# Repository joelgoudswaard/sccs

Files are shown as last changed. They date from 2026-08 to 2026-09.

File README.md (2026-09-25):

<h1>
  SCCS
  The Singularity Camper Control System
</h1>

The SCCS is a control system for the electrics in your caravan or camper trailer. It replaces a switch panel and battery/water gauges etc. with a modern touchscreen UI that provides:
- Automated control of lighting based on sunset/sunrise times and door/panel open and closes.
- Display of important information:
  - Battery level and usage
  - Solar generation
  - Water tank levels
  - Location data
  - outside/fridge temperature and weather forecasts
  - Sonos speakers

The system is made up of a Raspberry Pi and custom PCB, the SCCS Core that is the central hub where all field wiring connects to.

The SCCS software configures the Raspberry Pi as a router so that Internet can be distributed from a USB/Wi-Fi hotspot or Starlink through a downstream WAP, enabling a local Wi-Fi network that gives your devices access to the UI and provides ad-filtered Internet access.

Networking services — NAT, DNS, DHCP, and ad-filtering — are provided by nftables and Pi-hole and configured during installation. That same LAN step installs UniFi OS Server so UniFi access points can be adopted locally at `https://10.10.10.1:11443`. Apple HomeKit and Google Home can be configured to enable voice commands of lighting through Siri or Gemini. Cloudflare Tunnels is supported for remote access to the system while away from the caravan/camper.

An interactive demo is available at [demo.singularityautomation.com.au](https://demo.singularityautomation.com.au).

## Getting started

## Quickstart

1. Order SCCS Core PCB from JLCPCB by uploading the contents of the `/kicad/production` folder to JLCPCB. Get PCBA (assembly) done as well - you will receive a warning during the component placement stage that the same component is mapped to multiple parts. This is intentional, tick the checkboxes to include them in the build and continue.
2. Install wiring and SCCS core.
3. Install the software with the install command:

```bash
curl -fsSL https://raw.githubusercontent.com/joelgoudswaard/sccs/main/install.sh -o /tmp/sccs-install.sh && sudo bash /tmp/sccs-install.sh
```

Full instructions are in the [project wiki](https://github.com/joelgoudswaard/sccs/wiki/).

## System overview

A touchscreen in the kitchen or similar area shows the main user interface and is also reachable from phones or tablets on the LAN:

- Dimmable lighting sliders with red/white anti-bug mode and on/off buttons for non-dimmable loads (water, lighting, fridge circuits)
- Ambient lights that fade on as it gets dark
- One-touch lighting scenes
- Control of Sonos speakers
- Light/dark UI themes and an extensive settings page
- Integration with Apple HomeKit and Google Home

## Display of Environmental information

- Water tank level
- Current temperature and fridge/freezer temperatures
- Current battery charge, voltage, current consumption, estimated power remaining and current/daily solar generation
- GPS coordinates, closest suburb, altitude, satellite quality, sunrise/sunset, and the day/evening/night timing that drives automation
- 4 Day weather forecast, humidity and expected overnight temperature if Internet is present
- Internet connection quality details
- What lights are on and what doors or panels are open
- Health status of connected hardware modules like solar or GPS

## Hardware architecture

- Raspberry Pi 4/5
- Dual ESP32-S3s for 16 channels of PWM dimming via MOSFETs
- u-blox NEO-M9N GPS for location data
- Victron SmartShunt and SmartSolar support for battery and solar monitoring
- WS281X addressable LED strip outputs
- 10A relays for non-dimmable loads like lighting circuits, floodlights and water pumps
- Reed switch inputs for door/panel sensing and triggering of lights
- 1-Wire bus for temperature sensors
- Water tank level sensor input
- Spare channels for everything for expansion

## Hardware and User Interface

### SCCS Core

<table>
  <tr>
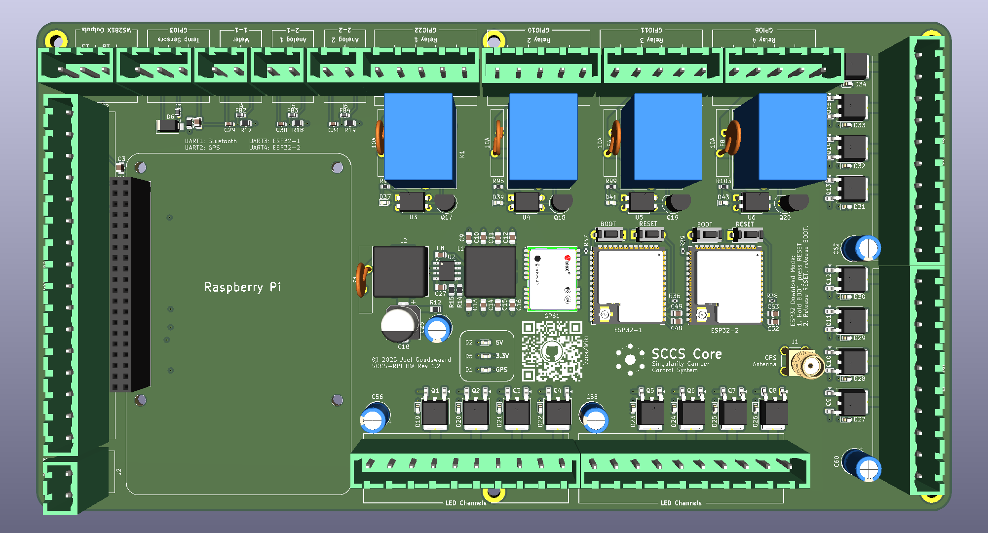
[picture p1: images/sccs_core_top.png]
SCCS Core — top, bare board
    <td align="center" width="50%"></td>
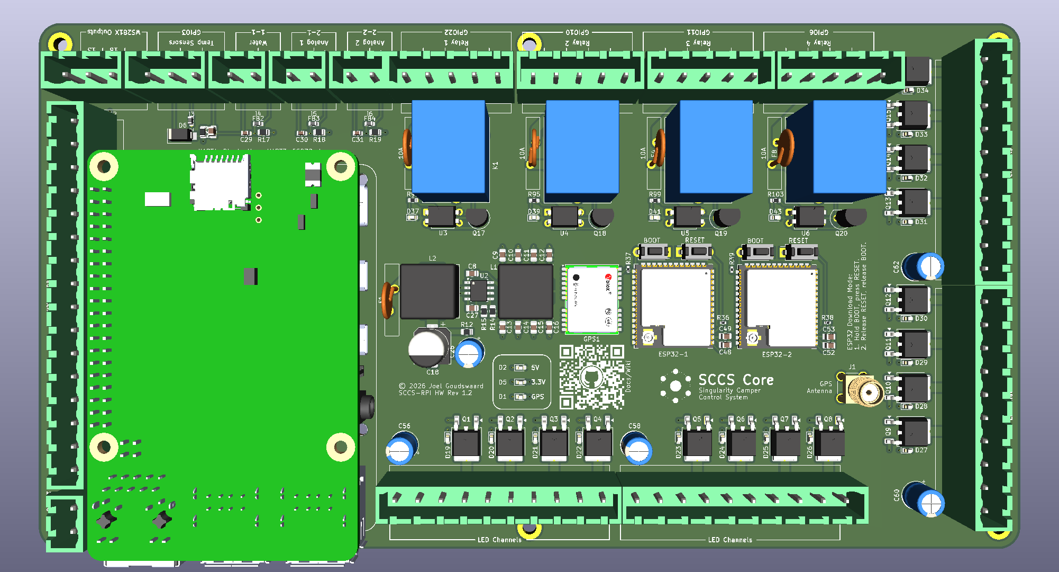
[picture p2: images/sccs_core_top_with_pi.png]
SCCS Core — top, with Raspberry Pi fitted
    <td align="center" width="50%"></td>
  </tr>
  <tr>
    <td align="center"><strong>Top (bare board)</strong></td>
    <td align="center"><strong>Top (with Raspberry Pi fitted)</strong></td>
  </tr>
  <tr>
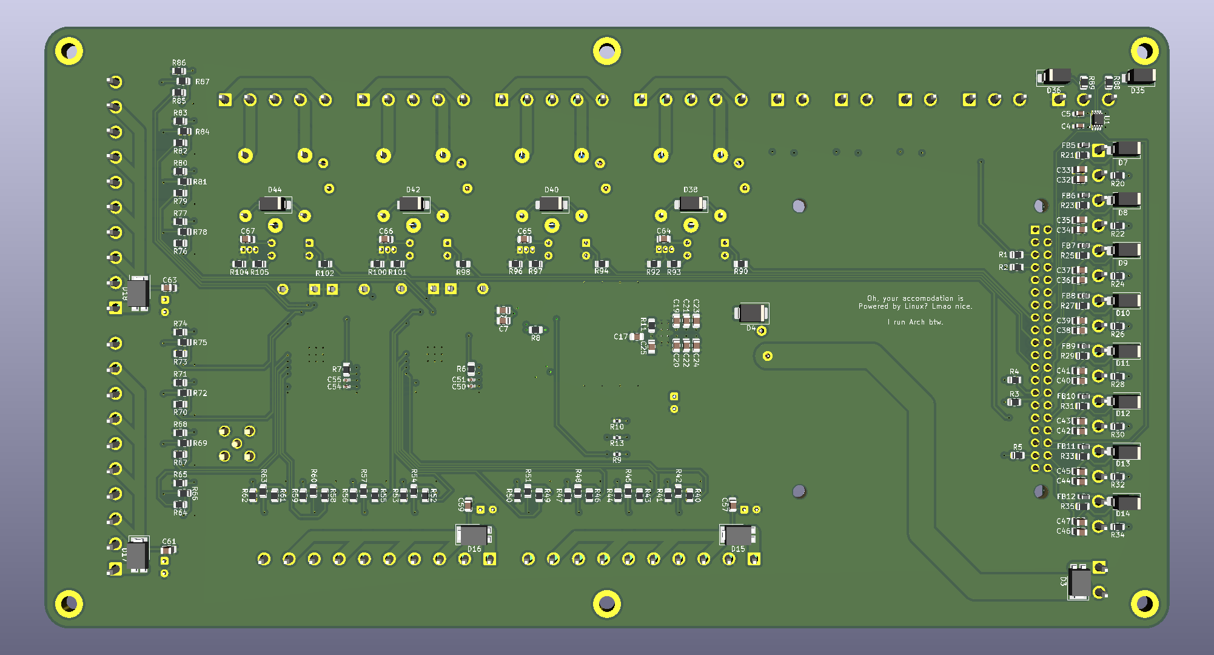
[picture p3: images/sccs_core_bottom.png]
SCCS Core — bottom
    <td align="center"></td>
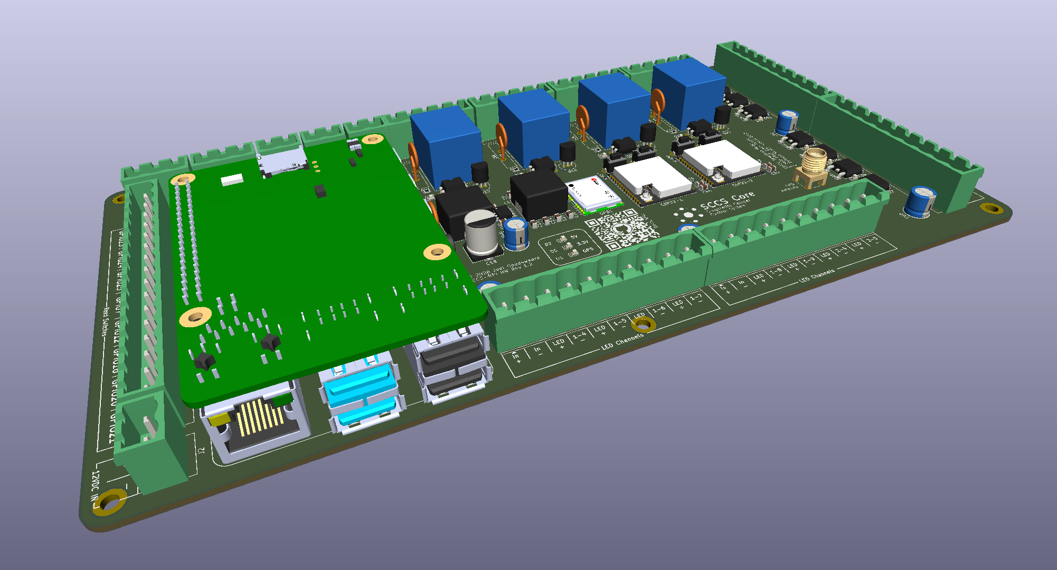
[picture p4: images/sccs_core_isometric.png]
SCCS Core — isometric view with Raspberry Pi fitted
    <td align="center"></td>
  </tr>
  <tr>
    <td align="center"><strong>Bottom</strong></td>
    <td align="center"><strong>Isometric (with Raspberry Pi fitted)</strong></td>
  </tr>
</table>

### 3D Printable Mount

<table>
  <tr>
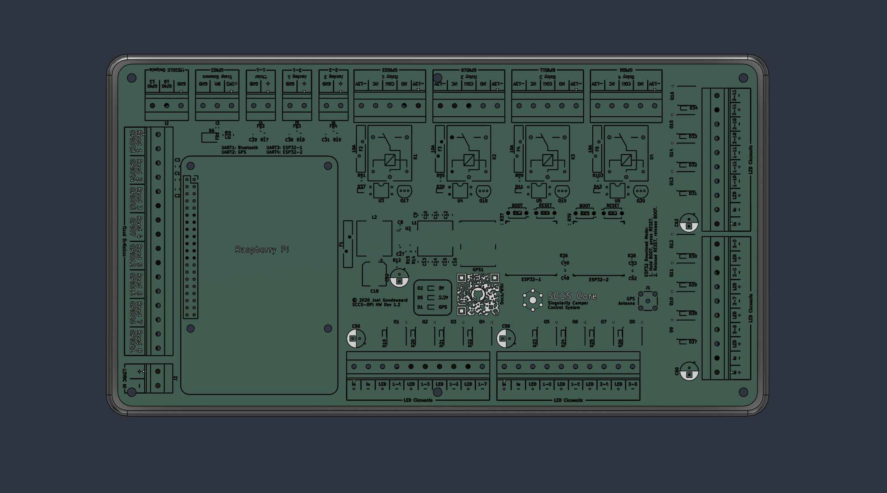
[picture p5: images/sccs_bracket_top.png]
SCCS Core — 3D printable frame, top
    <td align="center" width="50%"></td>
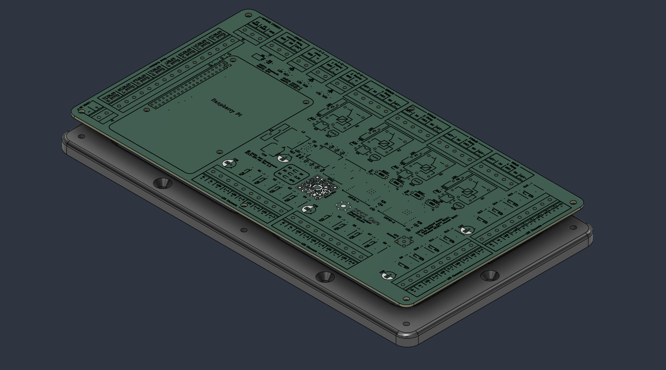
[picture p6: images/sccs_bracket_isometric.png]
SCCS Core — 3D printable frame, isometric
    <td align="center" width="50%"></td>
  </tr>
  <tr>
    <td align="center"><strong>3D printable frame (top)</strong></td>
    <td align="center"><strong>3D printable frame (isometric)</strong></td>
  </tr>
</table>

### User Interface

<table>
  <tr>
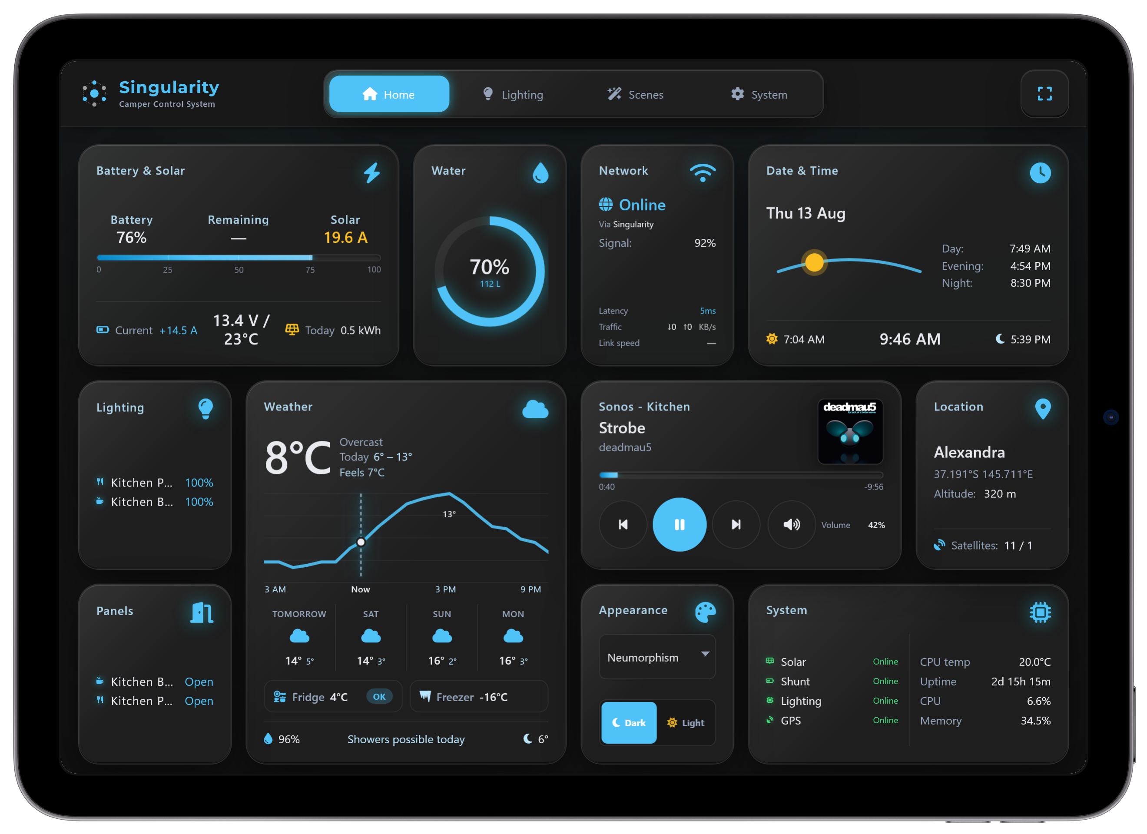
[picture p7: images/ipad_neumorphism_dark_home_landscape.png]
Neumorphism dark — iPad landscape
    <td align="center" width="50%"></td>
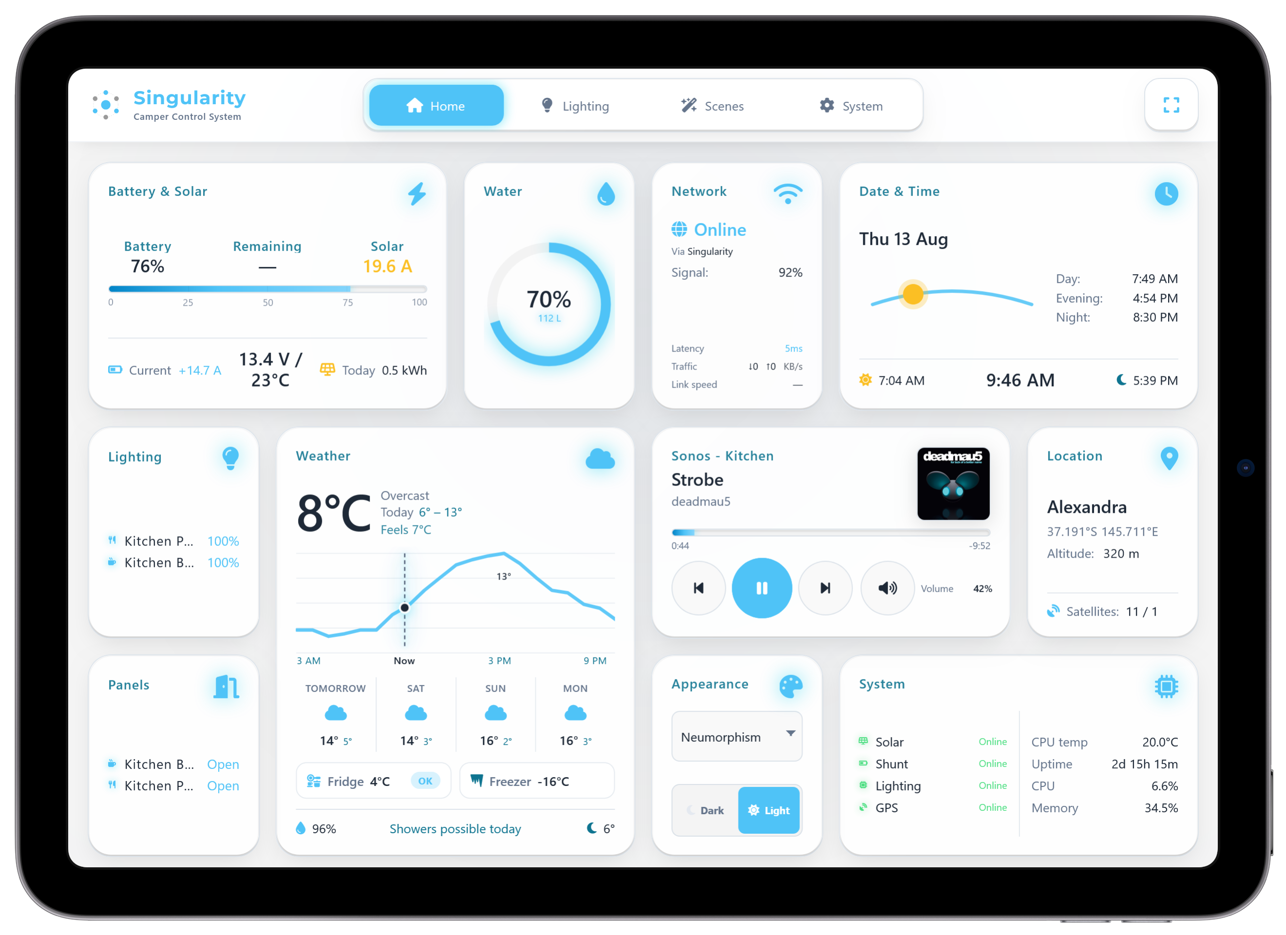
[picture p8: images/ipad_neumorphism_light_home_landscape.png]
Neumorphism light — iPad landscape
    <td align="center" width="50%"></td>
  </tr>
  <tr>
    <td align="center"><strong>Neumorphism (Dark) — iPad</strong></td>
    <td align="center"><strong>Neumorphism (Light) — iPad</strong></td>
  </tr>
  <tr>
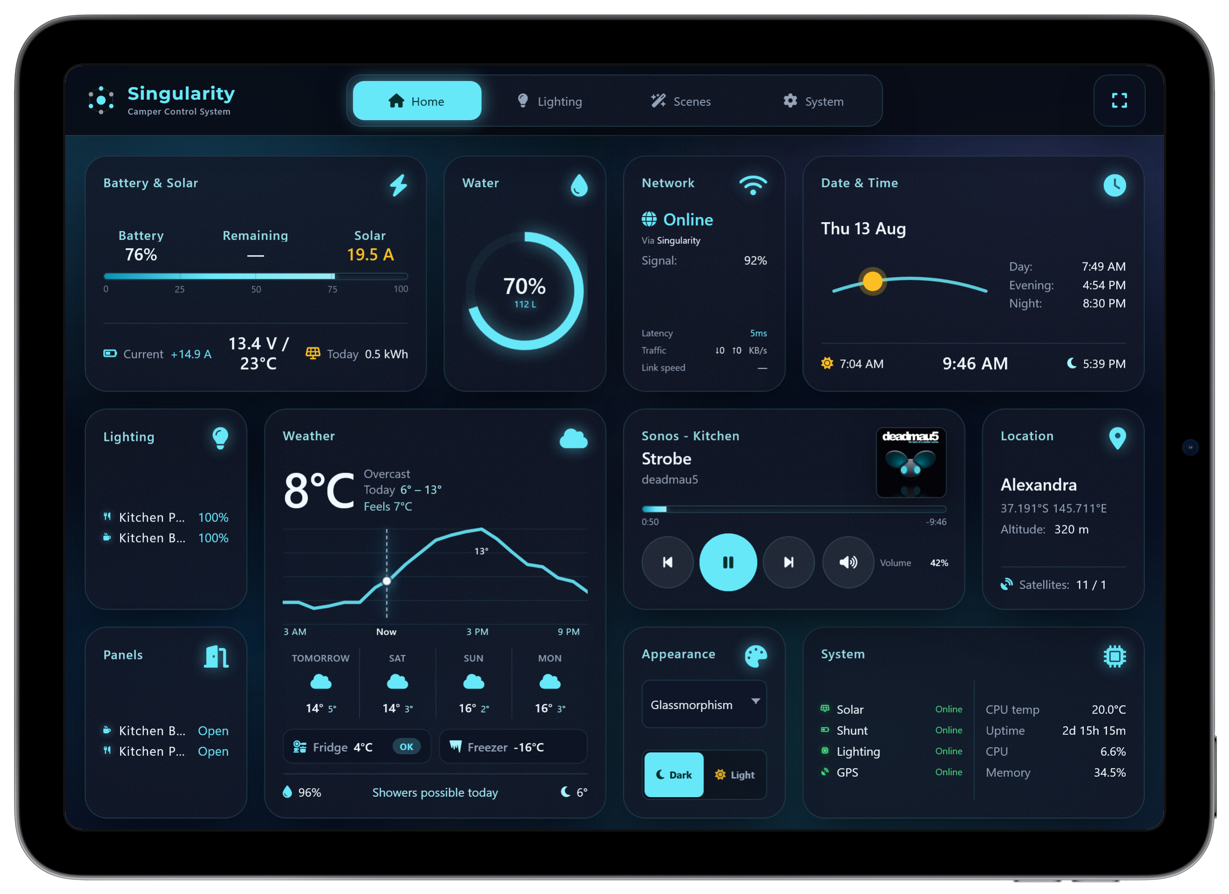
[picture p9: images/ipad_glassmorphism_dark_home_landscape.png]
Glassmorphism dark — iPad landscape
    <td align="center"></td>
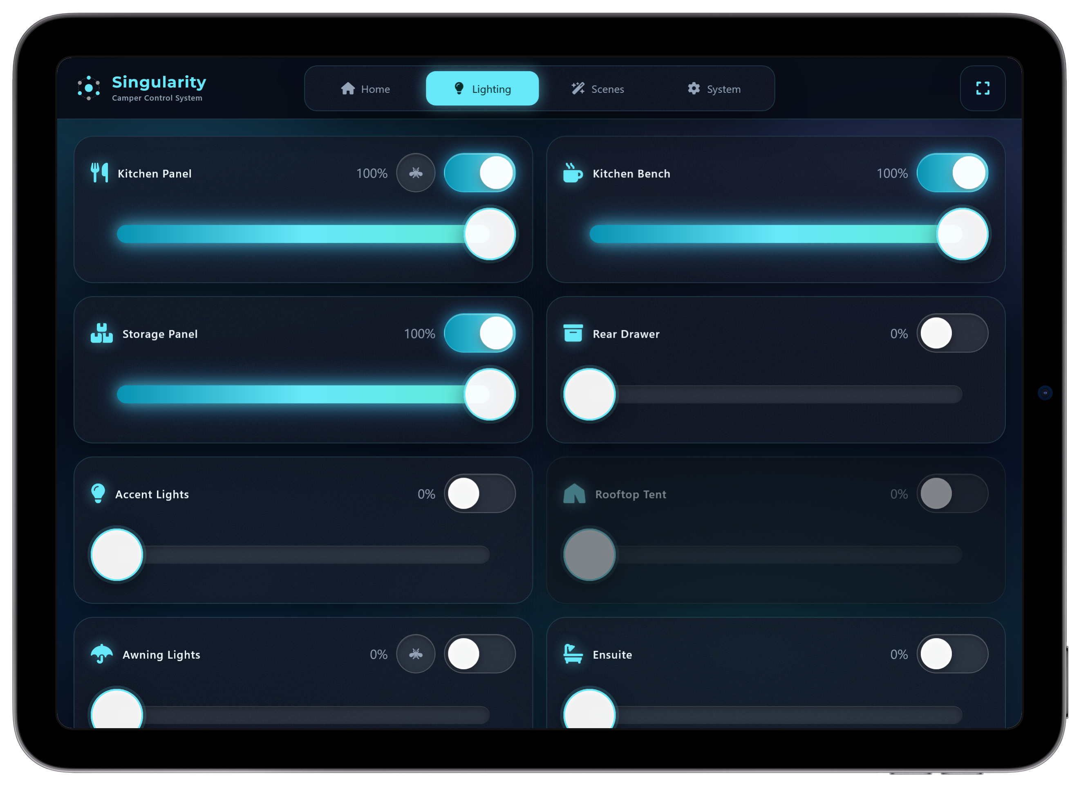
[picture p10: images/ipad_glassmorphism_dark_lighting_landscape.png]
Glassmorphism dark — iPad lighting
    <td align="center"></td>
  </tr>
  <tr>
    <td align="center"><strong>Glassmorphism (Dark) — iPad</strong></td>
    <td align="center"><strong>Glassmorphism (Dark) — iPad Lighting</strong></td>
  </tr>
  <tr>
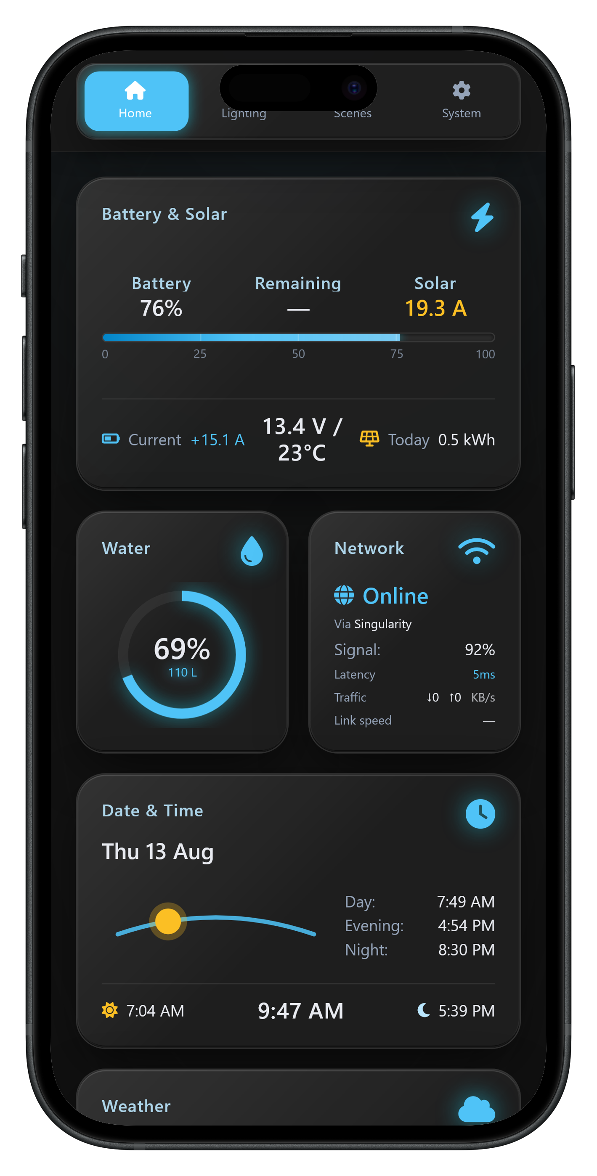
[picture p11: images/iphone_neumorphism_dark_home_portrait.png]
Neumorphism dark — iPhone portrait
    <td align="center"></td>
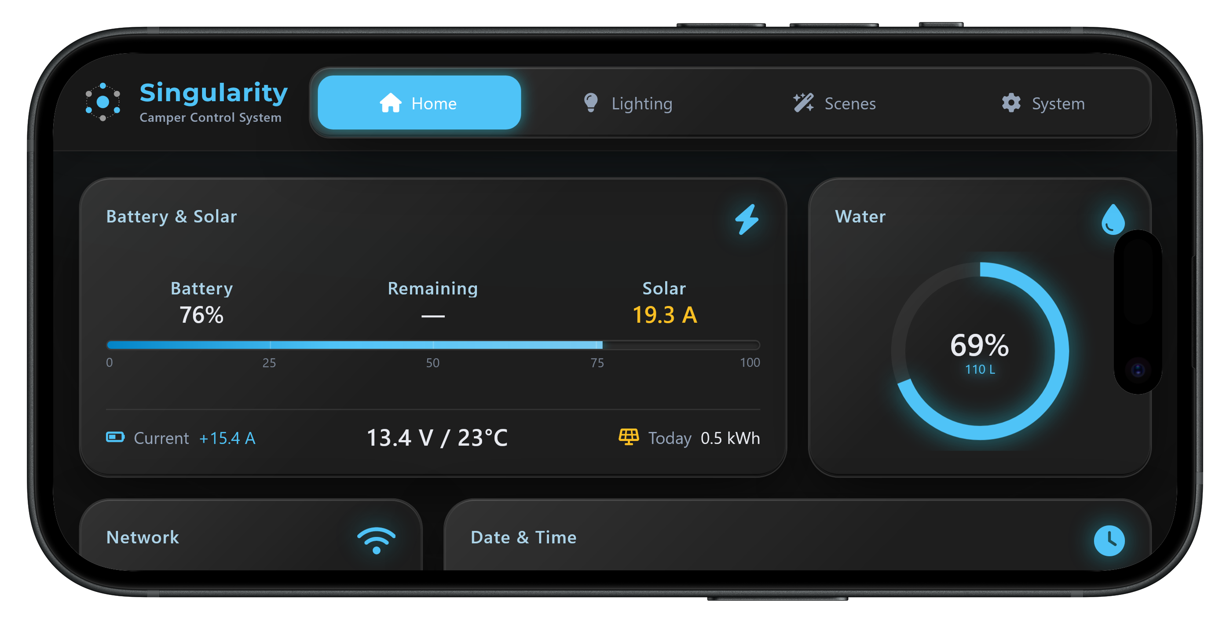
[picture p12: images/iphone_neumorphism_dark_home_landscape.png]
Neumorphism dark — iPhone landscape
    <td align="center"></td>
  </tr>
  <tr>
    <td align="center"><strong>Neumorphism (Dark) — iPhone Portrait</strong></td>
    <td align="center"><strong>Neumorphism (Dark) — iPhone Landscape</strong></td>
  </tr>
</table>

---

## Documentation

Wiring, installation, configuration, and optional packages are on the **[project wiki](https://github.com/joelgoudswaard/sccs/wiki)** (start at [Home](https://github.com/joelgoudswaard/sccs/wiki/Home) for the setup path and glossary).

| Topic | Wiki page |
|---|---|
| Overview, setup path, glossary | [Home](https://github.com/joelgoudswaard/sccs/wiki/Home) |
| Shopping list and wiring | [Wiring and Hardware](https://github.com/joelgoudswaard/sccs/wiki/Wiring-and-Hardware) |
| Imaging the Pi and installer | [Software Installation](https://github.com/joelgoudswaard/sccs/wiki/Software-Installation) |
| `sccs.conf`, phases, lights, sensors | [Software Configuration](https://github.com/joelgoudswaard/sccs/wiki/Software-Configuration) |
| SmartShunt / SmartSolar Bluetooth | [Victron Setup](https://github.com/joelgoudswaard/sccs/wiki/Victron-Setup) |
| Apple Home app / Siri (optional) | [HomeKit](https://github.com/joelgoudswaard/sccs/wiki/HomeKit) |
| Google Home / Gemini (optional) | [Google Home](https://github.com/joelgoudswaard/sccs/wiki/Google-Home) |
| LAN, NAT, Pi-hole, USB internet | [Networking](https://github.com/joelgoudswaard/sccs/wiki/Networking) |
| UniFi controller (optional) | [UniFi OS Server](https://github.com/joelgoudswaard/sccs/wiki/UniFi-OS-Server) |

---

## License

Licensed under the [MIT License](LICENSE).

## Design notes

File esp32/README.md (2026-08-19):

# SCCS ESP32-S3 firmware

ESP32-S3-WROOM-1U firmware for the two lighting/analog MCUs.

Host protocol (UART0, 115200 8N1): `SET` / `RAMP` / `GET` / `ANALOG` / `GETVCC` / `GETALL`.

Same UART as the ROM bootloader, so `BOOT`+`RESET` uploads over the Pi host serial port.

| Sketch | Role | Pi UART | ESP host UART | PWM GPIOs | Analog GPIOs |
|---|---|---|---|---|---|
| `esp32_1/` | ESP32-1 | `/dev/ttyAMA2` (Pi GPIO 4/5) | GPIO 44 RX / 43 TX (U0) | 4–11 | 1 (water) |
| `esp32_2/` | ESP32-2 | `/dev/ttyAMA3` (Pi GPIO 8/9) | GPIO 44 RX / 43 TX (U0) | 4–11 | 1, 2 |

Shared core: `SccsEspFirmware.h` (copied into each sketch folder).

## Build / flash

- Chip: **ESP32-S3** / **ESP32-S3-WROOM-1U**
- Upload over the Pi host UART (U0). Stop `sccs` first so the port is free.
- Hold BOOT, tap RESET, release BOOT, then upload. Tap RESET again to run.

```bash
arduino-cli core update-index
arduino-cli core install esp32:esp32

arduino-cli compile --fqbn esp32:esp32:esp32s3 esp32/esp32_1
arduino-cli upload -p /dev/ttyAMA2 --fqbn esp32:esp32:esp32s3 esp32/esp32_1

arduino-cli compile --fqbn esp32:esp32:esp32s3 esp32/esp32_2
arduino-cli upload -p /dev/ttyAMA3 --fqbn esp32:esp32:esp32s3 esp32/esp32_2
```

## ADC / water level

- 12-bit reads (0–4095), 64-sample average — matches `water_adc_max = 4095` on the Pi
- `GETVCC` returns `3300` (mV of the 3V3 rail for the 150 Ω pull-ups)
- Water sender on ESP32-1 GPIO 1: empty ~240 Ω, full ~33 Ω (`config/sccs.conf` `[sensors]`)

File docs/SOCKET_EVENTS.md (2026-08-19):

# SCCS Socket Event Contract

This document defines every Socket.IO event used by the lighting backend in this pass.

## Offline overlay

When Socket.IO disconnects (or fails to load), `#offline-overlay` appears after 800ms and blocks interaction until reconnect. Implemented in `offline-overlay.js` + `socket-client.js`.

## Client → Server

### `light_change`

User moved a dimmer slider or toggled a dimmer pill.

```json
{ "name": "kitchen_bench", "brightness": 65 }
```

RGB bug lights include mode:

```json
{ "name": "kitchen_panel", "brightness": 55, "mode": "red" }
```

- `name` must be in `compiled.light_names`
- `brightness` clamped 0–100 server-side
- `mode` only applied for RGB lights

**HTTP fallback:** `POST /api/light` with the same JSON body.

### `relay_change`

User toggled a relay control (socket only — no HTTP fallback).

```json
{ "name": "floodlights", "on": true }
```

Relays use `expires: manual` — they persist through scenes, reed changes, and phase changes until toggled again.

### `get_reeds`

Request effective reed states. Server replies with `reed_update`.

### `set_scene`

Activate a lighting scene (one-shot reconcile with ramp).

```json
{ "scene": "bedtime" }
```

**HTTP fallback:** `POST /api/scene` with the same JSON body.

### `force_phase`

Lock or clear phase override.

```json
{ "phase": "Evening" }
```

Clear: `{ "phase": null }`

### `force_reed`

Diagnostics override (also affects main UI effective states).

```json
{ "name": "rooftop_tent", "closed": true }
```

Clear force: `{ "name": "rooftop_tent", "closed": null }`

## Server → Client

### `lights_config`

Sent on `connect`. Ordered list of UI controls from `sccs.conf`:

```json
[
  { "name": "rooftop_tent", "label": "Rooftop Tent", "type": "dimmer", "icon": "fa-tent", "has_mode": false, "order": 10 }
]
```

`type` is `dimmer` or `relay`.

### `state_update`

Authoritative light/relay levels after reconcile.

```json
{
  "kitchen_bench": 65,
  "kitchen_panel": 55,
  "kitchen_panel_mode": "white",
  "floodlights": 1
}
```

- Dimmers: 0–100 integer brightness
- Relays: truthy/falsey on state
- RGB lights: `{name}_mode` key with `white` or `red`

### `reeds_config`

Sent on `connect`. Reed metadata for the system tile:

```json
[{ "name": "kitchen_panel", "label": "Kitchen Panel", "icon": "fa-utensils", "order": 10 }]
```

### `reed_update` (main UI)

Effective reed states — hardware merged with operator forces.

```json
{ "states": { "rooftop_tent": true, "kitchen_bench": false } }
```

`true` = closed (secure), `false` = open.

**Main UI rule:** clients must not guess forced vs raw. Use this event only.

### `reed_diag_update` (diagnostics — future tile)

Raw hardware + force metadata. Not consumed by the lighting tab yet.

```json
{
  "states": { "rooftop_tent": true },
  "forced": { "kitchen_bench": false }
}
```

### `phase_update` (main UI)

```json
{ "phase": "evening", "day_start": "06:12", "evening_start": "18:45", "night_start": "21:30" }
```

### `gps_update`

Full GPS telemetry from `modules/gps` (also drives home location tile).

```json
{
  "fix_quality": 2,
  "satellites": 9,
  "latitude": -37.191,
  "longitude": 145.711,
  "suburb": "Alexandra",
  "hardware_missing": false
}
```

### `sensor_update`

Water tank and 1-wire temperatures.

```json
{
  "water_percent": 68,
  "outside_temp_c": 12.4,
  "fridge_temp_c": null,
  "temp_valid": true
}
```

### `set_gps_simulation`

Diagnostics: force no-fix mode.

```json
{ "no_fix": true }
```

### `phase_diag_update` (diagnostics)

```json
{ "forced": false }
```

`forced: true` when operator has locked phase via diag controls.

## REST

| Route | Purpose |
|---|---|
| `POST /api/light` | HTTP fallback for `light_change` |
| `GET /api/scenes` | Scene list for Scenes tab |
| `POST /api/scene` | HTTP fallback for `set_scene` |
| `GET /api/reeds` | Reed labels/icons for system tile |
| `GET /api/explain` | Policy snapshot: sources, desired vs observed, drift |

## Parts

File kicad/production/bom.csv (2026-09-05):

Designator | Footprint | Quantity | Value | LCSC Part #
C1, C10 | 0805 | 2 | 10uF | C15850
C11, C17, C2, C22, C24, C26, C28, C30, C32, C34, C36, C46, C48, C50, C52, C53, C54, C55, C56, C8 | 0805 | 20 | 100nF | C49678
C12, C13, C14, C15, C3, C37, C41, C58, C59, C6, C60, C61, C62, C63, C64, C65, C70, C71, C72, C73, C74, C75, C76, C77 | 0805 | 24 | 22uF | C86816
C16, C45, C47, C49, C51 | CP_Radial_D6.3mm_P2.50mm | 5 | 100uF | C44587
C18, C19, C20, C4, C5 | 0603 | 5 | 100nF | C1590
C21, C23, C25, C27, C29, C31, C33, C35 | 0805 | 8 | 1uF | C91185
C38, C42, C57, C69, C7 | 0805 | 5 | 0.1uF | C86041
C39, C40, C43, C44 | 0402 | 4 | 100nF | C60474
C66, C78 | 0805 | 2 | 2.7nF | C113859
C67, C79 | 0805 | 2 | 33pF | C541516
C68, C80 | 0805 | 2 | 10nF | C237168
C9 | CP_Elec_8x10 | 1 | 220uF | C165536
D1 | 0402 | 1 | ESD103-B1-02EL | C535146
D10, D11, D12, D13, D14, D15, D7, D8, D9 | D_SMA | 9 | SMAJ3.3CA | C18199545
D16, D17, D18, D19, D4 | D_PowerDI-5 | 5 | ~ | C2759901
D2 | 0603 | 1 | GPS | C2286
D20, D23, D24, D25, D26, D27, D28, D31, D32, D33, D34, D35 | 0603 | 12 | White | C2290
D21, D29 | 0603 | 2 | Red | C2286
D22, D30 | 0603 | 2 | Green | C12065
D3 | 0603 | 1 | 5V | C2286
D36, D37 | D_SMA | 2 | SMAJ5.0CA | C78402
D38, D40, D42, D44 | 0603 | 4 | Blue | C2288
D39, D41, D43, D45 | D_SMA | 4 | 1N4007 | C64915
D5 | D_SMB | 1 | SMAJ18A/TR13 | C571369
D6 | 0603 | 1 | 3.3V | C2286
ESP32-1, ESP32-2 | ESP32-S3-WROOM-1U | 2 | ESP32-S3-WROOM-1 | C3013946
F1, F2, F3, F4, F5 | Fuse_Bourns_MF-RG1000 | 5 | A16-1000 10A | C135398
FB1, FB10, FB11, FB12, FB2, FB3, FB4, FB5, FB6, FB7, FB8, FB9 | 0603 | 12 | FerriteBead | C1002
GPS1 | ublox_NEO | 1 | NEO-M9N-00B | C5119087
I1 | TerminalBlock_Phoenix_MKDS-1,5-16-5.08_1x16_P5.08mm_Horizontal | 1 | Reed Switches | C508906
I2 | TerminalBlock_Phoenix_MKDS-1,5-3-5.08_1x03_P5.08mm_Horizontal | 1 | WS281X Outputs | C8412
I3 | TerminalBlock_Phoenix_MKDS-1,5-3-5.08_1x03_P5.08mm_Horizontal | 1 | Temp Sensors | C8412
I4 | TerminalBlock_Phoenix_MKDS-1,5-2-5.08_1x02_P5.08mm_Horizontal | 1 | Water | C8445
I5 | TerminalBlock_Phoenix_MKDS-1,5-2-5.08_1x02_P5.08mm_Horizontal | 1 | Analog 1 | C8445
I6 | TerminalBlock_Phoenix_MKDS-1,5-2-5.08_1x02_P5.08mm_Horizontal | 1 | Analog 2 | C8445
J1 | SMA_Amphenol_132134-11_Vertical | 1 | Conn_Coaxial | C20415804
J2 | TerminalBlock_Phoenix_MKDS-1,5-2-5.08_1x02_P5.08mm_Horizontal | 1 | 12VDC IN | C8445
K1, K2, K3, K4 | Relay_SPDT_SANYOU_SRD_Series_Form_C | 4 | Relay_SPDT | C35449
L1 | 0603 | 1 | 27nH | C162550
L2, L3, L4 | L_SXN_SMDRI127 | 3 | 3.3uH | C24550
PI1 | PinSocket_2x20_P2.54mm_Vertical | 1 | Raspberry PI HAT | C132132
PWM1, PWM2, PWM3, PWM4 | TerminalBlock_Phoenix_MKDS-1,5-10-5.08_1x10_P5.08mm_Horizontal | 4 | LED Channels | C29173
Q1, Q10, Q11, Q12, Q13, Q14, Q15, Q16, Q2, Q3, Q4, Q5, Q6, Q7, Q8, Q9 | TO-252-2 | 16 | IRLR7843 | C21988
Q17, Q18, Q19, Q20 | TO-92_Inline | 4 | 2N7000 | C9114
R1, R19, R2, R21, R23, R25, R27, R29, R3, R31, R33, R4, R6, R7, R9 | 0805 | 15 | 220R | C17557
R10, R11, R13 | 0402 | 3 | 1K | C11702
R100, R88, R92, R96 | 0805 | 4 | 330R | C17630
R101, R89, R93, R97 | 0603 | 4 | 1K | C5123612
R102, R39, R42, R45, R48, R51, R54, R57, R60, R63, R66, R69, R72, R75, R78, R81, R84, R90, R94, R98 | 0805 | 20 | 10K | C17414
R103, R38, R41, R44, R47, R50, R53, R56, R59, R62, R65, R68, R71, R74, R77, R80, R83, R91, R95, R99 | 0805 | 20 | 100R | C17408
R104, R107 | 0805 | 2 | 15.8K | C17468
R105 | 0805 | 1 | 115K | C158272
R106 | 0805 | 1 | 22.1K | C17552
R108 | 0805 | 1 | 100K | C5123589
R109 | 0805 | 1 | 32.4K | C36938
R12 | 0805 | 1 | 1R | C25271
R14 | 0805 | 1 | 2.2K | C17520
R15, R16, R17 | 0805 | 3 | 150R | C17471
R18, R20, R22, R24, R26, R28, R30, R32, R5 | 0805 | 9 | 4.7K | C17673
R34, R35, R36, R37 | 0402 | 4 | 10K | C60490
R40, R43, R46, R49, R52, R55, R58, R61, R64, R67, R70, R73, R76, R79, R82, R85 | 0805 | 16 | 1K | C17513
R8 | 0805 | 1 | 10R | C17415
R86, R87 | 0805 | 2 | 33R | C17634
RE1 | TerminalBlock_Phoenix_MKDS-3-5-5.08_1x05_P5.08mm_Horizontal | 1 | Relay 1 | C8423
RE2 | TerminalBlock_Phoenix_MKDS-3-5-5.08_1x05_P5.08mm_Horizontal | 1 | Relay 2 | C8423
RE3 | TerminalBlock_Phoenix_MKDS-3-5-5.08_1x05_P5.08mm_Horizontal | 1 | Relay 3 | C8423
RE4 | TerminalBlock_Phoenix_MKDS-3-5-5.08_1x05_P5.08mm_Horizontal | 1 | Relay 4 | C8423
RP? | raspberrypi_4 | 1 | Raspberry_Pi_2_3
SW1, SW3 | SW_PUSH_1P1T_6x3.5mm_H5.0_APEM_MJTP1250 | 2 | RESET | C500070
SW2, SW4 | SW_PUSH_1P1T_6x3.5mm_H5.0_APEM_MJTP1250 | 2 | BOOT | C500070
U1 | VSSOP-8_2.3x2mm_P0.5mm | 1 | SN74LVC2T45DCUR | C15741
U2, U3, U4, U5 | DIP-4_W7.62mm | 4 | PC817 | C5353
U6, U7 | SOIC-8-1EP_3.9x4.9mm_P1.27mm_EP2.95x4.9mm_Mask2.71x3.4mm_ThermalVias | 2 | AP64501SP-13 | C2071517

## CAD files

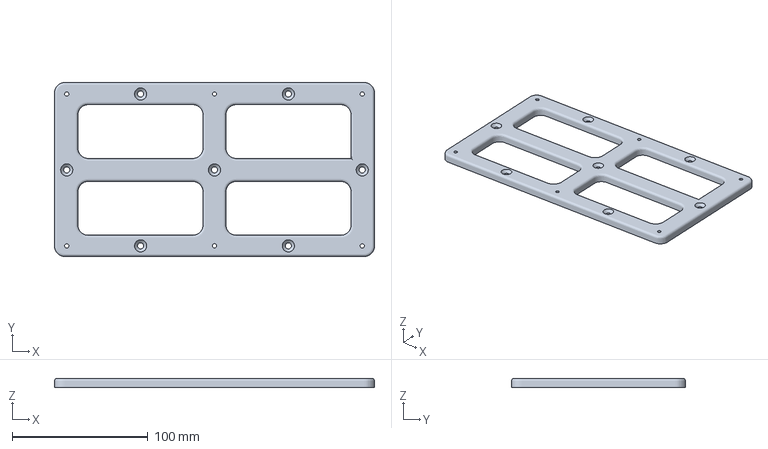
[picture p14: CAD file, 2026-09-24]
kicad/SCCS Bracket.3mf
236.1 x 128.4 x 7.00 mm

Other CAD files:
kicad/SCCS Bracket.f3z

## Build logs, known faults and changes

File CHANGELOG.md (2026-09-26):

# Changelog

All notable changes to SCCS are documented in this file.

## [1.2.0.26092026] - 2026-09-26

### Added
- Update (menu 2 / `--update`) checks UniFi OS Server against Ubiquiti's release feed and runs the official installer when a newer version is published. An install that is already current is left alone. The controller restarts during the upgrade; adopted access points and the Podman volumes stay. The container DNS fix is applied again afterwards.
- Touchscreen setup logs the panel account into the desktop at boot on Raspberry Pi OS and Armbian. Raspberry Pi OS uses desktop autologin. Armbian uses LightDM, SDDM, GDM, or greetd, whichever is installed. The account password is unchanged, and the login applies on the next boot.
- Touchscreen setup turns off idle display power saving on Raspberry Pi OS and Armbian. The panel no longer blanks, dims, or sleeps after a period with no input. Brightness from the reed and the time of day is unchanged. Armbian KDE Plasma is included. Menu 8 applies desktop login, the Chromium homepage, and idle-power off to every touchscreen already in the config.

### Fixed
- Kitchen touchscreen setup writes `kscreen:HDMI-A-1` as the power path. The panel turns fully on when the kitchen panel reed opens and off when it closes. The installer was storing the KDE brightness control, which only dimmed the screen through the day (100%), evening (30%), and night (5%).
- Each touchscreen card has a "Change Brightness with Phases" checkbox. Off, an open reed leaves the panel fully on. On, it uses that screen's day, evening, and night levels (kitchen: 100 / 30 / 5). The choice is saved in `sccs.conf`.
- Kitchen bench night is 10% red. It was off.
- Dragging a lighting slider thumb no longer opens the browser right-click menu. A press on the thumb is a drag.
- Neumorphism cards keep the halfway highlight. Panel Chromium composites on the GPU and rasterizes on the CPU, so that gradient stays a smooth ramp and page and fullscreen changes are not a two-frame jump. The Neumorphism tile blur is off; the tiles are already nearly opaque, and the blur was re-painted on every fade.
- Closing the kitchen panel reed powers the touchscreen off. Brightness 0% only dimmed it. Wake turns the panel back on at the phase brightness.
- After a reboot the van LAN address could sit on the iPhone USB tether instead of the touchscreen port. Pi-hole then had nothing to lease from, so the panel came up with no address. The LAN profile is now pinned to that port’s name and MAC, and a phone tether is never treated as the van LAN.
- Victron setup offers the enrolled SmartShunt and MPPT Instant Readout keys as suggestions. Press Enter to use that device's key, or type 1 or 2. Those keys are the defaults in a new install.
- Touchscreen setup saves the panel account password in ~/.sccs/screen_credentials (mode 600). Later setup and package updates reuse it. The password is not written into sccs.conf. SSH itself still uses the key.
- Setup reads GPIO26, the SCCS Core presence pull-up (header pin 37, R5 to 3.3V). When that pin is high it skips the “is this Pi on the SCCS Core?” question and asks to proceed.
- Date & Time sunrise and sunset icons are half the height of the label and time together, and stay centered on those two lines.
- The home Lighting tile lists dimmable lights that are on, then a horizontal line, then relays that are on.
- The first touchscreen scan after Pi-hole DHCP is installed asks for every panel to be restarted, then waits for confirmation before detection. Panels that were already on have no address from the new server until they boot again.
- Install questions for the SCCS Core, Victron, phone USB tethering, touchscreens, and HomeKit or Google Home default to yes.
- Voice setup asks whether to install Apple HomeKit / Siri or Google Home / Gemini, then which one: HomeKit, Google, or both. HomeKit installs on its own. Node.js and the Matter bridge install when Google Home is chosen.
- HomeKit and Google Home pairing copy now says to use your iPhone or Android instead of the van Wi‑Fi.
- Date & Time sunrise and sunset labels now start in line with the time, and the sun and moon icons span that label and the time.
- Configuring temperature sensors or touchscreens left the running service on the old `sccs.conf` until something else restarted it. Those steps now restart `sccs.service` when it is already running, after the config for that step is saved.
- First-run ESP32 flashing waited on `/dev/ttyAMA2` and `/dev/ttyAMA3` before the UART overlays were active, so the chips were not detected until the Pi was restarted. The installer now loads those overlays on the running system, and when the kernel only creates the ports at startup it restarts and continues the install instead of asking for the BOOT button.
- A mismatched Samba password confirmation ended the share setup. The installer asks again until the two entries match, or both are left blank to skip.
- Victron setup saved a MAC and Instant Readout key without checking them. The installer now listens for each device, prints a live reading when the key decrypts, and offers to retype the credentials when the key does not match or the device is not heard.
- Touchscreen scan listed every LAN client. It now keeps hosts whose SSH banner is Debian, Ubuntu, Raspbian, or Armbian. A new panel's suggested internal name is `kitchen` and its friendly name is `Kitchen Touchscreen`.
- Panel SSH setup could reject a correct password: the setup script was passed on sudo's stdin, so ssh read that text instead of the password, and the password prompt itself was not taken from the terminal. The script is now a file, ssh is detached from the terminal, and the password is read from the keyboard.
- Temperature-sensor assignment ran before the 1-Wire bus existed, so a first install skipped it without asking. The bus is brought up first, the step asks to scan again when nothing is present, and it runs after the boot overlays are in place.
- Default lighting map: kitchen bench is bug-mode on 1-7 white, 1-8 red, 1-9 green. Accent is 1-10, rear drawer 1-11, storage panel 2-4, rooftop tent 2-5. Relays are Floodlights (GPIO22), Water (GPIO10), Lights (GPIO11), and Fridge/Oven (GPIO6).
- The date tile moon started on the right when Evening began. Evening starts before sunset, and the moon was still on the daytime arc until sunset, then jumped to the left. It now starts on the left at evening and walks toward midnight at the crest.
- Date & Time footer shows Sunrise and Sunset above those times.
- Startup turns the Lights relay on when any dimmer is already on, or when startup is about to turn one on. The relay GPIOs come up off, so those lights would otherwise have no power.
- While running, a change from every dimmer off to any light on also turns the Lights relay on. `lighting_relay_on_with_lights` in `[lighting]` controls this and the startup behavior. Default is on.
- Dragging a dimmer to a new level could leave the lights there while the slider jumped back. The UI treats the reply as an animation and was applying that animation on top of the level just set; a drag now stays put until a phase, reed, or scene change moves it.
- On a 1280×800 touchscreen the home lighting list grew the page. Lighting is two columns wide and lists its lights in two columns; System is one column, without the host-status column, so the three rows stay on the screen.
- In the two-column lighting layout the last two relays (Lights and Fridge/Oven) were left as separate tiles, so Fridge/Oven wrapped onto its own row. They stack in one tile, beside Floodlights and Water.
- The home Network tile named the Wi-Fi network whenever it was associated, even when the default route was the USB hotspot. It now names the path that is actually carrying traffic.
- Victron setup listens for Instant Readout and fills in the Bluetooth address for a single SmartShunt and a single MPPT. The 32-character key still has to be pasted from VictronConnect; it is not in the broadcast.
- A new install prefers Wi-Fi for internet. Phone USB tethering is still set up when asked, as the fallback route.
- On the two- and three-column System page, SCCS Core no longer draws platform names over their values: memory and platform each use the full tile width, and long values stay in their own column. Night’s start time lines up with the Day and Evening fields.

## [1.1.2.18082026] - 2026-08-18

### Added
- Installer 1-Wire setup can delete a temperature sensor role from `sccs.conf`; skip still leaves the existing value

## [1.1.1.18082026] - 2026-08-18

### Fixed
- Startup treated every reed as closed until the poller started, so the first lighting pass and a connecting UI could show “all panels closed”. Reeds are now sampled (three quick GPIO reads) before HTTP is advertised and before any lights or scenes run
- No-fix GPS sentences were stored as 0°N 0°E. Weather then fetched the equator (~24 °C). Empty GGA/RMC is ignored; with no valid fix the Alexandra fallback is used
- pynmea2 raised on void RMC datetime (`$GNRMC,,V,…`); those sentences no longer crash the GPS reader
- Settings tiles with `[hidden]` still painted in WebKit because author `display:flex` beat the UA rule

### Changed
- `[reeds]` comments map i1 pin pairs to functions; kitchen bench is GPIO23 and kitchen panel GPIO24
- Night bathroom scene renamed from `ensuite` to `bathroom`

## [1.1.17082026] - 2026-08-17

### Fixed
- ESP32 lighting stayed offline after a successful flash: the host protocol now uses UART0 (`Serial0` on GPIO 44/43), the same pins as the ROM bootloader, instead of a second `HardwareSerial(0)` on UART1
- Installer flashed over `/dev/ttyACM*` instead of the SCCS Core host UARTs; uploads now target `/dev/ttyAMA2` (ESP32-1) and `/dev/ttyAMA3` (ESP32-2) as the same user that compiled
- A failed `GETVCC` check after upload sent the installer back through the ESP32-1 flash loop. Handshake retries no longer re-flash; the next module is offered after a warning
- `USBMode=default` selected TinyUSB OTG (not the board default) and could hang `setup()` on modules with no USB. The FQBN stays `esp32:esp32:esp32s3`
- Pi UART has no RTS reset line, so esptool cannot start the app. The installer now asks for a RESET tap and checks `GETVCC` before moving on
- `sccs.service` is stopped for the upload and started again when the ESP step ends (including skip, abort, or Ctrl-C)
- Host `GETVCC` probe retries briefly after open so lighting can come online while firmware is still leaving reset

### Changed
- Installer enables the correct UART overlays per board: `uart2`/`uart3`/`uart4` on Pi 4, `uart1-pi5`/`uart2-pi5`/`uart3-pi5` on Pi 5 (GPS `/dev/ttyAMA1`, ESP1 `/dev/ttyAMA2`, ESP2 `/dev/ttyAMA3`)
- Firmware answers the host on a non-blocking line reader and prints `SCCS n READY` as soon as UART0 is up

## [1.0.0.13082026] - 2026-08-13

### Added
- Initial release of the Singularity Camper Control System (SCCS)
- Touchscreen UI for dimmable lighting, scenes, reeds, phases, water, climate, power, GPS, weather and networking
- Optional Apple HomeKit and Google Home control (off by default; installer menu 10 or Settings)
- Installer for imaging, Victron, LAN/Pi-hole, USB tethering and touchscreens

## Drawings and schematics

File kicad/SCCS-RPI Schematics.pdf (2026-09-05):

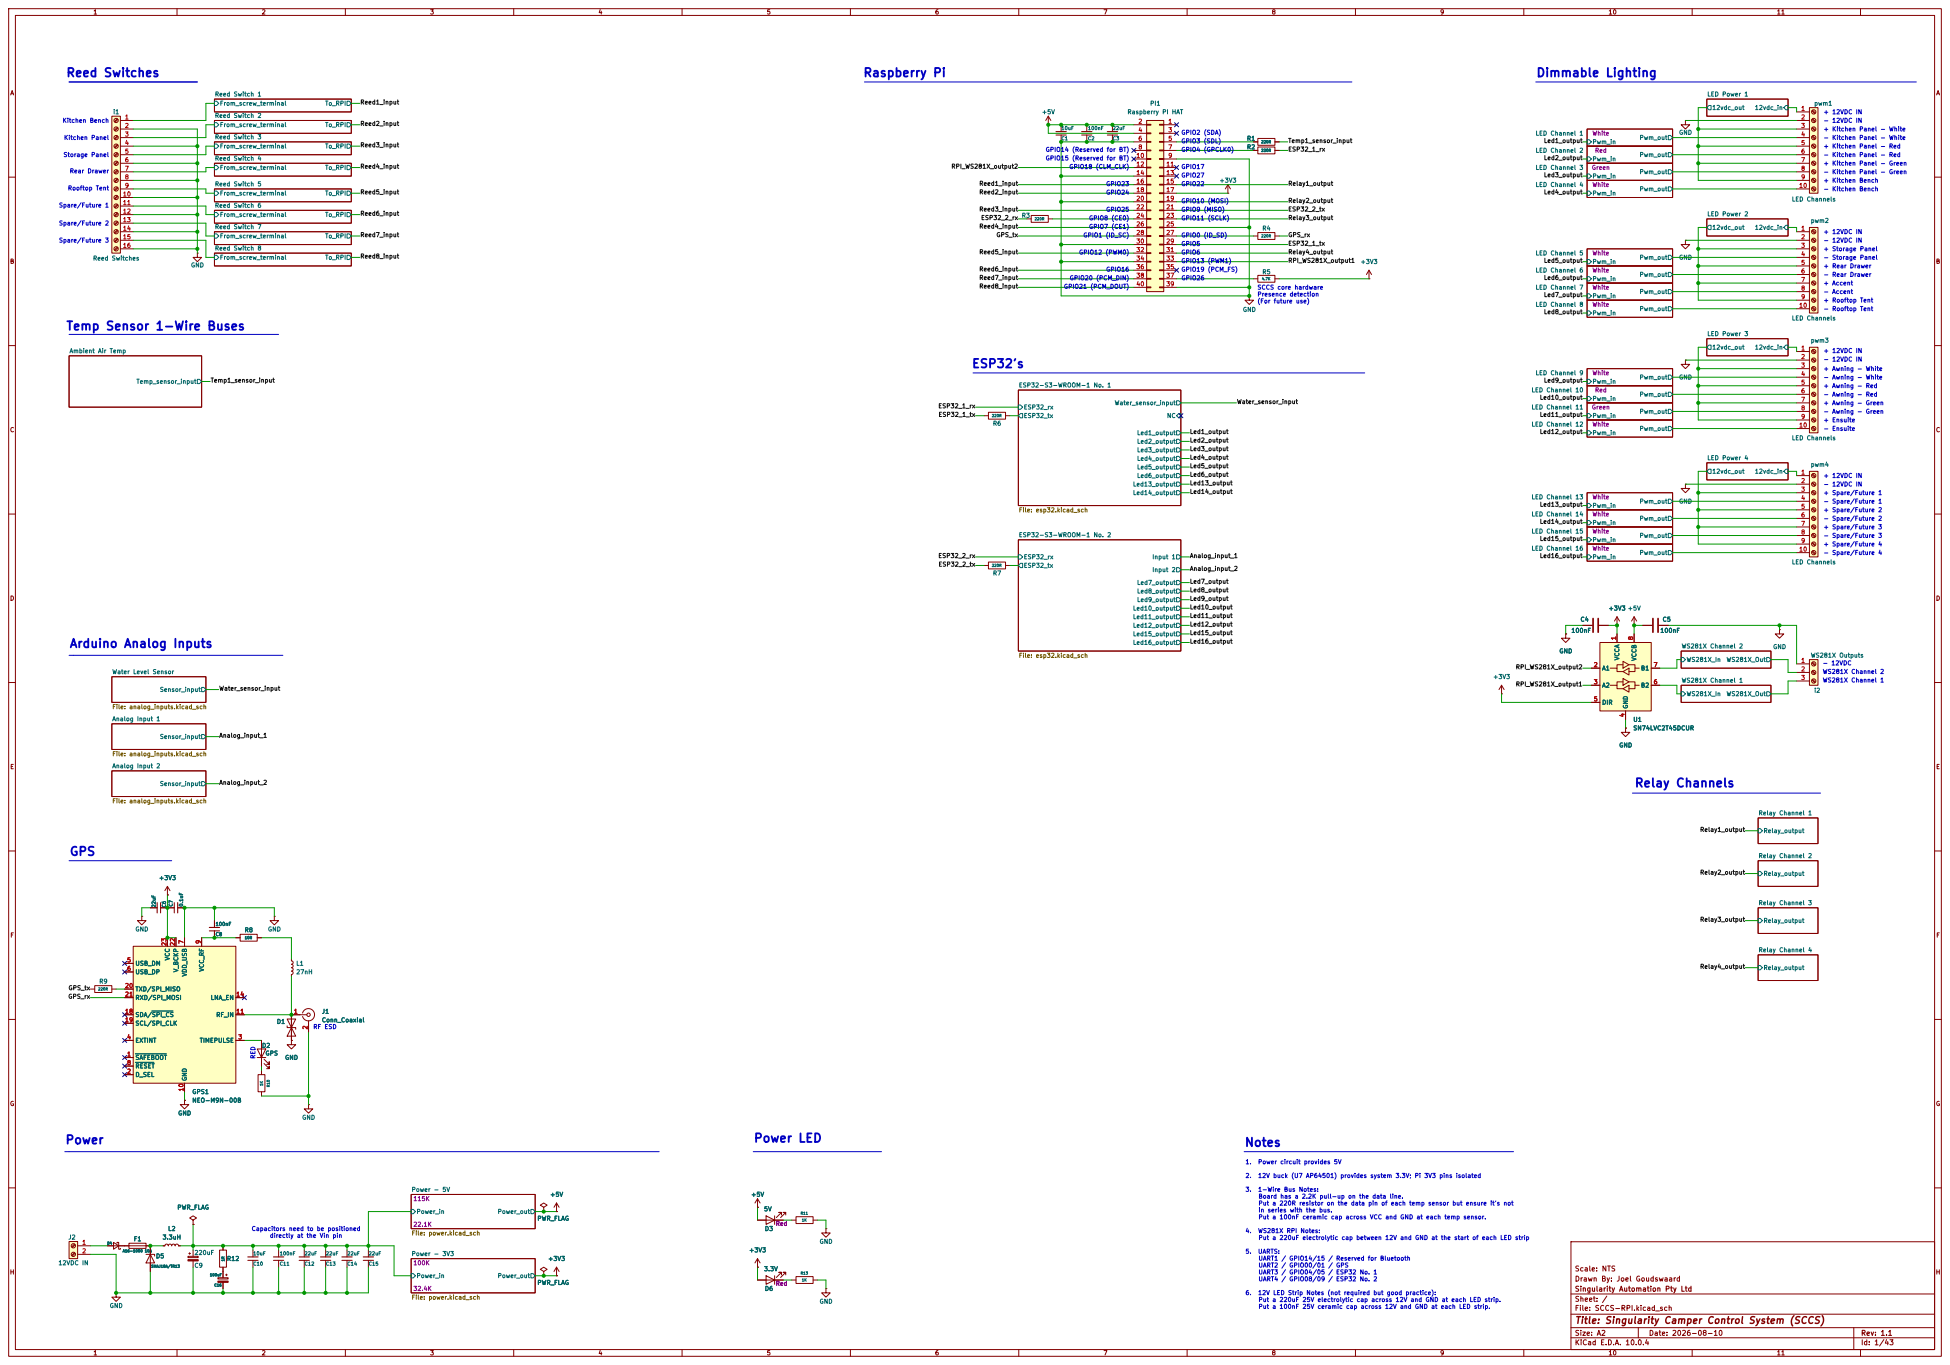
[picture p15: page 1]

Dimmable Lighting
- 12VDC IN + 12VDC IN - Kitchen Panel - White + Spare/Future 1 Relay Channels

+ Kitchen Panel - White + Kitchen Panel - Red - Kitchen Panel - Red + 12VDC IN - Kitchen Panel - Green - Kitchen Bench

GPIO15 (Reserved for BT) GPIO14 (Reserved for BT)

SCCS core hardware Presence detection

+ Spare/Future 3 - Spare/Future 2

Sensor_input Water Level Sensor File: analog_inputs.kicad_sch

1. Power circuit provides 5V 2. 12V buck (U7 AP64501) provides system 3.3V; Pi 3V3 pins isolated 3. 1-Wire Bus Notes: Board has a 2.2K pull-up on the data line. Put a 220R resistor on the data pin of each temp sensor but ensure it's not

in series with the bus. Put a 100nF ceramic cap across VCC and GND at each temp sensor. 4. WS281X RPI Notes: Put a 220uF electrolytic cap between 12V and GND at the start of each LED strip 5. UARTS: UART1 / GPIO14/15 / Reserved for Bluetooth UART2 / GPIO00/01 / GPS UART3 / GPIO04/05 / ESP32 No. 1 UART4 / GPIO08/09 / ESP32 No. 2

Capacitors need to be positioned
directly at the Vin pin

Scale: NTS
Drawn By: Joel Goudswaard
Singularity Automation Pty Ltd
Sheet: /
File: SCCS-RPI.kicad_sch
Title: Singularity Camper Control System (SCCS)

6. 12V LED Strip Notes (not required but good practice): Put a 220uF 25V electrolytic cap across 12V and GND at each LED strip. Put a 100nF 25V ceramic cap across 12V and GND at each LED strip.

Size: A2 | Rev: 1.1
KiCad E.D.A. 10.0.4 | Id: 1/43

Sheet: /Ambient Air Temp/
File: 1_wire_bus.kicad_sch
Title:

Size: A5 | Rev: | C Date:
KiCad E.D.A. 10.0.4 | Id: 2/43

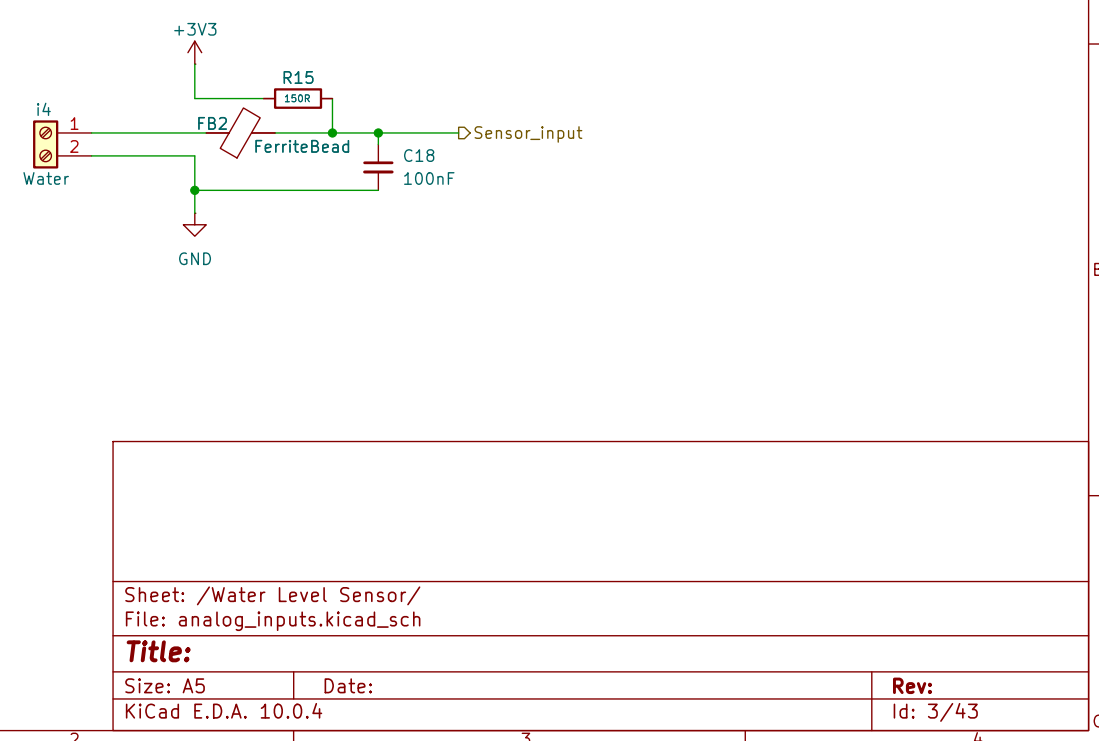
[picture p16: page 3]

Sheet: /Water Level Sensor/
File: analog_inputs.kicad_sch
Title:

Size: A5 | Rev: | C Date:
KiCad E.D.A. 10.0.4 | Id: 3/43

Size: A5 | Rev: | C Date:
KiCad E.D.A. 10.0.4 | Id: 4/43

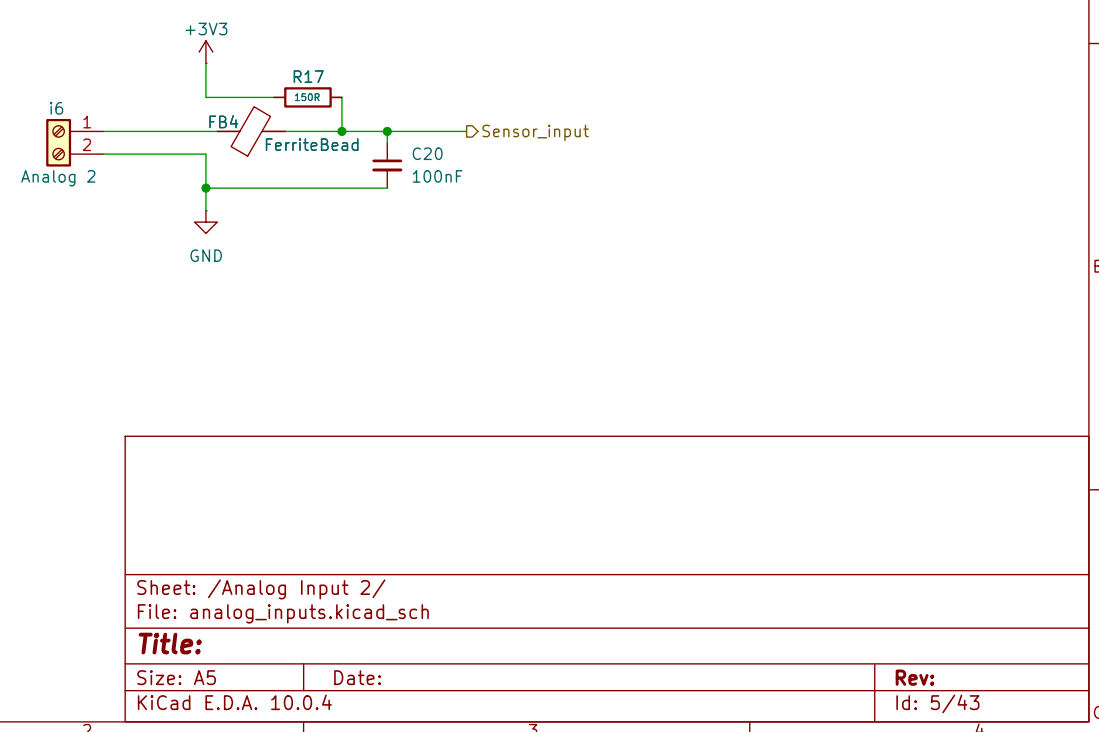
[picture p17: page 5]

Size: A5 | Rev: | C Date:
KiCad E.D.A. 10.0.4 | Id: 5/43

Size: A5 | Rev: | C Date:
KiCad E.D.A. 10.0.4 | Id: 6/43

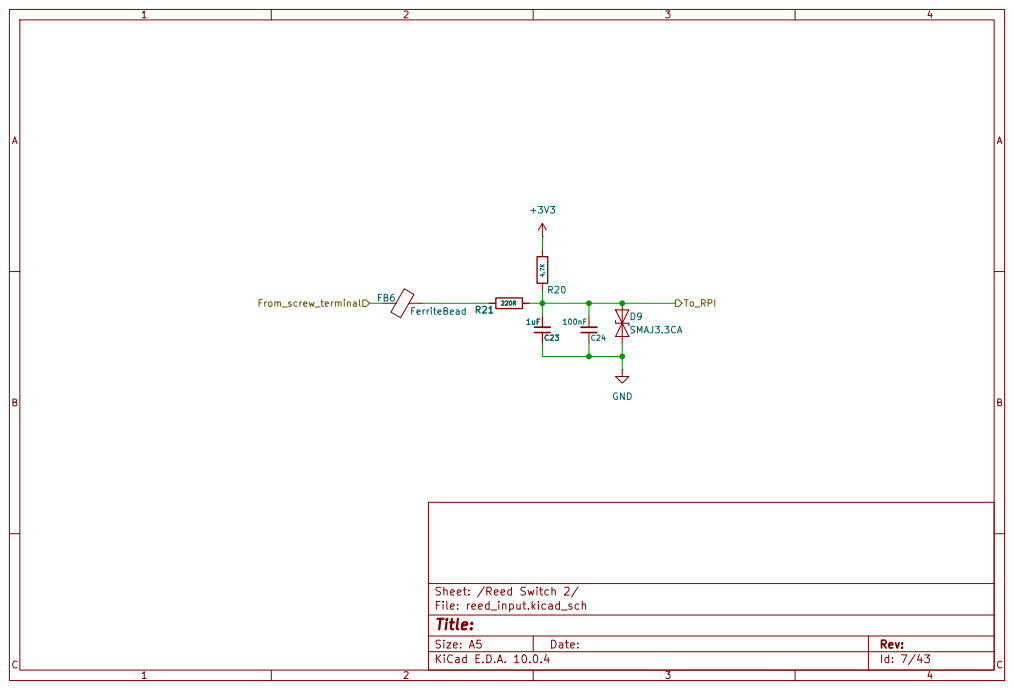
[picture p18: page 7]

Size: A5 | Rev: | C Date:
KiCad E.D.A. 10.0.4 | Id: 7/43

Size: A5 | Rev: | C Date:
KiCad E.D.A. 10.0.4 | Id: 8/43

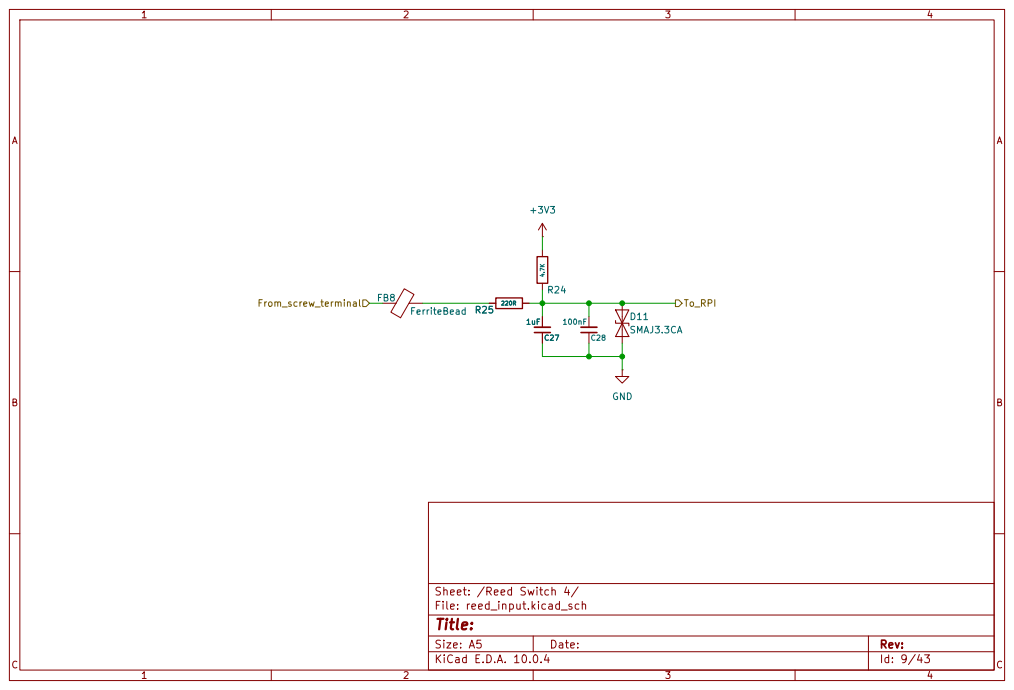
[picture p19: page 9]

Size: A5 | Rev: | C Date:
KiCad E.D.A. 10.0.4 | Id: 9/43

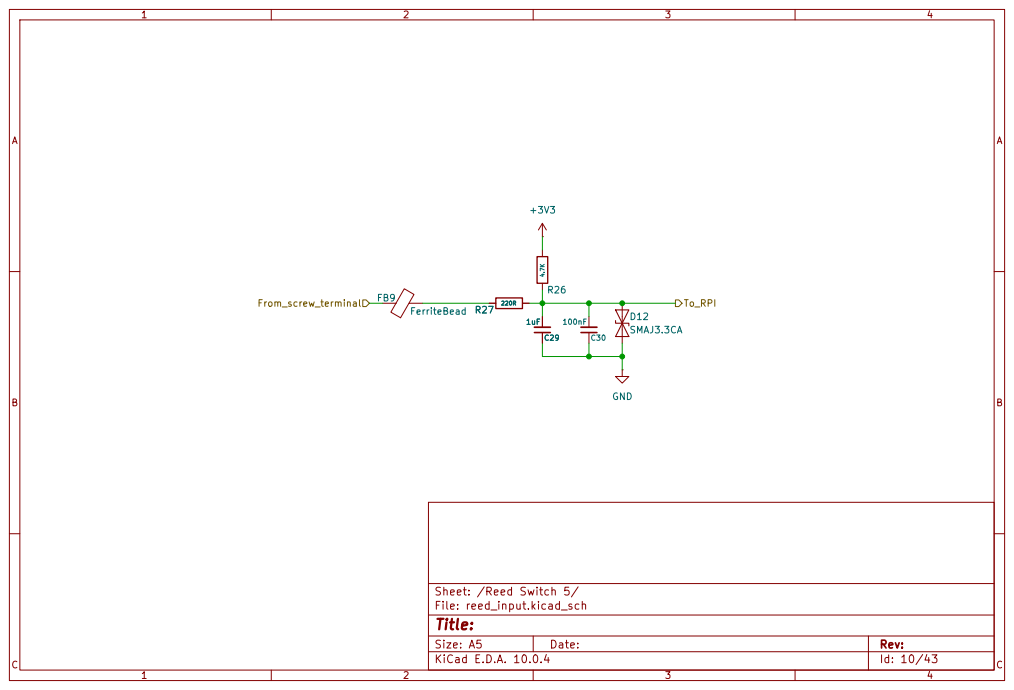
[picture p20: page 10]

Size: A5 | Rev: | C Date:
KiCad E.D.A. 10.0.4 | Id: 10/43

Size: A5 | Rev: | C Date:
KiCad E.D.A. 10.0.4 | Id: 11/43

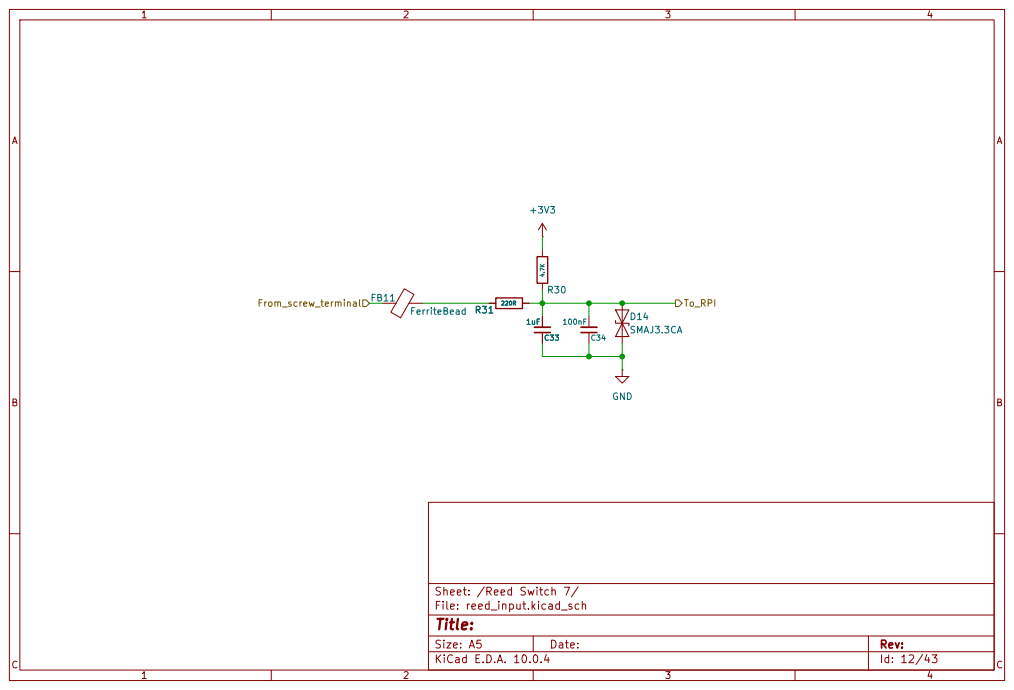
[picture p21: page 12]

Size: A5 | Rev: | C Date:
KiCad E.D.A. 10.0.4 | Id: 12/43

Size: A5 | Rev: | C Date:
KiCad E.D.A. 10.0.4 | Id: 13/43

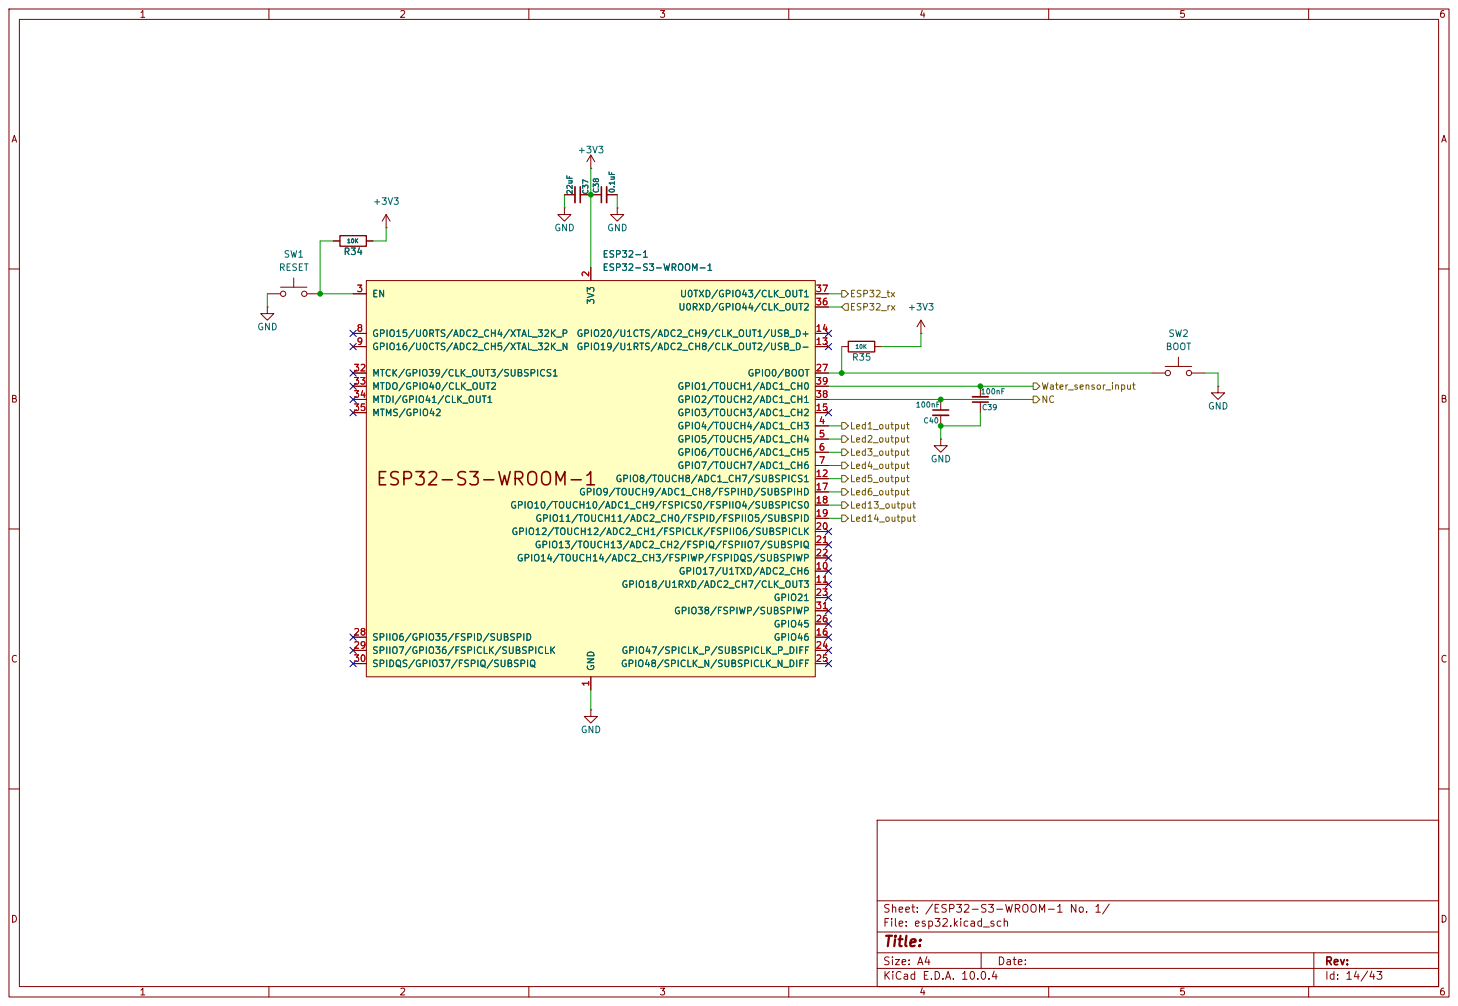
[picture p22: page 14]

Size: A4 | Rev:
KiCad E.D.A. 10.0.4 | Id: 14/43

Size: A4 | Rev:
KiCad E.D.A. 10.0.4 | Id: 15/43

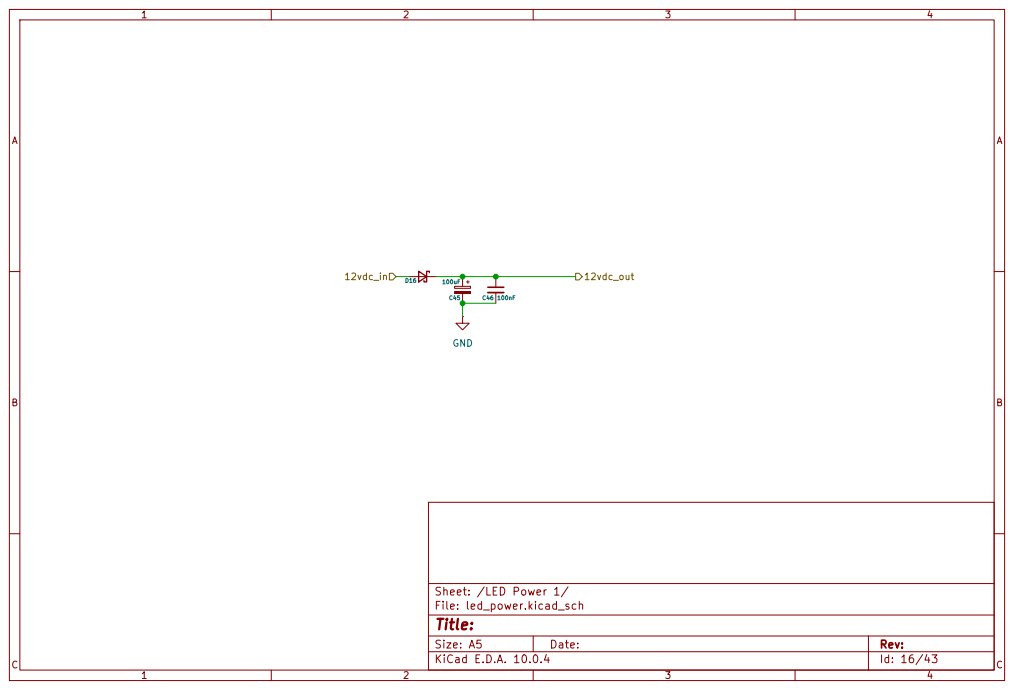
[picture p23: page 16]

Size: A5 | Rev: | C Date:
KiCad E.D.A. 10.0.4 | Id: 16/43

Size: A5 | Rev: | C Date:
KiCad E.D.A. 10.0.4 | Id: 17/43

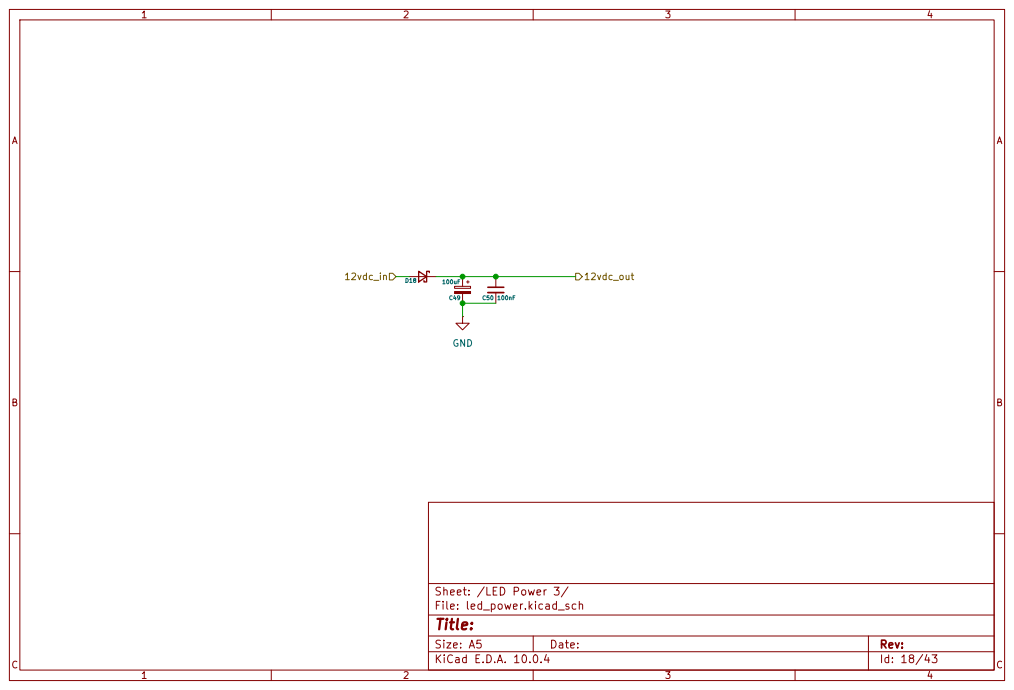
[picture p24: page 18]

Size: A5 | Rev: | C Date:
KiCad E.D.A. 10.0.4 | Id: 18/43

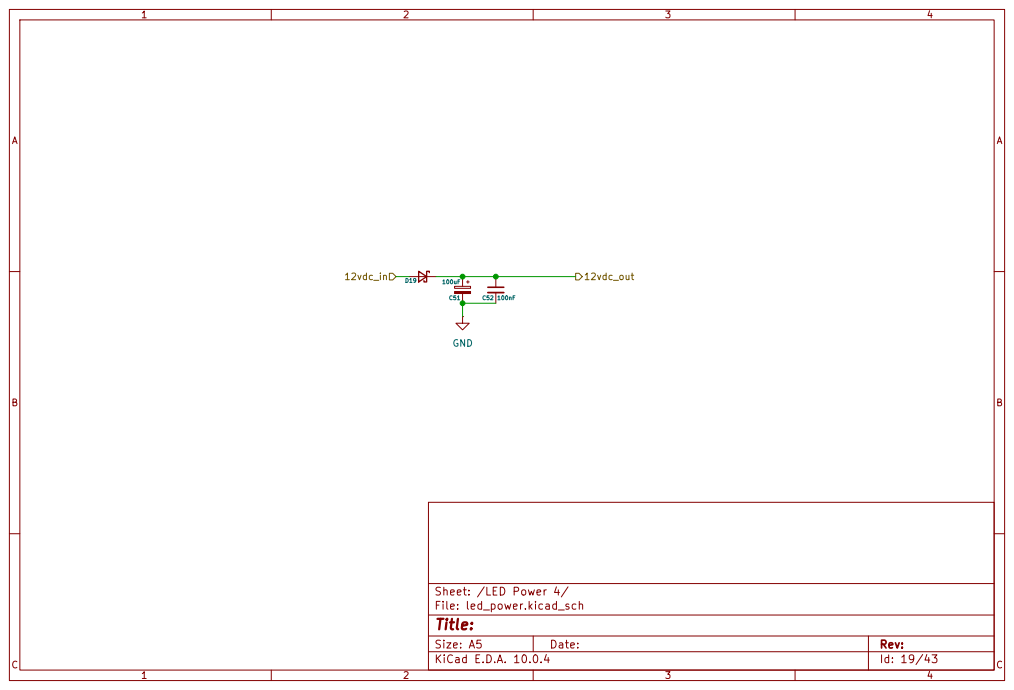
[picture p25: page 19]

Size: A5 | Rev: | C Date:
KiCad E.D.A. 10.0.4 | Id: 19/43

Size: A5 | Rev: | C Date:
KiCad E.D.A. 10.0.4 | Id: 20/43

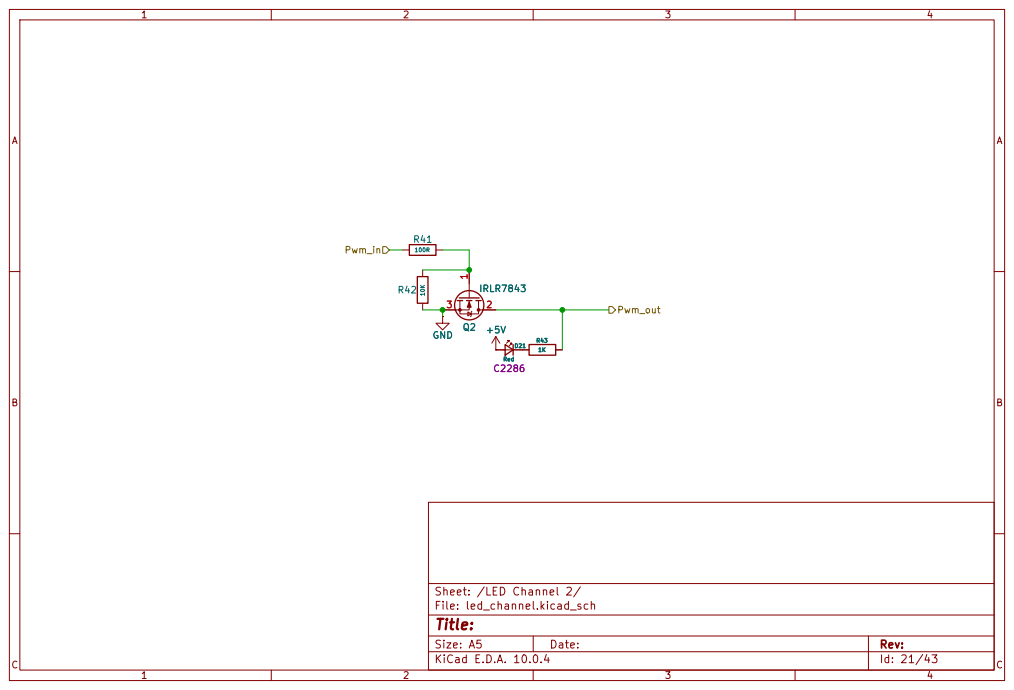
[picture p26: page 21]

Size: A5 | Rev: | C Date:
KiCad E.D.A. 10.0.4 | Id: 21/43

Size: A5 | Rev: | C Date:
KiCad E.D.A. 10.0.4 | Id: 23/43


Size: A5 | Rev: | C Date:
KiCad E.D.A. 10.0.4 | Id: 24/43

Size: A5 | Rev: | C Date:
KiCad E.D.A. 10.0.4 | Id: 25/43


Size: A5 | Rev: | C Date:
KiCad E.D.A. 10.0.4 | Id: 26/43


Size: A5 | Rev: | C Date:
KiCad E.D.A. 10.0.4 | Id: 27/43

Size: A5 | Rev: | C Date:
KiCad E.D.A. 10.0.4 | Id: 28/43


Size: A5 | Rev: | C Date:
KiCad E.D.A. 10.0.4 | Id: 29/43

Size: A5 | Rev: | C Date:
KiCad E.D.A. 10.0.4 | Id: 30/43


Size: A5 | Rev: | C Date:
KiCad E.D.A. 10.0.4 | Id: 31/43

Size: A5 | Rev: | C Date:
KiCad E.D.A. 10.0.4 | Id: 32/43


Size: A5 | Rev: | C Date:
KiCad E.D.A. 10.0.4 | Id: 33/43

Size: A5 | Rev: | C Date:
KiCad E.D.A. 10.0.4 | Id: 34/43


Size: A5 | Rev: | C Date:
KiCad E.D.A. 10.0.4 | Id: 35/43


Size: A5 | Rev: | C Date:
KiCad E.D.A. 10.0.4 | Id: 36/43

Size: A4 | Rev:
KiCad E.D.A. 10.0.4 | Id: 37/43


Size: A4 | Rev:
KiCad E.D.A. 10.0.4 | Id: 38/43

Capacitor needs to be positioned

Size: A5 | Rev: | C Date:
KiCad E.D.A. 10.0.4 | Id: 39/43


Capacitor needs to be positioned

Size: A5 | Rev: | C Date:
KiCad E.D.A. 10.0.4 | Id: 40/43

Capacitor needs to be positioned

Size: A5 | Rev: | C Date:
KiCad E.D.A. 10.0.4 | Id: 41/43


Capacitor needs to be positioned
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

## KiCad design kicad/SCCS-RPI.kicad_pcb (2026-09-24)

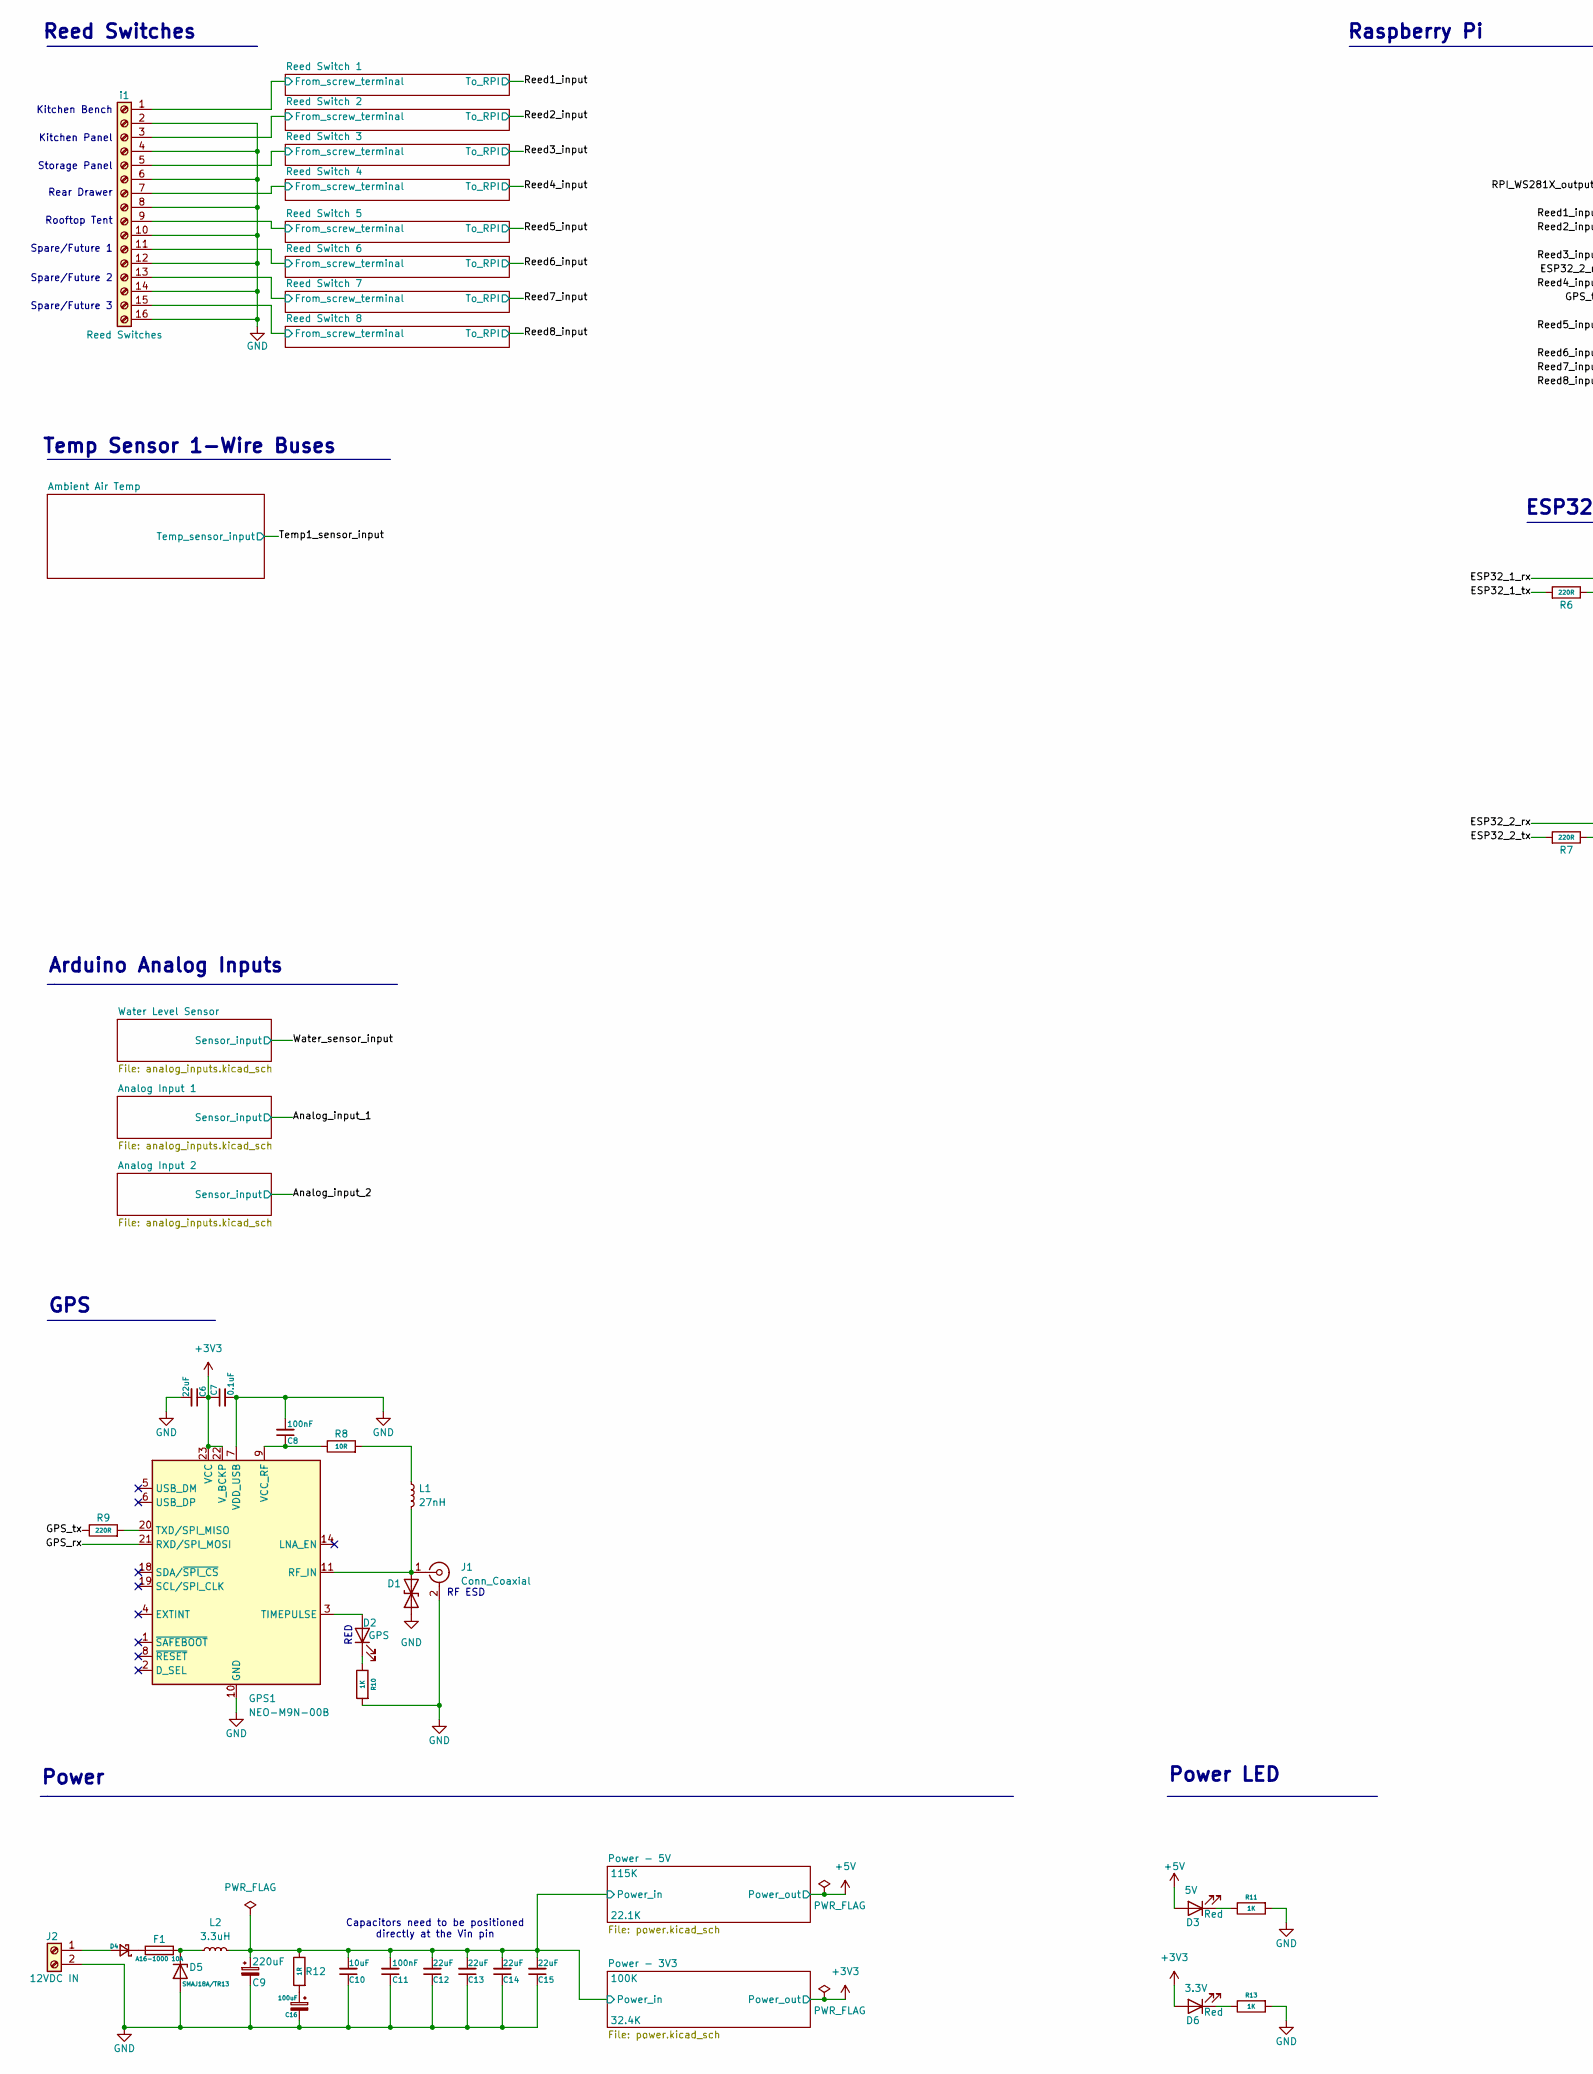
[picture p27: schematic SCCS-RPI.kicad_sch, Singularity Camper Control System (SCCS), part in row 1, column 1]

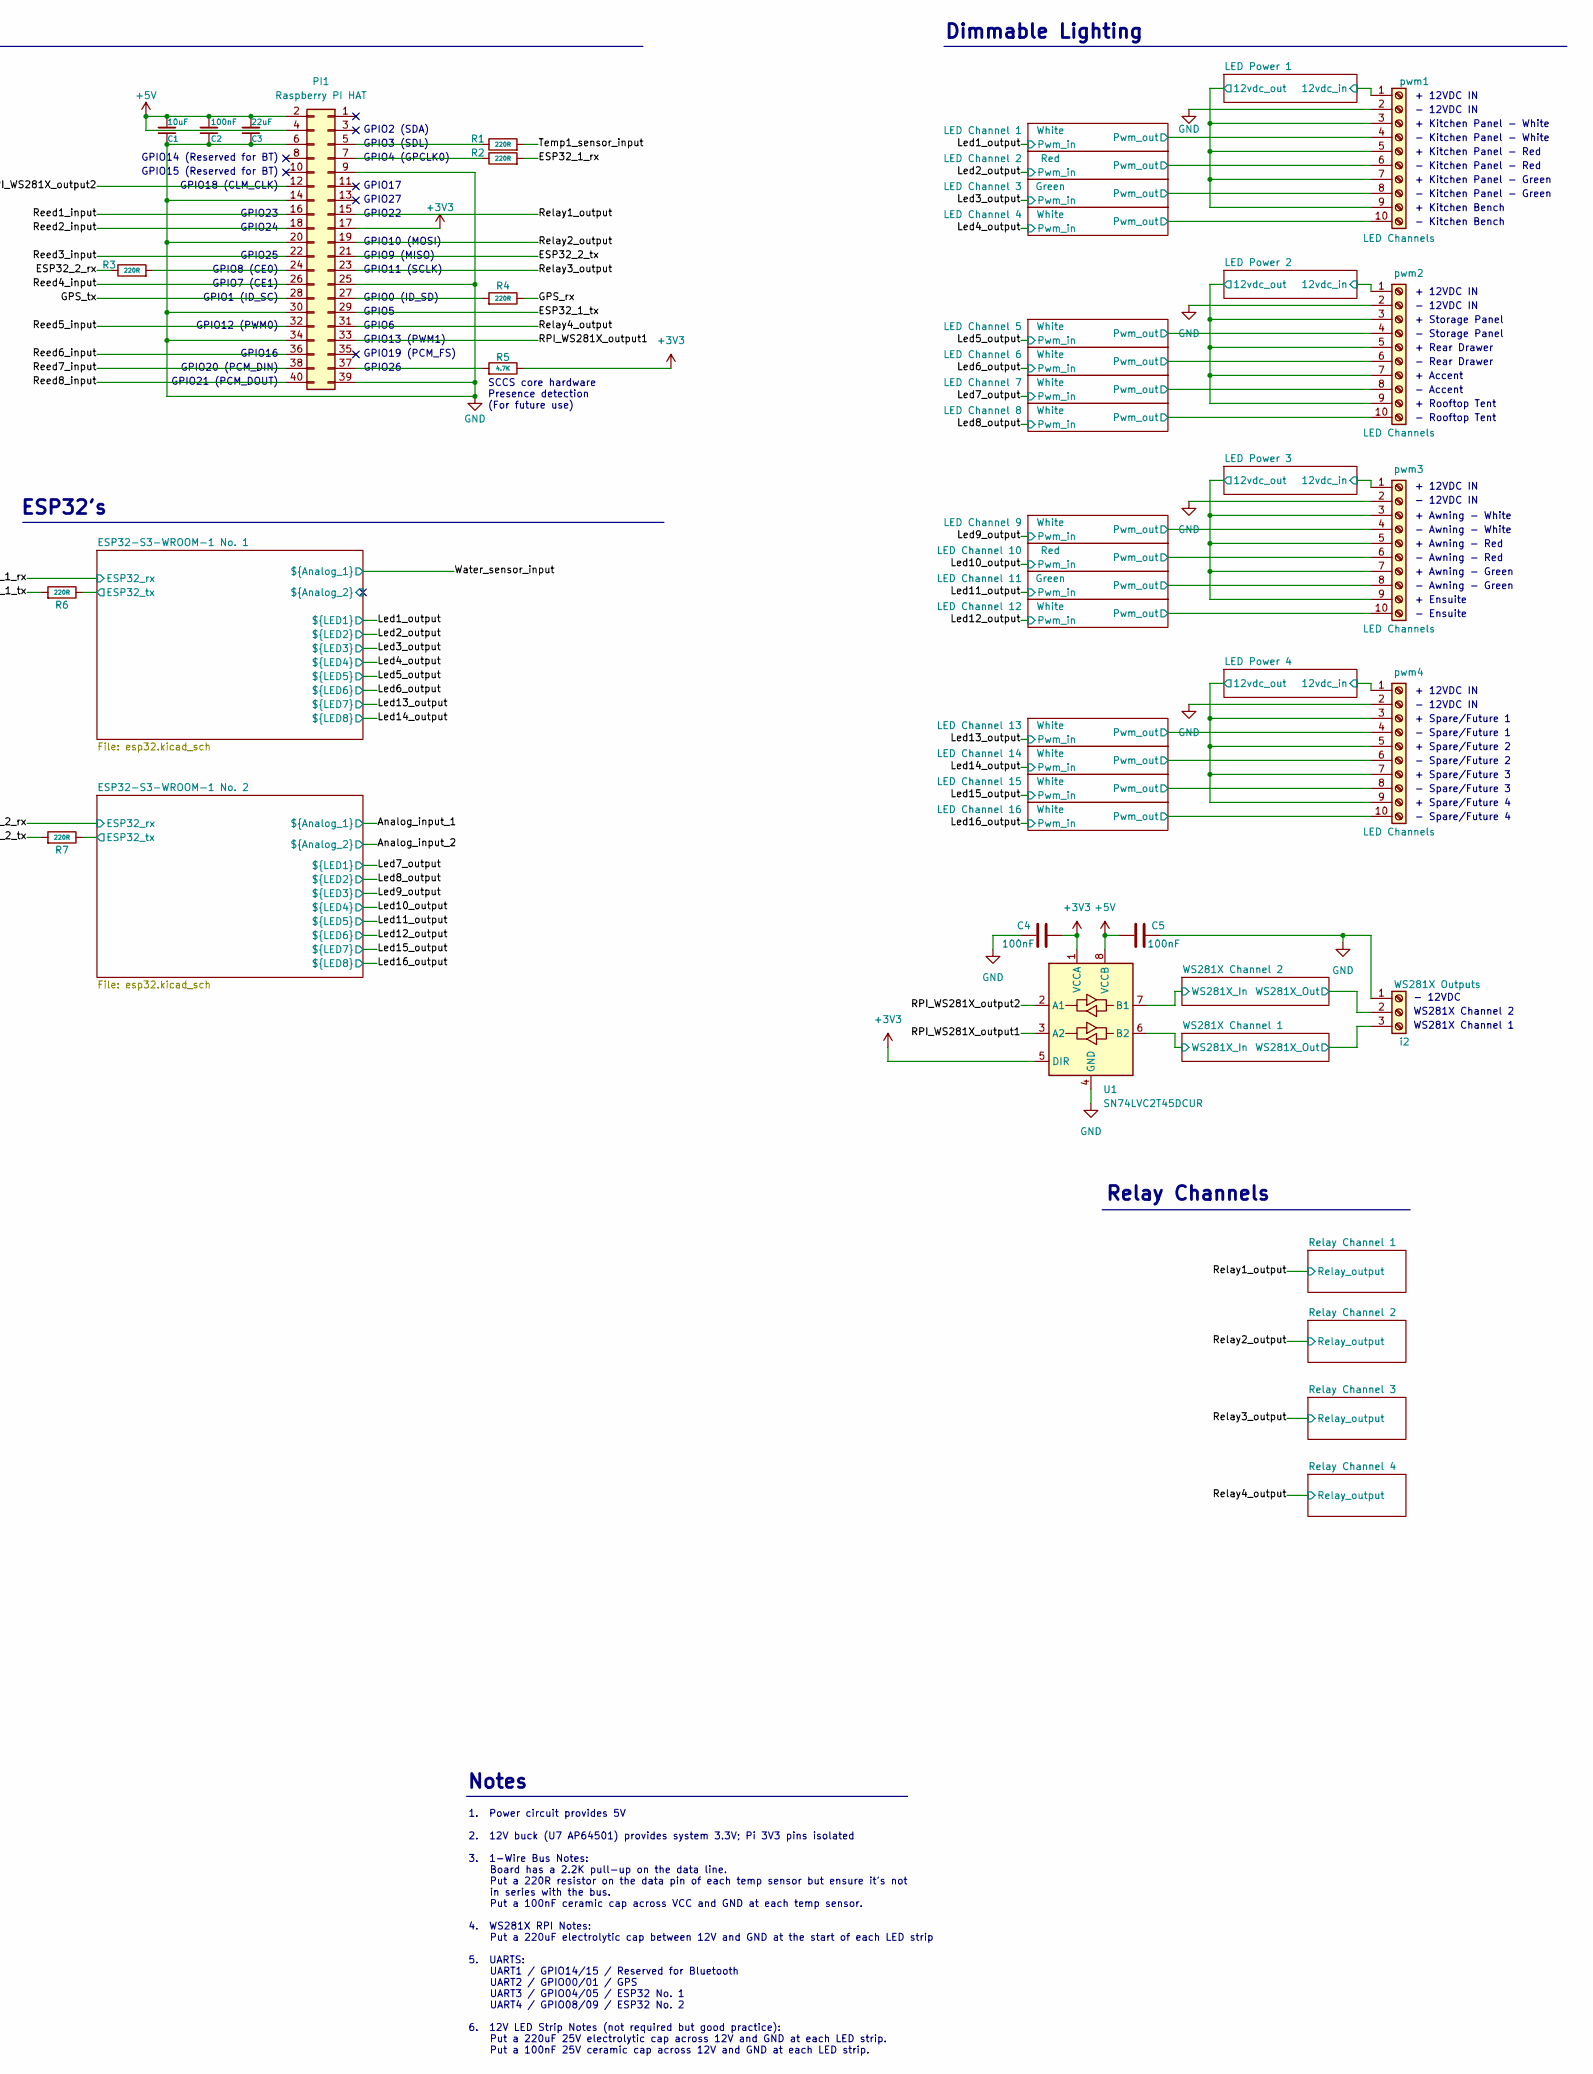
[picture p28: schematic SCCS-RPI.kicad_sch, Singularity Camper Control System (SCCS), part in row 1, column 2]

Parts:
C1, C10: 10uF; C_0805_2012Metric; LCSC Part # C15850
C2, C8, C11: 100nF; C_0805_2012Metric; LCSC Part # C49678
C3, C6, C12, C13, C14, C15: 22uF; C_0805_2012Metric; LCSC Part # C86816
C4, C5: 100nF; C_0603_1608Metric; LCSC Part # C1590
C7: 0.1uF; C_0805_2012Metric; LCSC Part # C86041
C9: 220uF; CP_Elec_8x10; LCSC Part # C165536
C16: 100uF; CP_Radial_D6.3mm_P2.50mm; LCSC Part # C44587
D1: ESD103-B1-02EL; D_0402_1005Metric; LCSC Part # C535146
D2: GPS; LED_0603_1608Metric; LCSC Part # C2286
D3: 5V; LED_0603_1608Metric; LCSC Part # C2286
D4: D_PowerDI-5; LCSC Part # C2759901
D5: SMAJ18A/TR13; D_SMB; LCSC Part # C571369
D6: 3.3V; LED_0603_1608Metric; LCSC Part # C2286
F1: A16-1000 10A; Fuse_Bourns_MF-RG1000; LCSC Part # C135398
GPS1: NEO-M9N-00B; ublox_NEO; LCSC Part # C5119087
J1: Conn_Coaxial; SMA_Amphenol_132134-11_Vertical; LCSC Part # C20415804
J2: 12VDC IN; TerminalBlock_Phoenix_MKDS-1,5-2-5.08_1x02_P5.08mm_Horizont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; LCSC Part # C8445
L1: 27nH; L_0603_1608Metric; LCSC Part # C162550
L2: 3.3uH; L_SXN_SMDRI127; LCSC Part # C24550
PI1: Raspberry PI HAT; PinSocket_2x20_P2.54mm_Vertical; LCSC Part # C132132
R1, R2, R3, R4, R6, R7, R9: 220R; R_0805_2012Metric; LCSC Part # C17557
R5: 4.7K; R_0805_2012Metric; LCSC Part # C17673
R8: 10R; R_0805_2012Metric; LCSC Part # C17415
R10, R11, R13: 1K; R_0402_1005Metric; LCSC Part # C11702
R12: 1R; R_0805_2012Metric; LCSC Part # C25271
U1: SN74LVC2T45DCUR; VSSOP-8_2.3x2mm_P0.5mm; LCSC Part # C15741
i1: Reed Switches; TerminalBlock_Phoenix_MKDS-1,5-16-5.08_1x16_P5.08mm_Horizon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; LCSC Part # C508906
i2: WS281X Outputs; TerminalBlock_Phoenix_MKDS-1,5-3-5.08_1x03_P5.08mm_Horizont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; LCSC Part # C8412
pwm1, pwm2, pwm3, pwm4: LED Channels; TerminalBlock_Phoenix_MKDS-1,5-10-5.08_1x10_P5.08mm_Horizon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; LCSC Part # C29173

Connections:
+3V3: C4.2, C6.1, C7.1, D6.2 (A), GPS1.22 (V_BCKP), GPS1.23 (VCC), PI1.17, R5.1, U1.1 (VCCA), U1.5 (DIR); also elsewhere on the board
+5V: C1.2, C2.2, C3.2, C5.2, D3.2 (A), PI1.2, PI1.4, U1.8 (VCCB); also elsewhere on the board
/ESP32-S3-WROOM-1 No. 1/ESP32_tx: R6.1; also elsewhere on the board
/ESP32-S3-WROOM-1 No. 2/ESP32_tx: R7.1; also elsewhere on the board
/ESP32_1_rx: R2.2; also elsewhere on the board
/ESP32_1_tx: PI1.29, R6.2
/ESP32_2_rx: R3.1; also elsewhere on the board
/ESP32_2_tx: PI1.21, R7.2
/GPS_rx: GPS1.21 (RXD/SPI_MOSI), R4.1
/GPS_tx: PI1.28, R9.1
/LED Channel 1/Pwm_out: pwm1.4; also elsewhere on the board
/LED Channel 2/Pwm_out: pwm1.6; also elsewhere on the board
/LED Channel 3/Pwm_out: pwm1.8; also elsewhere on the board
/LED Channel 4/Pwm_out: pwm1.10; also elsewhere on the board
/LED Channel 5/Pwm_out: pwm2.4; also elsewhere on the board
/LED Channel 6/Pwm_out: pwm2.6; also elsewhere on the board
/LED Channel 7/Pwm_out: pwm2.8; also elsewhere on the board
/LED Channel 8/Pwm_out: pwm2.10; also elsewhere on the board
/LED Channel 9/Pwm_out: pwm3.4; also elsewhere on the board
/LED Channel 10/Pwm_out: pwm3.6; also elsewhere on the board
/LED Channel 11/Pwm_out: pwm3.8; also elsewhere on the board
/LED Channel 12/Pwm_out: pwm3.10; also elsewhere on the board
/LED Channel 13/Pwm_out: pwm4.4; also elsewhere on the board
/LED Channel 14/Pwm_out: pwm4.6; also elsewhere on the board
/LED Channel 15/Pwm_out: pwm4.8; also elsewhere on the board
/LED Channel 16/Pwm_out: pwm4.10; also elsewhere on the board
/LED Power 1/12vdc_in: pwm1.1; also elsewhere on the board
/LED Power 1/12vdc_out: pwm1.3, pwm1.5, pwm1.7, pwm1.9; also elsewhere on the board
/LED Power 2/12vdc_in: pwm2.1; also elsewhere on the board
/LED Power 2/12vdc_out: pwm2.3, pwm2.5, pwm2.7, pwm2.9; also elsewhere on the board
/LED Power 3/12vdc_in: pwm3.1; also elsewhere on the board
/LED Power 3/12vdc_out: pwm3.3, pwm3.5, pwm3.7, pwm3.9; also elsewhere on the board
/LED Power 4/12vdc_in: pwm4.1; also elsewhere on the board
/LED Power 4/12vdc_out: pwm4.3, pwm4.5, pwm4.7, pwm4.9; also elsewhere on the board
/Power - 3V3/Power_in: C9.1, C10.2, C11.2, C12.2, C13.2, C14.2, C15.2, L2.2, R12.1; also elsewhere on the board
/RPI_WS281X_output1: PI1.33, U1.3 (A2)
/RPI_WS281X_output2: PI1.12, U1.2 (A1)
/Reed1_input: PI1.16; also elsewhere on the board
/Reed2_input: PI1.18; also elsewhere on the board
/Reed3_input: PI1.22; also elsewhere on the board
/Reed4_input: PI1.26; also elsewhere on the board
/Reed5_input: PI1.32; also elsewhere on the board
/Reed6_input: PI1.36; also elsewhere on the board
/Reed7_input: PI1.38; also elsewhere on the board
/Reed8_input: PI1.40; also elsewhere on the board
/Reed Switch 1/From_screw_terminal: i1.1; also elsewhere on the board
/Reed Switch 2/From_screw_terminal: i1.3; also elsewhere on the board
/Reed Switch 3/From_screw_terminal: i1.5; also elsewhere on the board
/Reed Switch 4/From_screw_terminal: i1.7; also elsewhere on the board
/Reed Switch 5/From_screw_terminal: i1.9; also elsewhere on the board
/Reed Switch 6/From_screw_terminal: i1.11; also elsewhere on the board
/Reed Switch 7/From_screw_terminal: i1.13; also elsewhere on the board
/Reed Switch 8/From_screw_terminal: i1.15; also elsewhere on the board
/Relay1_output: PI1.15; also elsewhere on the board
/Relay2_output: PI1.19; also elsewhere on the board
/Relay3_output: PI1.23; also elsewhere on the board
/Relay4_output: PI1.31; also elsewhere on the board
/Temp1_sensor_input: R1.2; also elsewhere on the board
/WS281X Channel 1/WS281X_In: U1.6 (B2); also elsewhere on the board
/WS281X Channel 1/WS281X_Out: i2.3; also elsewhere on the board
/WS281X Channel 2/WS281X_In: U1.7 (B1); also elsewhere on the board
/WS281X Channel 2/WS281X_Out: i2.2; also elsewhere on the board
GND: C1.1, C2.1, C3.1, C4.1, C5.1, C6.2, C7.2, C8.2, C9.2, C10.1, C11.1, C12.1, C13.1, C14.1, C15.1, C16.2, D1.1 (A1), D5.2 (A), GPS1.7 (VDD_USB), GPS1.10 (GND), GPS1.12 (GND), GPS1.13 (GND), GPS1.24 (GND), J1.2 (Ext), J2.2, PI1.6, PI1.9, PI1.14, PI1.20, PI1.25, PI1.30, PI1.34, PI1.39, R10.2, R11.2, R13.2, U1.4 (GND), i1.2, i1.4, i1.6, i1.8, i1.10, i1.12, i1.14, i1.16, i2.1, pwm1.2, pwm2.2, pwm3.2, pwm4.2; also elsewhere on the board
unnamed: C16.1, R12.2
unnamed: D1.2 (A2), GPS1.11 (RF_IN), J1.1 (In), L1.2
unnamed: D2.2 (A), GPS1.3 (TIMEPULSE)
unnamed: D2.1 (K), R10.1
unnamed: D3.1 (K), R11.1
unnamed: D4.2 (A), J2.1
unnamed: D4.1 (K), F1.1
unnamed: D5.1 (K), F1.2, L2.1
unnamed: D6.1 (K), R13.1
unnamed: GPS1.20 (TXD/SPI_MISO), R9.2
unnamed: C8.1, GPS1.9 (VCC_RF), R8.1
unnamed: L1.1, R8.2
unnamed: PI1.5, R1.1
unnamed: PI1.7, R2.1
unnamed: PI1.24, R3.2
unnamed: PI1.27, R4.2
unnamed: PI1.37, R5.2

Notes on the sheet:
+ Awning - White
- Spare/Future 3
GPIO1 (ID_SC)
Capacitors need to be positioned directly at the Vin pin
+ Spare/Future 1
WS281X Channel 1
GPIO12 (PWM0)
Rooftop Tent
Temp Sensor 1-Wire Buses
GPIO15 (Reserved for BT)
- 12VDC IN
SCCS core hardware Presence detection (For future use)
GPIO22
GPIO23
- Kitchen Panel - Red
Spare/Future 3
GPIO20 (PCM_DIN)
1. Power circuit provides 5V 2. 12V buck (U7 AP64501) provides system 3.3V; Pi 3V3 pins isolated 3. 1-Wire Bus Notes: Board has a 2.2K pull-up on the data line. Put a 220R resistor on the data pin of each temp sensor but ensure it's not in series with the bus. Put a 100nF ceramic cap across VCC and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
- Rear Drawer
ESP32's
+ Kitchen Bench
- Accent
RF ESD
GPIO25
GPIO27
+ 12VDC IN
GPIO11 (SCLK)
+ Storage Panel
+ Ensuite
- Kitchen Bench
GPIO7 (CE1)
Kitchen Bench
Notes
- Spare/Future 1
GPS
GPIO4 (GPCLK0)
- Rooftop Tent
Spare/Future 2
GPIO3 (SDL)
+ Awning - Green

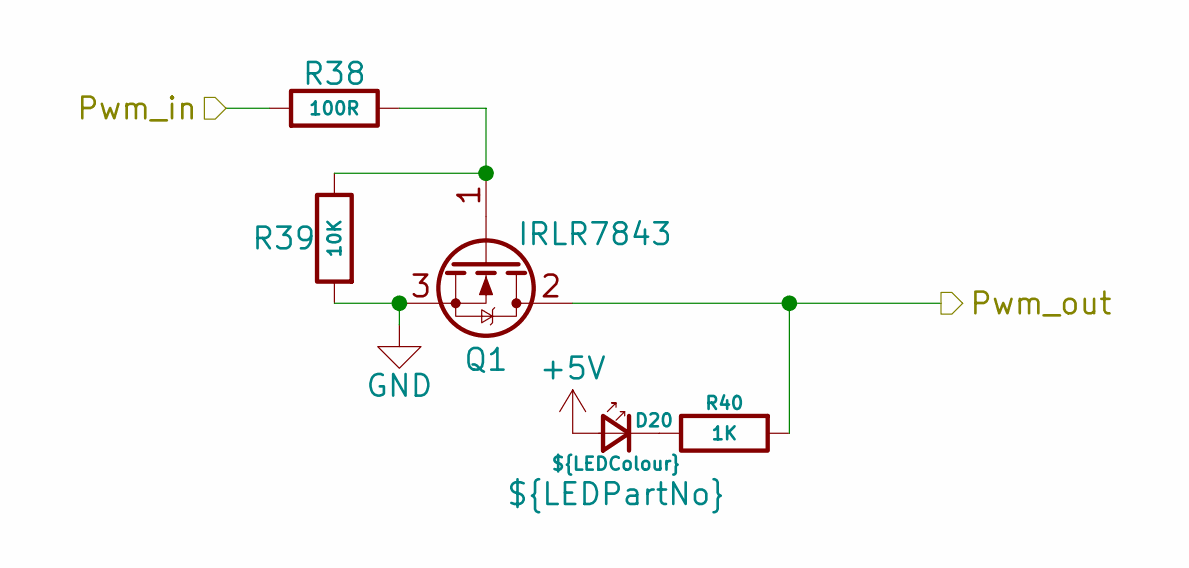
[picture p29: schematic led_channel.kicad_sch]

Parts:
D20: ${LEDColour}; LED_0603_1608Metric; LCSC Part # ${LEDPartNo}
Q1: IRLR7843; TO-252-2; LCSC Part # C21988
R38: 100R; R_0805_2012Metric; LCSC Part # C17408
R39: 10K; R_0805_2012Metric; LCSC Part # C17414
R40: 1K; R_0805_2012Metric; LCSC Part # C17513

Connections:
+5V: D20.2 (A); also elsewhere on the board
/LED Channel 1/Pwm_out: Q1.2 (D), R40.2; also elsewhere on the board
/Led1_output: R38.2; also elsewhere on the board
GND: Q1.3 (S), R39.2; also elsewhere on the board
unnamed: D20.1 (K), R40.1
unnamed: Q1.1 (G), R38.1, R39.1

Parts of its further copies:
Q2, Q3, Q4, Q5, Q6, Q7, Q8, Q9, Q10, Q11, Q12, Q13, Q14, Q15, Q16: IRLR7843; TO-252-2; LCSC Part # C21988
R41, R44, R47, R50, R53, R56, R59, R62, R65, R68, R71, R74, R77, R80, R83: 100R; R_0805_2012Metric; LCSC Part # C17408
R42, R45, R48, R51, R54, R57, R60, R63, R66, R69, R72, R75, R78, R81, R84: 10K; R_0805_2012Metric; LCSC Part # C17414
R43, R46, R49, R52, R55, R58, R61, R64, R67, R70, R73, R76, R79, R82, R85: 1K; R_0805_2012Metric; LCSC Part # C17513

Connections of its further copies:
/LED Channel 2/Pwm_out: Q2.2 (D), R43.2; also elsewhere on the board
/LED Channel 3/Pwm_out: Q3.2 (D), R46.2; also elsewhere on the board
/LED Channel 4/Pwm_out: Q4.2 (D), R49.2; also elsewhere on the board
/LED Channel 5/Pwm_out: Q5.2 (D), R52.2; also elsewhere on the board
/LED Channel 6/Pwm_out: Q6.2 (D), R55.2; also elsewhere on the board
/LED Channel 7/Pwm_out: Q7.2 (D), R58.2; also elsewhere on the board
/LED Channel 8/Pwm_out: Q8.2 (D), R61.2; also elsewhere on the board
/LED Channel 9/Pwm_out: Q9.2 (D), R64.2; also elsewhere on the board
/LED Channel 10/Pwm_out: Q10.2 (D), R67.2; also elsewhere on the board
/LED Channel 11/Pwm_out: Q11.2 (D), R70.2; also elsewhere on the board
/LED Channel 12/Pwm_out: Q12.2 (D), R73.2; also elsewhere on the board
/LED Channel 13/Pwm_out: Q13.2 (D), R76.2; also elsewhere on the board
/LED Channel 14/Pwm_out: Q14.2 (D), R79.2; also elsewhere on the board
/LED Channel 15/Pwm_out: Q15.2 (D), R82.2; also elsewhere on the board
/LED Channel 16/Pwm_out: Q16.2 (D), R85.2; also elsewhere on the board
/Led2_output: R41.2; also elsewhere on the board
/Led3_output: R44.2; also elsewhere on the board
/Led4_output: R47.2; also elsewhere on the board
/Led5_output: R50.2; also elsewhere on the board
/Led6_output: R53.2; also elsewhere on the board
/Led7_output: R56.2; also elsewhere on the board
/Led8_output: R59.2; also elsewhere on the board
/Led9_output: R62.2; also elsewhere on the board
/Led10_output: R65.2; also elsewhere on the board
/Led11_output: R68.2; also elsewhere on the board
/Led12_output: R71.2; also elsewhere on the board
/Led13_output: R74.2; also elsewhere on the board
/Led14_output: R77.2; also elsewhere on the board
/Led15_output: R80.2; also elsewhere on the board
/Led16_output: R83.2; also elsewhere on the board
GND: Q2.3 (S), Q3.3 (S), Q4.3 (S), Q5.3 (S), Q6.3 (S), Q7.3 (S), Q8.3 (S), Q9.3 (S), Q10.3 (S), Q11.3 (S), Q12.3 (S), Q13.3 (S), Q14.3 (S), Q15.3 (S), Q16.3 (S), R42.2, R45.2, R48.2, R51.2, R54.2, R57.2, R60.2, R63.2, R66.2, R69.2, R72.2, R75.2, R78.2, R81.2, R84.2; also elsewhere on the board
unnamed 95: R43.1; also elsewhere on the board
unnamed 96: R46.1; also elsewhere on the board
unnamed 97: R49.1; also elsewhere on the board
unnamed 98: R52.1; also elsewhere on the board
unnamed 99: R55.1; also elsewhere on the board
unnamed 100: R58.1; also elsewhere on the board
unnamed 101: R61.1; also elsewhere on the board
unnamed 102: R64.1; also elsewhere on the board
unnamed 103: R67.1; also elsewhere on the board
unnamed 104: R70.1; also elsewhere on the board
unnamed 105: R73.1; also elsewhere on the board
unnamed 106: R76.1; also elsewhere on the board
unnamed 107: R79.1; also elsewhere on the board
unnamed 108: R82.1; also elsewhere on the board
unnamed 109: R85.1; also elsewhere on the board
unnamed: Q2.1 (G), R41.1, R42.1
unnamed: Q3.1 (G), R44.1, R45.1
unnamed: Q4.1 (G), R47.1, R48.1
unnamed: Q5.1 (G), R50.1, R51.1
unnamed: Q6.1 (G), R53.1, R54.1
unnamed: Q7.1 (G), R56.1, R57.1
unnamed: Q8.1 (G), R59.1, R60.1
unnamed: Q9.1 (G), R62.1, R63.1
unnamed: Q10.1 (G), R65.1, R66.1
unnamed: Q11.1 (G), R68.1, R69.1
unnamed: Q12.1 (G), R71.1, R72.1
unnamed: Q13.1 (G), R74.1, R75.1
unnamed: Q14.1 (G), R77.1, R78.1
unnamed: Q15.1 (G), R80.1, R81.1
unnamed: Q16.1 (G), R83.1, R84.1

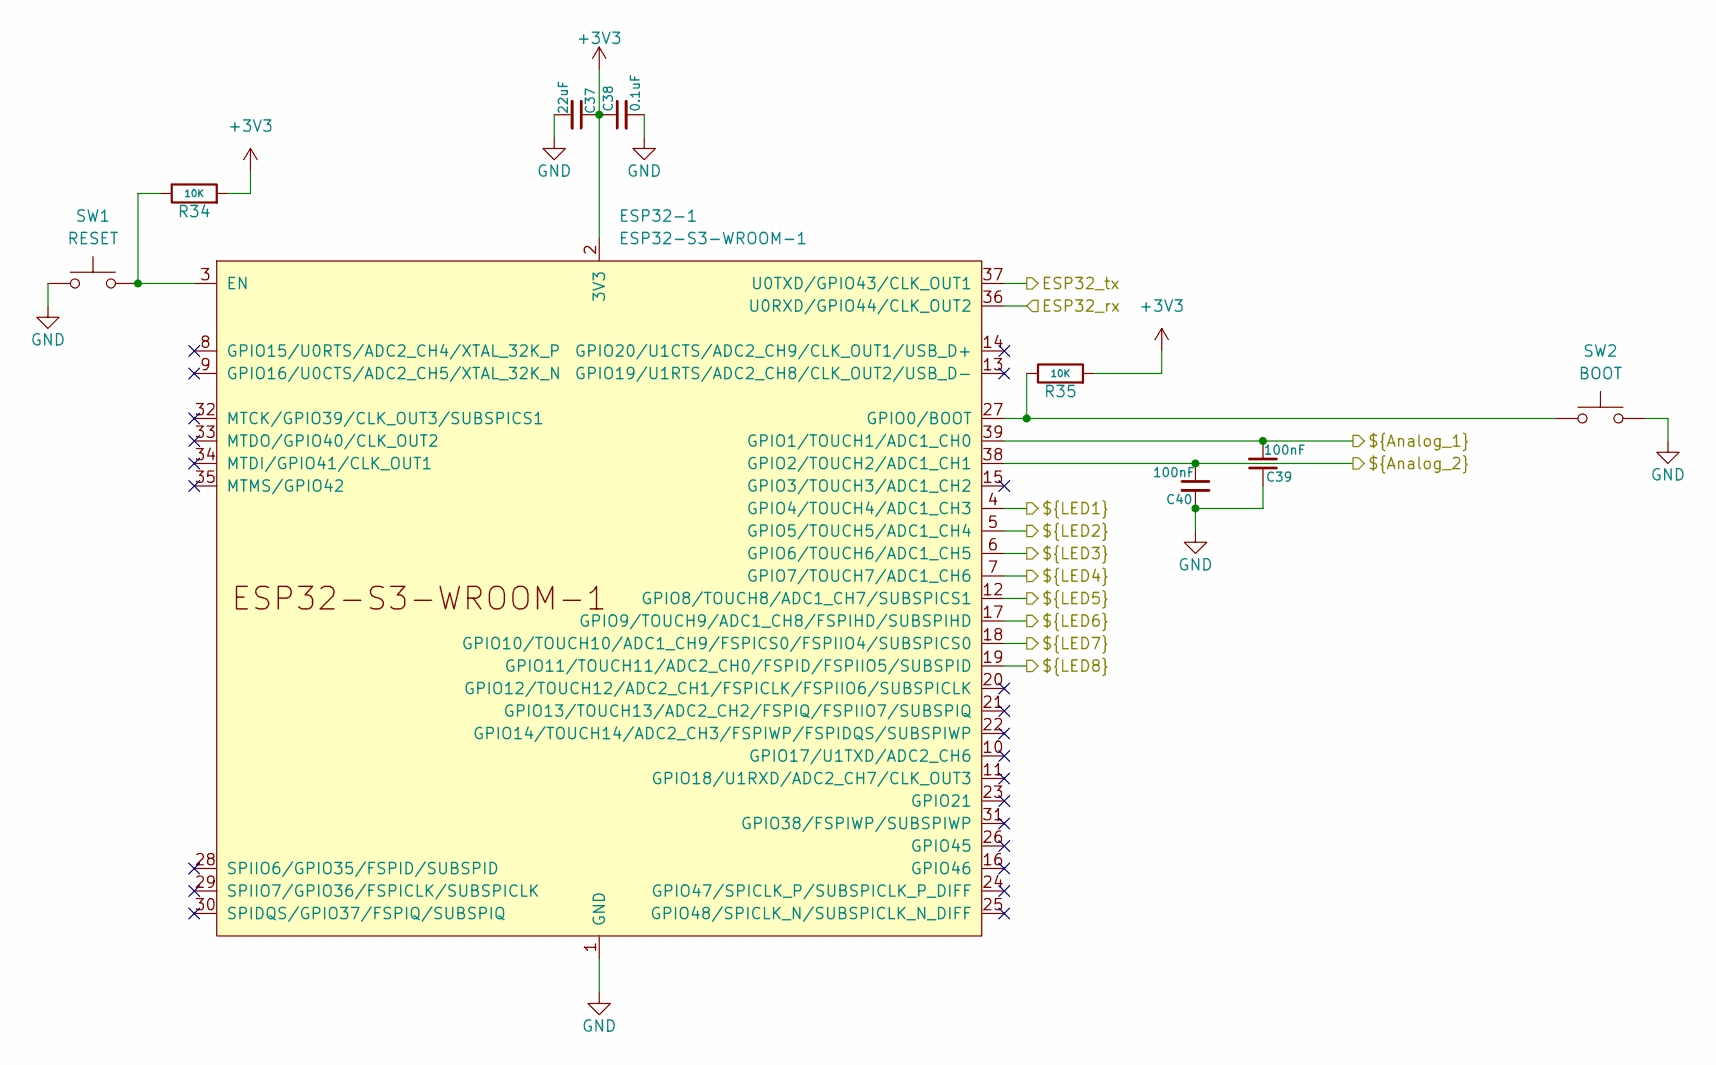
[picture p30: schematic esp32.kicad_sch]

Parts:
C37: 22uF; C_0805_2012Metric; LCSC Part # C86816
C38: 0.1uF; C_0805_2012Metric; LCSC Part # C86041
C39, C40: 100nF; C_0402_1005Metric; LCSC Part # C60474
ESP32-1: ESP32-S3-WROOM-1; ESP32-S3-WROOM-1U; LCSC Part # C3013946
R34, R35: 10K; R_0402_1005Metric; LCSC Part # C60490
SW1: RESET; SW_PUSH_1P1T_6x3.5mm_H5.0_APEM_MJTP1250; LCSC Part # C500070
SW2: BOOT; SW_PUSH_1P1T_6x3.5mm_H5.0_APEM_MJTP1250; LCSC Part # C500070

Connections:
+3V3: C37.1, C38.1, ESP32-1.2 (3V3), R34.2, R35.2; also elsewhere on the board
/ESP32-S3-WROOM-1 No. 1/ESP32_tx: ESP32-1.37 (U0TXD/GPIO43/CLK_OUT1); also elsewhere on the board
/ESP32-S3-WROOM-1 No. 1/NC: C40.1, ESP32-1.38 (GPIO2/TOUCH2/ADC1_CH1)
/ESP32_1_rx: ESP32-1.36 (U0RXD/GPIO44/CLK_OUT2); also elsewhere on the board
/Led1_output: ESP32-1.4 (GPIO4/TOUCH4/ADC1_CH3); also elsewhere on the board
/Led2_output: ESP32-1.5 (GPIO5/TOUCH5/ADC1_CH4); also elsewhere on the board
/Led3_output: ESP32-1.6 (GPIO6/TOUCH6/ADC1_CH5); also elsewhere on the board
/Led4_output: ESP32-1.7 (GPIO7/TOUCH7/ADC1_CH6); also elsewhere on the board
/Led5_output: ESP32-1.12 (GPIO8/TOUCH8/ADC1_CH7/SUBSPICS1); also elsewhere on the board
/Led6_output: ESP32-1.17 (GPIO9/TOUCH9/ADC1_CH8/FSPIHD/SUBSPIHD); also elsewhere on the board
/Led13_output: ESP32-1.18 (GPIO10/TOUCH10/ADC1_CH9/FSPICS0/FSPIIO4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); also elsewhere on the board
/Led14_output: ESP32-1.19 (GPIO11/TOUCH11/ADC2_CH0/FSPID/FSPIIO5/S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); also elsewhere on the board
/Water_sensor_input: C39.2, ESP32-1.39 (GPIO1/TOUCH1/ADC1_CH0); also elsewhere on the board
GND: C37.2, C38.2, C39.1, C40.2, ESP32-1.1 (GND), ESP32-1.40 (GND), ESP32-1.41 (GND), SW1.1, SW2.1; also elsewhere on the board
unnamed: ESP32-1.3 (EN), R34.1, SW1.2
unnamed: ESP32-1.27 (GPIO0/BOOT), R35.1, SW2.2

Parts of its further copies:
C41: 22uF; C_0805_2012Metric; LCSC Part # C86816
C42: 0.1uF; C_0805_2012Metric; LCSC Part # C86041
C43, C44: 100nF; C_0402_1005Metric; LCSC Part # C60474
ESP32-2: ESP32-S3-WROOM-1; ESP32-S3-WROOM-1U; LCSC Part # C3013946
R36, R37: 10K; R_0402_1005Metric; LCSC Part # C60490
SW3: RESET; SW_PUSH_1P1T_6x3.5mm_H5.0_APEM_MJTP1250; LCSC Part # C500070
SW4: BOOT; SW_PUSH_1P1T_6x3.5mm_H5.0_APEM_MJTP1250; LCSC Part # C500070

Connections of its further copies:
+3V3: C41.1, C42.1, ESP32-2.2 (3V3), R36.2, R37.2; also elsewhere on the board
/Analog_input_1: C43.2, ESP32-2.39 (GPIO1/TOUCH1/ADC1_CH0); also elsewhere on the board
/Analog_input_2: C44.1, ESP32-2.38 (GPIO2/TOUCH2/ADC1_CH1); also elsewhere on the board
/ESP32-S3-WROOM-1 No. 2/ESP32_tx: ESP32-2.37 (U0TXD/GPIO43/CLK_OUT1); also elsewhere on the board
/ESP32_2_rx: ESP32-2.36 (U0RXD/GPIO44/CLK_OUT2); also elsewhere on the board
/Led7_output: ESP32-2.4 (GPIO4/TOUCH4/ADC1_CH3); also elsewhere on the board
/Led8_output: ESP32-2.5 (GPIO5/TOUCH5/ADC1_CH4); also elsewhere on the board
/Led9_output: ESP32-2.6 (GPIO6/TOUCH6/ADC1_CH5); also elsewhere on the board
/Led10_output: ESP32-2.7 (GPIO7/TOUCH7/ADC1_CH6); also elsewhere on the board
/Led11_output: ESP32-2.12 (GPIO8/TOUCH8/ADC1_CH7/SUBSPICS1); also elsewhere on the board
/Led12_output: ESP32-2.17 (GPIO9/TOUCH9/ADC1_CH8/FSPIHD/SUBSPIHD); also elsewhere on the board
/Led15_output: ESP32-2.18 (GPIO10/TOUCH10/ADC1_CH9/FSPICS0/FSPIIO4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); also elsewhere on the board
/Led16_output: ESP32-2.19 (GPIO11/TOUCH11/ADC2_CH0/FSPID/FSPIIO5/S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); also elsewhere on the board
GND: C41.2, C42.2, C43.1, C44.2, ESP32-2.1 (GND), ESP32-2.40 (GND), ESP32-2.41 (GND), SW3.1, SW4.1; also elsewhere on the board
unnamed: ESP32-2.3 (EN), R36.1, SW3.2
unnamed: ESP32-2.27 (GPIO0/BOOT), R37.1, SW4.2

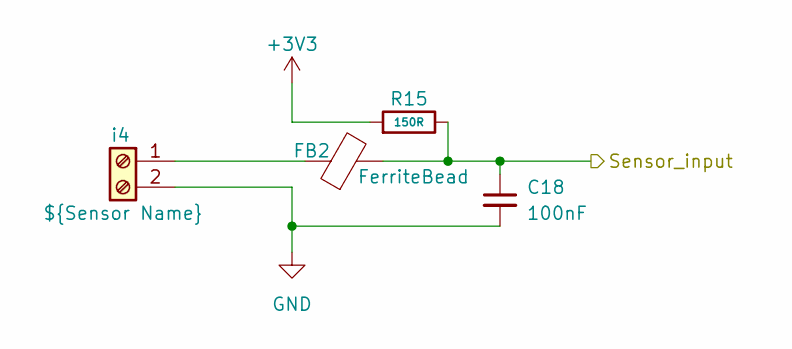
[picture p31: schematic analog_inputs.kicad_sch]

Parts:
C18: 100nF; C_0603_1608Metric; LCSC Part # C1590
FB2: FerriteBead; L_0603_1608Metric; LCSC Part # C1002
R15: 150R; R_0805_2012Metric; LCSC Part # C17471
i4: ${Sensor Name}; TerminalBlock_Phoenix_MKDS-1,5-2-5.08_1x02_P5.08mm_Horizont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; LCSC Part # C8445

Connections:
+3V3: R15.2; also elsewhere on the board
/Water_sensor_input: C18.1, FB2.2, R15.1; also elsewhere on the board
GND: C18.2, i4.2; also elsewhere on the board
unnamed: FB2.1, i4.1

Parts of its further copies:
C19, C20: 100nF; C_0603_1608Metric; LCSC Part # C1590
FB3, FB4: FerriteBead; L_0603_1608Metric; LCSC Part # C1002
R16, R17: 150R; R_0805_2012Metric; LCSC Part # C17471

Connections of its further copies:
+3V3: R16.2, R17.2; also elsewhere on the board
/Analog_input_1: C19.1, FB3.2, R16.1; also elsewhere on the board
/Analog_input_2: C20.1, FB4.2, R17.1; also elsewhere on the board
GND: C19.2, C20.2; also elsewhere on the board
unnamed 182: FB3.1; also elsewhere on the board
unnamed 183: FB4.1; also elsewhere on the board

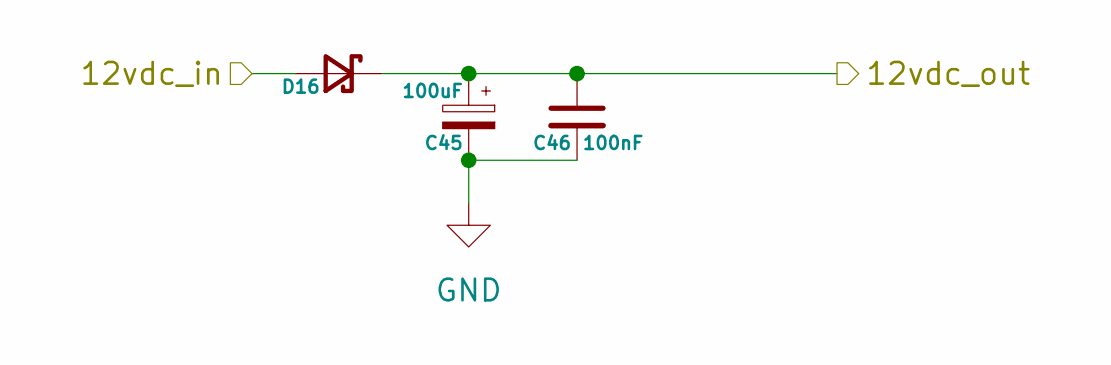
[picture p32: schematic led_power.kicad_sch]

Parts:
C45: 100uF; CP_Radial_D6.3mm_P2.50mm; LCSC Part # C44587
C46: 100nF; C_0805_2012Metric; LCSC Part # C49678
D16: D_PowerDI-5; LCSC Part # C2759901

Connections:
/LED Power 1/12vdc_in: D16.2 (A); also elsewhere on the board
/LED Power 1/12vdc_out: C45.1, C46.1, D16.1 (K); also elsewhere on the board
GND: C45.2, C46.2; also elsewhere on the board

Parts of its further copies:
C47, C49, C51: 100uF; CP_Radial_D6.3mm_P2.50mm; LCSC Part # C44587
C48, C50, C52: 100nF; C_0805_2012Metric; LCSC Part # C49678

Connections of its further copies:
/LED Power 2/12vdc_out: C47.1, C48.1; also elsewhere on the board
/LED Power 3/12vdc_out: C49.1, C50.1; also elsewhere on the board
/LED Power 4/12vdc_out: C51.1, C52.1; also elsewhere on the board
GND: C47.2, C48.2, C49.2, C50.2, C51.2, C52.2; also elsewhere on the board

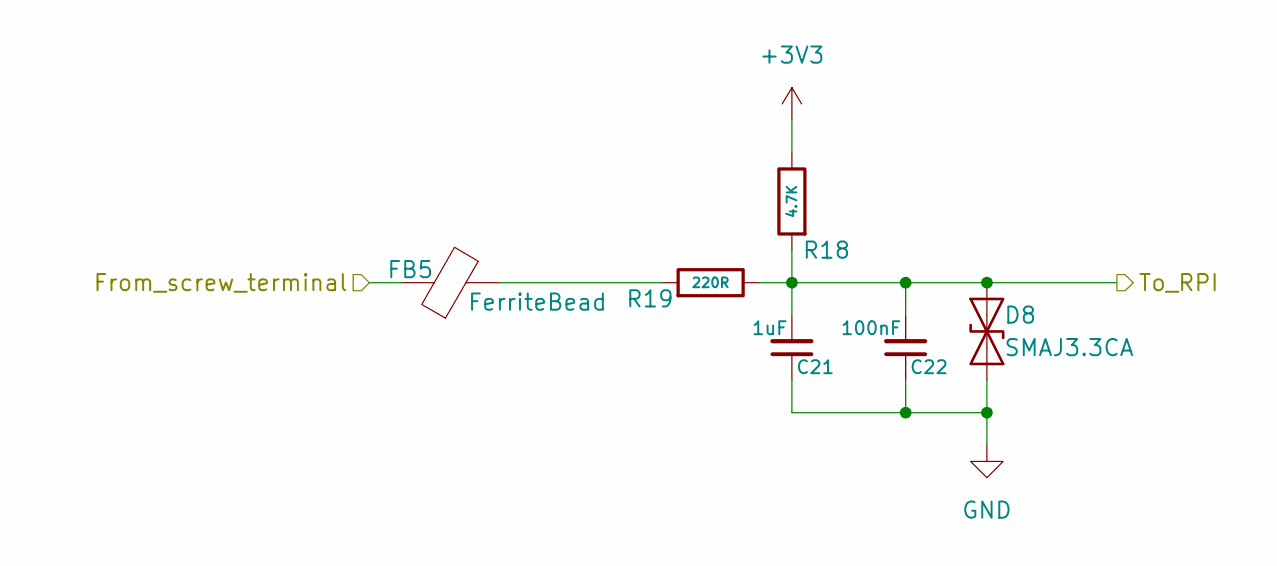
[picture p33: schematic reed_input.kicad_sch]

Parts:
C21: 1uF; C_0805_2012Metric; LCSC Part # C91185
C22: 100nF; C_0805_2012Metric; LCSC Part # C49678
D8: SMAJ3.3CA; D_SMA; LCSC Part # C18199545
FB5: FerriteBead; L_0603_1608Metric; LCSC Part # C1002
R18: 4.7K; R_0805_2012Metric; LCSC Part # C17673
R19: 220R; R_0805_2012Metric; LCSC Part # C17557

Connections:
+3V3: R18.1; also elsewhere on the board
/Reed1_input: C21.2, C22.2, D8.2 (A2), R18.2, R19.1; also elsewhere on the board
/Reed Switch 1/From_screw_terminal: FB5.1; also elsewhere on the board
GND: C21.1, C22.1, D8.1 (A1); also elsewhere on the board
unnamed: FB5.2, R19.2

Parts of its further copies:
C23, C25, C27, C29, C31, C33, C35: 1uF; C_0805_2012Metric; LCSC Part # C91185
C24, C26, C28, C30, C32, C34, C36: 100nF; C_0805_2012Metric; LCSC Part # C49678
D9, D10, D11, D12, D13, D14, D15: SMAJ3.3CA; D_SMA; LCSC Part # C18199545
FB6, FB7, FB8, FB9, FB10, FB11, FB12: FerriteBead; L_0603_1608Metric; LCSC Part # C1002
R20, R22, R24, R26, R28, R30, R32: 4.7K; R_0805_2012Metric; LCSC Part # C17673
R21, R23, R25, R27, R29, R31, R33: 220R; R_0805_2012Metric; LCSC Part # C17557

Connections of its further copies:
+3V3: R20.1, R22.1, R24.1, R26.1, R28.1, R30.1, R32.1; also elsewhere on the board
/Reed2_input: C23.2, C24.2, D9.2 (A2), R20.2, R21.1; also elsewhere on the board
/Reed3_input: C25.2, C26.2, D10.2 (A2), R22.2, R23.1; also elsewhere on the board
/Reed4_input: C27.2, C28.2, D11.2 (A2), R24.2, R25.1; also elsewhere on the board
/Reed5_input: C29.2, C30.2, D12.2 (A2), R26.2, R27.1; also elsewhere on the board
/Reed6_input: C31.2, C32.2, D13.2 (A2), R28.2, R29.1; also elsewhere on the board
/Reed7_input: C33.2, C34.2, D14.2 (A2), R30.2, R31.1; also elsewhere on the board
/Reed8_input: C35.2, C36.2, D15.2 (A2), R32.2, R33.1; also elsewhere on the board
/Reed Switch 2/From_screw_terminal: FB6.1; also elsewhere on the board
/Reed Switch 3/From_screw_terminal: FB7.1; also elsewhere on the board
/Reed Switch 4/From_screw_terminal: FB8.1; also elsewhere on the board
/Reed Switch 5/From_screw_terminal: FB9.1; also elsewhere on the board
/Reed Switch 6/From_screw_terminal: FB10.1; also elsewhere on the board
/Reed Switch 7/From_screw_terminal: FB11.1; also elsewhere on the board
/Reed Switch 8/From_screw_terminal: FB12.1; also elsewhere on the board
GND: C23.1, C24.1, C25.1, C26.1, C27.1, C28.1, C29.1, C30.1, C31.1, C32.1, C33.1, C34.1, C35.1, C36.1, D9.1 (A1), D10.1 (A1), D11.1 (A1), D12.1 (A1), D13.1 (A1), D14.1 (A1), D15.1 (A1); also elsewhere on the board
unnamed: FB6.2, R21.2
unnamed: FB7.2, R23.2
unnamed: FB8.2, R25.2
unnamed: FB9.2, R27.2
unnamed: FB10.2, R29.2
unnamed: FB11.2, R31.2
unnamed: FB12.2, R33.2

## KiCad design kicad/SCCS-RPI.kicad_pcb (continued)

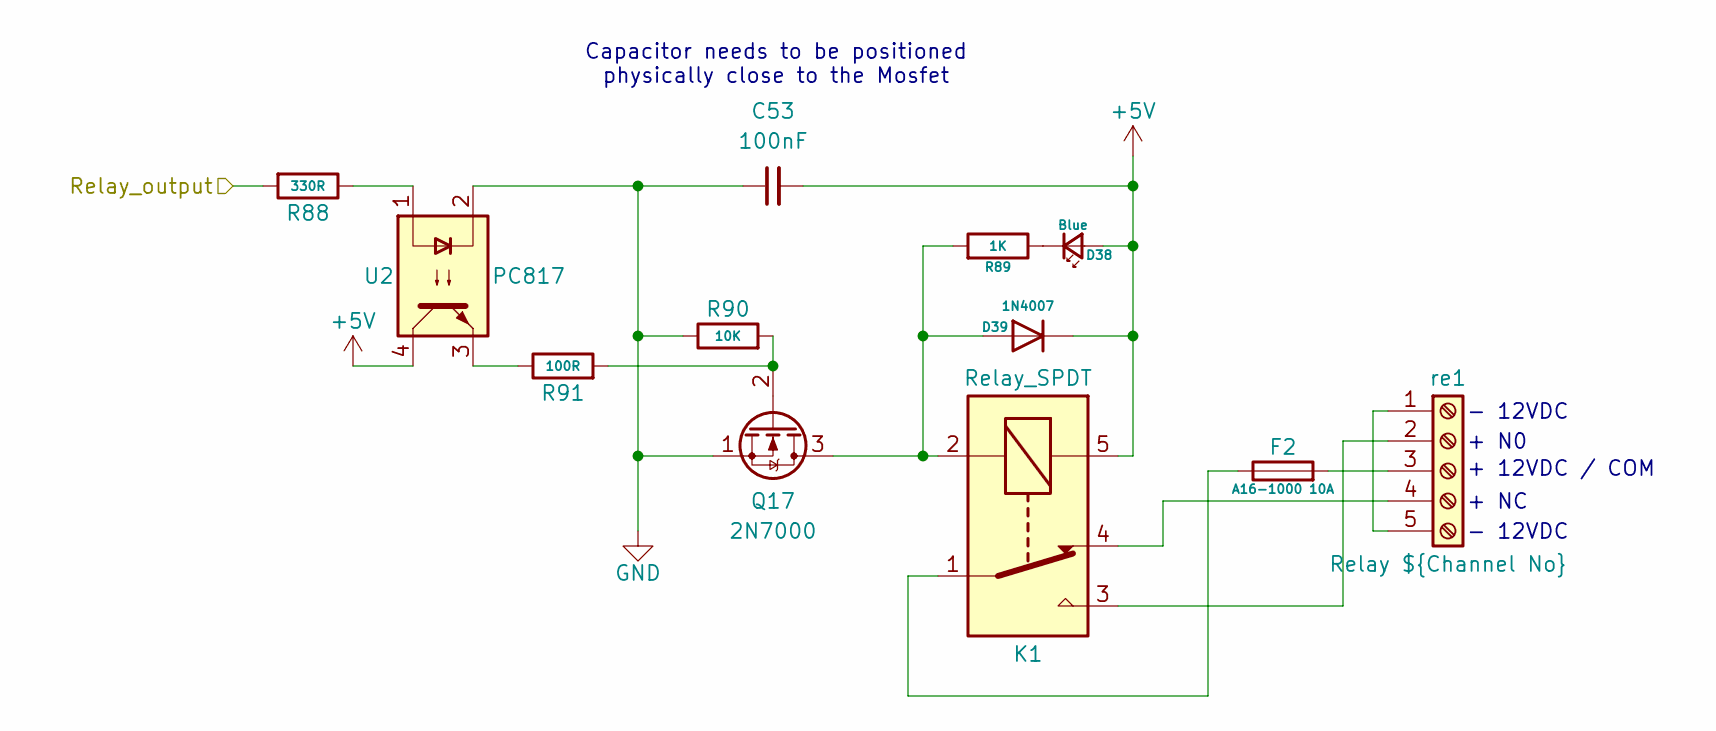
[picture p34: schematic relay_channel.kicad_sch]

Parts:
C53: 100nF; C_0805_2012Metric; LCSC Part # C49678
D38: Blue; LED_0603_1608Metric; LCSC Part # C2288
D39: 1N4007; D_SMA; LCSC Part # C64915
F2: A16-1000 10A; Fuse_Bourns_MF-RG1000; LCSC Part # C135398
K1: Relay_SPDT; Relay_SPDT_SANYOU_SRD_Series_Form_C; LCSC Part # C35449
Q17: 2N7000; TO-92_Inline; LCSC Part # C9114
R88: 330R; R_0805_2012Metric; LCSC Part # C17630
R89: 1K; R_0603_1608Metric; LCSC Part # C5123612
R90: 10K; R_0805_2012Metric; LCSC Part # C17414
R91: 100R; R_0805_2012Metric; LCSC Part # C17408
U2: PC817; DIP-4_W7.62mm; LCSC Part # C5353
re1: Relay ${Channel No}; TerminalBlock_Phoenix_MKDS-3-5-5.08_1x05_P5.08mm_Horizontal; LCSC Part # C8423

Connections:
+5V: C53.2, D38.2 (A), D39.1 (K), K1.5, U2.4; also elsewhere on the board
/Relay1_output: R88.2; also elsewhere on the board
GND: C53.1, Q17.1 (S), R90.1, U2.2; also elsewhere on the board
unnamed: D38.1 (K), R89.1
unnamed: D39.2 (A), K1.2, Q17.3 (D), R89.2
unnamed: F2.1, K1.1
unnamed: Q17.2 (G), R90.2, R91.2
unnamed: R88.1, U2.1
unnamed: R91.1, U2.3
unnamed: re1.1, re1.5
unnamed: K1.3, re1.2
unnamed: F2.2, re1.3
unnamed: K1.4, re1.4

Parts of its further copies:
C54, C55, C56: 100nF; C_0805_2012Metric; LCSC Part # C49678
D40, D42, D44: Blue; LED_0603_1608Metric; LCSC Part # C2288
D41, D43, D45: 1N4007; D_SMA; LCSC Part # C64915
F3, F4, F5: A16-1000 10A; Fuse_Bourns_MF-RG1000; LCSC Part # C135398
K2, K3, K4: Relay_SPDT; Relay_SPDT_SANYOU_SRD_Series_Form_C; LCSC Part # C35449
Q18, Q19, Q20: 2N7000; TO-92_Inline; LCSC Part # C9114
R92, R96, R100: 330R; R_0805_2012Metric; LCSC Part # C17630
R93, R97, R101: 1K; R_0603_1608Metric; LCSC Part # C5123612
R94, R98, R102: 10K; R_0805_2012Metric; LCSC Part # C17414
R95, R99, R103: 100R; R_0805_2012Metric; LCSC Part # C17408
U3, U4, U5: PC817; DIP-4_W7.62mm; LCSC Part # C5353

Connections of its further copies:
+5V: C54.2, C55.2, C56.2, D40.2 (A), D41.1 (K), D42.2 (A), D43.1 (K), D44.2 (A), D45.1 (K), K2.5, K3.5, K4.5, U3.4, U4.4, U5.4; also elsewhere on the board
/Relay2_output: R92.2; also elsewhere on the board
/Relay3_output: R96.2; also elsewhere on the board
/Relay4_output: R100.2; also elsewhere on the board
GND: C54.1, C55.1, C56.1, Q18.1 (S), Q19.1 (S), Q20.1 (S), R94.1, R98.1, R102.1, U3.2, U4.2, U5.2; also elsewhere on the board
unnamed: D40.1 (K), R93.1
unnamed: D41.2 (A), K2.2, Q18.3 (D), R93.2
unnamed: D42.1 (K), R97.1
unnamed: D43.2 (A), K3.2, Q19.3 (D), R97.2
unnamed: D44.1 (K), R101.1
unnamed: D45.2 (A), K4.2, Q20.3 (D), R101.2
unnamed: F3.1, K2.1
unnamed: F4.1, K3.1
unnamed: F5.1, K4.1
unnamed: Q18.2 (G), R94.2, R95.2
unnamed: Q19.2 (G), R98.2, R99.2
unnamed: Q20.2 (G), R102.2, R103.2
unnamed: R92.1, U3.1
unnamed: R95.1, U3.3
unnamed: R96.1, U4.1
unnamed: R99.1, U4.3
unnamed: R100.1, U5.1
unnamed: R103.1, U5.3
unnamed 189: K2.3; also elsewhere on the board
unnamed 190: F3.2; also elsewhere on the board
unnamed 191: K2.4; also elsewhere on the board
unnamed 193: K3.3; also elsewhere on the board
unnamed 194: F4.2; also elsewhere on the board
unnamed 195: K3.4; also elsewhere on the board
unnamed 197: K4.3; also elsewhere on the board
unnamed 198: F5.2; also elsewhere on the board
unnamed 199: K4.4; also elsewhere on the board

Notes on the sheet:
+ NC
+ N0
+ 12VDC / COM
- 12VDC
Capacitor needs to be positioned physically close to the Mosfet

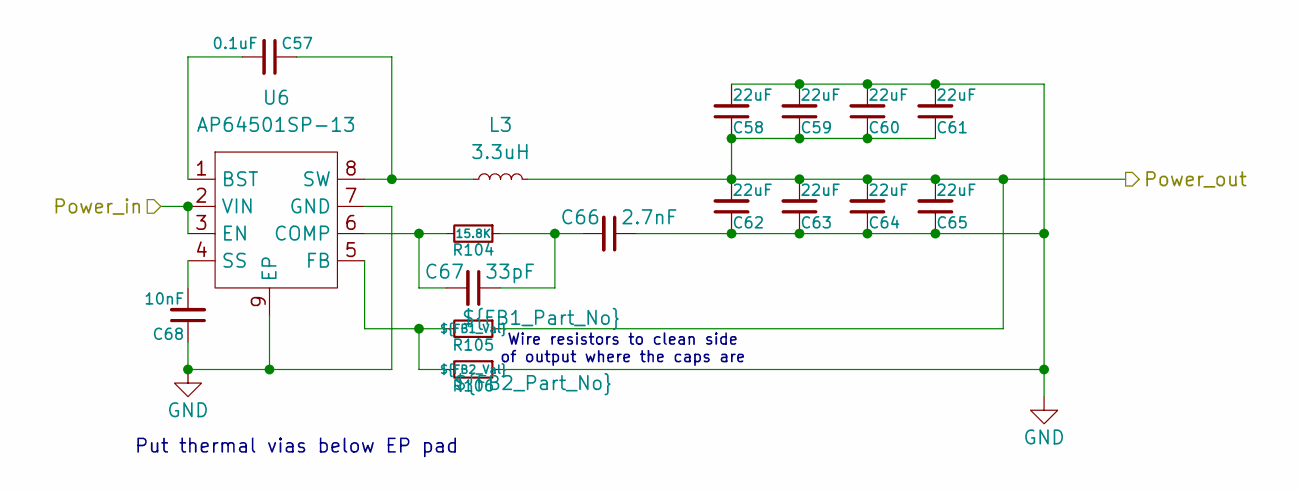
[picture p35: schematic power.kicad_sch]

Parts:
C57: 0.1uF; C_0805_2012Metric; LCSC Part # C86041
C58, C59, C60, C61, C62, C63, C64, C65: 22uF; C_0805_2012Metric; LCSC Part # C86816
C66: 2.7nF; C_0805_2012Metric; LCSC Part # C113859
C67: 33pF; C_0805_2012Metric; LCSC Part # C541516
C68: 10nF; C_0805_2012Metric; LCSC Part # C237168
L3: 3.3uH; L_SXN_SMDRI127; LCSC Part # C24550
R104: 15.8K; R_0805_2012Metric; LCSC Part # C17468
R105: ${FB1_Val}; R_0805_2012Metric; LCSC Part # ${FB1_Part_No}
R106: ${FB2_Val}; R_0805_2012Metric; LCSC Part # ${FB2_Part_No}
U6: AP64501SP-13; SOIC-8-1EP_3.9x4.9mm_P1.27mm_EP2.95x4.9mm_Mask2.71x3.4mm_Th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; LCSC Part # C2071517

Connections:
+5V: C58.1, C59.1, C60.1, C61.1, C62.2, C63.2, C64.2, C65.2, L3.2, R105.1; also elsewhere on the board
/Power - 3V3/Power_in: U6.2 (VIN), U6.3 (EN); also elsewhere on the board
GND: C58.2, C59.2, C60.2, C61.2, C62.1, C63.1, C64.1, C65.1, C66.1, C68.1, R106.1, U6.7 (GND), U6.9 (EP); also elsewhere on the board
unnamed: C66.2, C67.1, R104.1
unnamed: C57.2, U6.1 (BST)
unnamed: C67.2, R104.2, U6.6 (COMP)
unnamed: R105.2, R106.2, U6.5 (FB)
unnamed: C68.2, U6.4 (SS)
unnamed: C57.1, L3.1, U6.8 (SW)

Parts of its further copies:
C69: 0.1uF; C_0805_2012Metric; LCSC Part # C86041
C70, C71, C72, C73, C74, C75, C76, C77: 22uF; C_0805_2012Metric; LCSC Part # C86816
C78: 2.7nF; C_0805_2012Metric; LCSC Part # C113859
C79: 33pF; C_0805_2012Metric; LCSC Part # C541516
C80: 10nF; C_0805_2012Metric; LCSC Part # C237168
L4: 3.3uH; L_SXN_SMDRI127; LCSC Part # C24550
R107: 15.8K; R_0805_2012Metric; LCSC Part # C17468
U7: AP64501SP-13; SOIC-8-1EP_3.9x4.9mm_P1.27mm_EP2.95x4.9mm_Mask2.71x3.4mm_Th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; LCSC Part # C2071517

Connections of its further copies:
+3V3: C70.1, C71.1, C72.1, C73.1, C74.2, C75.2, C76.2, C77.2, L4.2; also elsewhere on the board
/Power - 3V3/Power_in: U7.2 (VIN), U7.3 (EN); also elsewhere on the board
GND: C70.2, C71.2, C72.2, C73.2, C74.1, C75.1, C76.1, C77.1, C78.1, C80.1, U7.7 (GND), U7.9 (EP); also elsewhere on the board
unnamed: C78.2, C79.1, R107.1
unnamed: C69.2, U7.1 (BST)
unnamed: C79.2, R107.2, U7.6 (COMP)
unnamed 177: U7.5 (FB); also elsewhere on the board
unnamed: C80.2, U7.4 (SS)
unnamed: C69.1, L4.1, U7.8 (SW)

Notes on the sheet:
Put thermal vias below EP pad
Wire resistors to clean side of output where the caps are

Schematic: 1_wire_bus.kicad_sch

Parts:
C17: 100nF; C_0805_2012Metric; LCSC Part # C49678
D7: SMAJ3.3CA; D_SMA; LCSC Part # C18199545
FB1: FerriteBead; L_0603_1608Metric; LCSC Part # C1002
R14: 2.2K; R_0805_2012Metric; LCSC Part # C17520
i3: Temp Sensors; TerminalBlock_Phoenix_MKDS-1,5-3-5.08_1x03_P5.08mm_Horizont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; LCSC Part # C8412

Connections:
+3V3: C17.1, R14.2, i3.1; also elsewhere on the board
/Temp1_sensor_input: D7.2 (A2), FB1.2, R14.1; also elsewhere on the board
GND: C17.2, D7.1 (A1), i3.3; also elsewhere on the board
unnamed: FB1.1, i3.2

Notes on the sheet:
Yellow/Data
Red/+
Black/-

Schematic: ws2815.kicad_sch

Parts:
D36: SMAJ5.0CA; D_SMA; LCSC Part # C78402
R86: 33R; R_0805_2012Metric; LCSC Part # C17634

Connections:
/WS281X Channel 1/WS281X_In: R86.1; also elsewhere on the board
/WS281X Channel 1/WS281X_Out: D36.2 (A2), R86.2; also elsewhere on the board
GND: D36.1 (A1); also elsewhere on the board

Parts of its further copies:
D37: SMAJ5.0CA; D_SMA; LCSC Part # C78402
R87: 33R; R_0805_2012Metric; LCSC Part # C17634

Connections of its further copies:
/WS281X Channel 2/WS281X_In: R87.1; also elsewhere on the board
/WS281X Channel 2/WS281X_Out: D37.2 (A2), R87.2; also elsewhere on the board
GND: D37.1 (A1); also elsewhere on the board

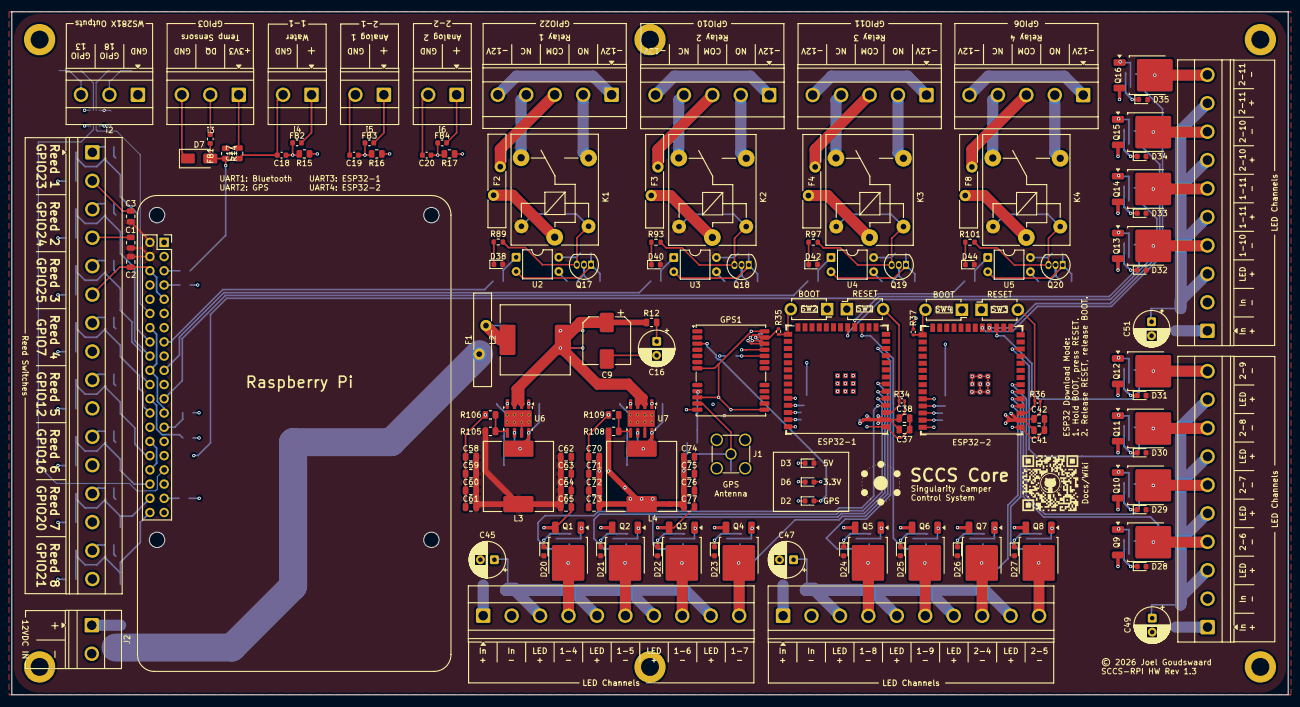
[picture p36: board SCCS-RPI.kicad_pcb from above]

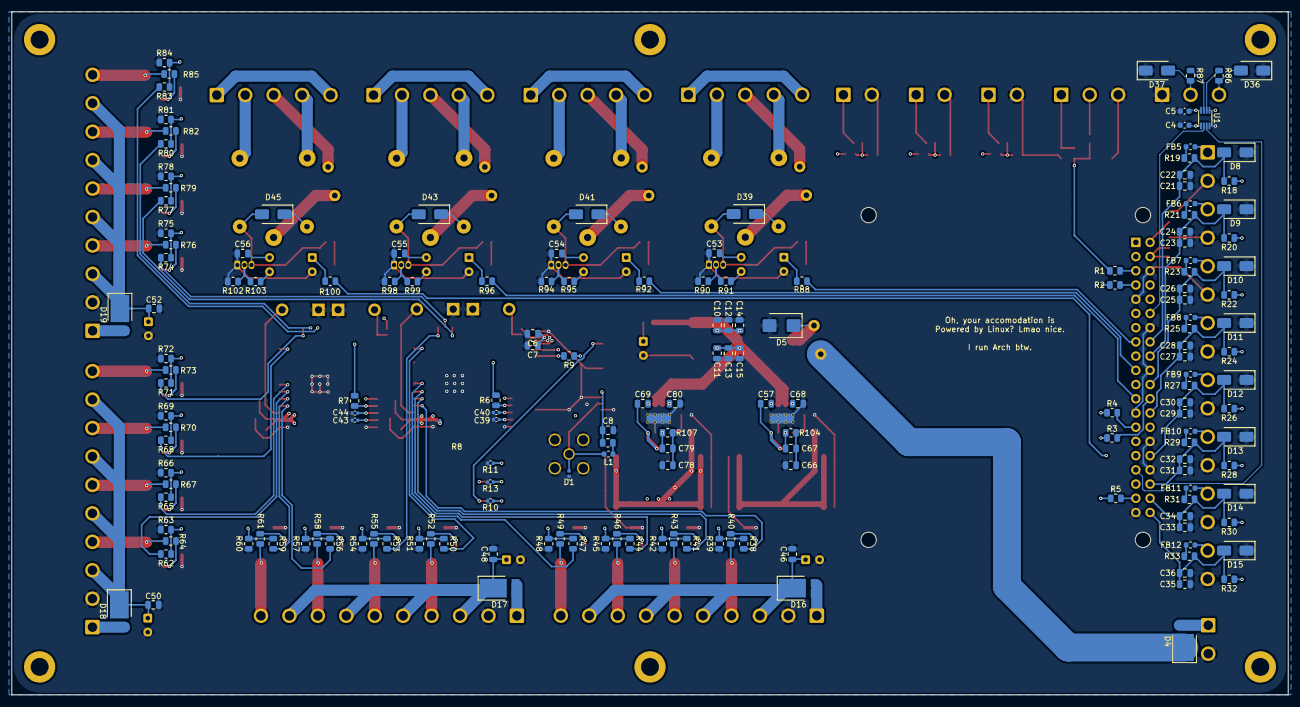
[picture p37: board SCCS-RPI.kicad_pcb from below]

Board: 4 copper layers, 228.0 x 122.0 mm, 311 parts (170 on the bottom side), 200 nets.

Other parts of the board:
D17, D18, D19: D_PowerDI-5
D21, D29: Red; LED_0603_1608Metric
D22, D30: Green; LED_0603_1608Metric
D23, D24, D25, D26, D27, D28, D31, D32, D33, D34, D35: White; LED_0603_1608Metric
R108: 100K; R_0805_2012Metric
R109: 32.4K; R_0805_2012Metric
RP?: Raspberry_Pi_2_3; raspberrypi_4
i5: Analog 1; TerminalBlock_Phoenix_MKDS-1,5-2-5.08_1x02_P5.08mm_Horizont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
i6: Analog 2; TerminalBlock_Phoenix_MKDS-1,5-2-5.08_1x02_P5.08mm_Horizont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
re2: Relay 2; TerminalBlock_Phoenix_MKDS-3-5-5.08_1x05_P5.08mm_Horizontal
re3: Relay 3; TerminalBlock_Phoenix_MKDS-3-5-5.08_1x05_P5.08mm_Horizontal
re4: Relay 4; TerminalBlock_Phoenix_MKDS-3-5-5.08_1x05_P5.08mm_Horizontal

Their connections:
+3V3: R108.1; also elsewhere on the board
+5V: D21.2 (A), D22.2 (A), D23.2 (A), D24.2 (A), D25.2 (A), D26.2 (A), D27.2 (A), D28.2 (A), D29.2 (A), D30.2 (A), D31.2 (A), D32.2 (A), D33.2 (A), D34.2 (A), D35.2 (A); also elsewhere on the board
/LED Power 2/12vdc_in: D17.2 (A); also elsewhere on the board
/LED Power 2/12vdc_out: D17.1 (K); also elsewhere on the board
/LED Power 3/12vdc_in: D18.2 (A); also elsewhere on the board
/LED Power 3/12vdc_out: D18.1 (K); also elsewhere on the board
/LED Power 4/12vdc_in: D19.2 (A); also elsewhere on the board
/LED Power 4/12vdc_out: D19.1 (K); also elsewhere on the board
GND: R109.1, i5.2, i6.2; also elsewhere on the board
unnamed 95: D21.1 (K); also elsewhere on the board
unnamed 96: D22.1 (K); also elsewhere on the board
unnamed 97: D23.1 (K); also elsewhere on the board
unnamed 98: D24.1 (K); also elsewhere on the board
unnamed 99: D25.1 (K); also elsewhere on the board
unnamed 100: D26.1 (K); also elsewhere on the board
unnamed 101: D27.1 (K); also elsewhere on the board
unnamed 102: D28.1 (K); also elsewhere on the board
unnamed 103: D29.1 (K); also elsewhere on the board
unnamed 104: D30.1 (K); also elsewhere on the board
unnamed 105: D31.1 (K); also elsewhere on the board
unnamed 106: D32.1 (K); also elsewhere on the board
unnamed 107: D33.1 (K); also elsewhere on the board
unnamed 108: D34.1 (K); also elsewhere on the board
unnamed 109: D35.1 (K); also elsewhere on the board
unnamed 177: R108.2, R109.2; also elsewhere on the board
unnamed 182: i5.1; also elsewhere on the board
unnamed 183: i6.1; also elsewhere on the board
unnamed: re2.1, re2.5
unnamed 189: re2.2; also elsewhere on the board
unnamed 190: re2.3; also elsewhere on the board
unnamed 191: re2.4; also elsewhere on the board
unnamed: re3.1, re3.5
unnamed 193: re3.2; also elsewhere on the board
unnamed 194: re3.3; also elsewhere on the board
unnamed 195: re3.4; also elsewhere on the board
unnamed: re4.1, re4.5
unnamed 197: re4.2; also elsewhere on the board
unnamed 198: re4.3; also elsewhere on the board
unnamed 199: re4.4; also elsewhere on the board

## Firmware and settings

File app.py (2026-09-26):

"""SCCS — Flask + SocketIO bridge for lighting/relay control."""

from __future__ import annotations

import atexit
import logging
import os
import subprocess
import sys
import threading
from datetime import datetime
from urllib.parse import urlparse

from flask import Flask, Response, jsonify, render_template, request, url_for
from flask_cors import CORS
from flask_socketio import SocketIO, emit

from bridge.runtime import SCCSRuntime
from gps import get_gps_status, set_gps_module
from modules.config import config
from modules.gps import GPSModule
from modules.logger import setup_logging
from modules.phases import PhaseManager
from modules.sensors import SensorManager
from modules.toasts import ToastManager
from modules.ui_assets import (
    apply_gzip,
    fontawesome_css,
    javascript_bundle,
    stylesheet_bundle,
    template_asset_versions,
    theme_css,
)
from modules.ui_state import ConfigManager

import modules.toasts
from network import build_network_status
from sonos import get_sonos_status, set_muted, set_sonos_manager, set_transport, set_volume
from system import get_system_status, set_gps_module as set_system_gps, set_runtime, set_victron_module
from victron import get_power_status, set_victron_manager as set_power_victron
from weather import get_weather_status, set_gps_module as set_weather_gps
from wifi import (
    connect_wifi,
    disconnect_wifi,
    get_wifi_status,
    scan_wifi_networks,
    set_preferred_uplink,
)
from modules.homekit import HomeKitManager
from modules.matter import MatterManager

logger = setup_logging(config)

if config.getboolean("logging", "suppress_werkzeug", fallback=True):
    logging.getLogger("werkzeug").setLevel(logging.WARNING)
if config.getboolean("logging", "suppress_engineio", fallback=True):
    logging.getLogger("engineio").setLevel(logging.WARNING)
if config.getboolean("logging", "suppress_socketio", fallback=True):
    logging.getLogger("socketio").setLevel(logging.WARNING)


def log_exception(exc_type, exc_value, exc_traceback):
    if issubclass(exc_type, KeyboardInterrupt):
        sys.__excepthook__(exc_type, exc_value, exc_traceback)
        return
    logger.critical("Unhandled exception", exc_info=(exc_type, exc_value, exc_traceback))


sys.excepthook = log_exception


def _patch_engineio_werkzeug_websocket() -> None:
    """Engine.IO hijacks the socket for WebSocket upgrades without calling WSGI start_response.

    Werkzeug then raises AssertionError: write() before start_response when the
    handler returns. Signal a dropped connection instead (same idea as gunicorn's
    StopIteration path in engineio's SimpleWebSocketWSGI).
    """
    from engineio.async_drivers import _websocket_wsgi as wswsgi

    if getattr(wswsgi.SimpleWebSocketWSGI, "_sccs_werkzeug_patch", False):
        return

    _orig_call = wswsgi.SimpleWebSocketWSGI.__call__

    def __call__(self, environ, start_response):
        ret = _orig_call(self, environ, start_response)
        if getattr(getattr(self, "ws", None), "mode", None) == "werkzeug":
            raise ConnectionError("WebSocket connection handled outside WSGI")
        return ret

    wswsgi.SimpleWebSocketWSGI.__call__ = __call__
    wswsgi.SimpleWebSocketWSGI._sccs_werkzeug_patch = True


_patch_engineio_werkzeug_websocket()

app = Flask(__name__)
app.config["SECRET_KEY"] = config.get("system", "secret_key", fallback="sccs-secret")
CORS(app)
socketio = SocketIO(app, cors_allowed_origins="*", async_mode="threading")

debug_mode = config.getboolean("system", "debug", fallback=False)
if debug_mode:
    app.config["TEMPLATES_AUTO_RELOAD"] = True
    app.config["SEND_FILE_MAX_AGE_DEFAULT"] = 0

# Settings-tab diagnostic tools (force phase/reed, GPS simulate, toast test).
development_mode = config.getboolean("system", "development_mode", fallback=False)

toast_manager = ToastManager(config, socketio)
modules.toasts.toast_manager = toast_manager

dark_mode_config = ConfigManager("active_dark_mode.json", {"mode": "dark", "manual": False})
_default_theme = config.get("ui", "default_theme", fallback="neuglass")
if _default_theme == "base":
    _default_theme = "neuglass"
theme_config = ConfigManager("active_theme.json", {"theme": _default_theme})
current_global_theme = theme_config.load()["theme"]

runtime = SCCSRuntime(config, socketio=socketio, dark_mode_config=dark_mode_config)
set_runtime(runtime)

gps_module = None
phase_manager = None
sensor_manager = None
victron_module = None
sonos_module = None
homekit_module = None
matter_module = None
first_state_read_done = False
shutdown_event = threading.Event()
_cleanup_done = False


def _theme_sort_key(item: dict) -> tuple:
    name = item["name"].lower()
    return (0 if name.endswith("morphism") else 1, name)


def _extract_css_friendly_name(filepath: str, fallback: str) -> str:
    try:
        with open(filepath, encoding="utf-8") as handle:
            first = handle.readline().strip()
            if first.startswith("/*") and first.endswith("*/"):
                comment = first[2:-2].strip()
                if comment:
                    return comment
    except OSError:
        pass
    return fallback


def _network_status_payload() -> dict:
    start_time = getattr(app, "_start_time", None)
    return build_network_status(start_time)


def network_status_broadcaster() -> None:
    while not shutdown_event.is_set():
        try:
            socketio.emit("network_update", _network_status_payload())
        except Exception:
            pass
        if shutdown_event.wait(8.5):
            break

NAV_ITEMS = [
    {"id": "home", "label": "Home", "icon": "fa-house"},
    {"id": "lighting", "label": "Lighting", "icon": "fa-lightbulb"},
    {"id": "scenes", "label": "Scenes", "icon": "fa-wand-magic-sparkles"},
    {"id": "system", "label": "System", "icon": "fa-gear"},
]


def _cached_asset(body: bytes, mimetype: str, token: str, modified: datetime, *, immutable: bool):
    resp = Response(body, mimetype=mimetype)
    resp.set_etag(token, weak=True)
    resp.last_modified = modified
    if immutable:
        # The HTML query string changes when the sources change.
        resp.headers["Cache-Control"] = "public, max-age=31536000, immutable"
    else:
        resp.headers["Cache-Control"] = "no-cache"
    return resp.make_conditional(request)


@app.after_request
def _compress_response(response):
    return apply_gzip(response, request)


@app.route("/assets/app.css")
def ui_stylesheet():
    token, body, modified = stylesheet_bundle()
    return _cached_asset(body, "text/css; charset=utf-8", token, modified, immutable=True)


@app.route("/assets/app.js")
def ui_javascript():
    token, body, modified = javascript_bundle()
    return _cached_asset(body, "text/javascript; charset=utf-8", token, modified, immutable=True)


@app.route("/assets/fontawesome.css")
def ui_fontawesome():
    prefix = url_for("static", filename="fontawesome/webfonts/")
    token, body, modified = fontawesome_css(prefix)
    return _cached_asset(body, "text/css; charset=utf-8", token, modified, immutable=False)


@app.route("/assets/themes/<name>")
def ui_theme_css(name):
    found = theme_css(name)
    if found is None:
        return Response("Not found", status=404, mimetype="text/plain")
    token, body, modified = found
    return _cached_asset(body, "text/css; charset=utf-8", token, modified, immutable=False)


@app.context_processor
def inject_nav():
    theme_file = url_for("ui_theme_css", name="neuglass.css")
    mode = "dark"
    if phase_manager is not None:
        mode = phase_manager.get_current_dark_mode()
    return {
        "nav_items": NAV_ITEMS,
        "development_mode": development_mode,
        "color_mode": mode,
        "theme_base": theme_file.removesuffix("neuglass.css"),
        **template_asset_versions(),
    }


def _require_development_mode(action: str = "action") -> bool:
    """Gate diagnostic socket/HTTP tools when development_mode is off."""
    if development_mode:
        return True
    logger.warning("Ignored %s — [system] development_mode is false", action)
    return False


@app.route("/")
def index():
    return render_template("index.html", active_page="home")


@app.route("/api/power")
def api_power():
    return jsonify(get_power_status())


@app.route("/api/victron")
def api_victron():
    if victron_module:
        return jsonify(victron_module.get_state())
    return jsonify({"stale": True, "shunt": {"configured": False}, "mppt": {"configured": False}})


@app.route("/api/gps")
def api_gps():
    return jsonify(get_gps_status())


@app.route("/api/system")
def api_system():
    return jsonify(get_system_status())


@app.route("/api/weather")
def api_weather():
    return jsonify(get_weather_status())


@app.route("/api/network")
def api_network():
    return jsonify(_network_status_payload())


@app.route("/api/themes")
def api_get_themes():
    themes, seen = [], set()
    themes_dir = os.path.join(app.static_folder, "css", "themes")
    if os.path.isdir(themes_dir):
        for filename in sorted(os.listdir(themes_dir)):
            if not filename.endswith(".css"):
                continue
            base = filename[:-4]
            if base in seen:
                continue
            seen.add(base)
            path = os.path.join(themes_dir, filename)
            fallback = base.replace("-", " ").replace("_", " ").title()
            themes.append({"file": base, "name": _extract_css_friendly_name(path, fallback)})
    themes.sort(key=_theme_sort_key)
    return jsonify({"themes": themes})


@app.route("/api/current-theme")
def api_get_current_theme():
    return jsonify({"theme": current_global_theme})


@app.route("/api/sonos")
def api_sonos():
    return jsonify(get_sonos_status())


@app.route("/api/sonos/transport", methods=["POST"])
def api_sonos_transport():
    payload = request.get_json(silent=True) or {}
    return jsonify(set_transport(str(payload.get("action", ""))))


@app.route("/api/sonos/volume", methods=["POST"])
def api_sonos_volume():
    payload = request.get_json(silent=True) or {}
    try:
        level = int(payload.get("level", 0))
    except (TypeError, ValueError):
        level = 0
    return jsonify(set_volume(level))


@app.route("/api/sonos/mute", methods=["POST"])
def api_sonos_mute():
    payload = request.get_json(silent=True) or {}
    return jsonify(set_muted(bool(payload.get("muted"))))


@app.route("/sonos-art")
def proxy_sonos_album_art():
    art_url = request.args.get("url")
    if not art_url:
        return "Missing url", 400
    try:
        import requests

        parsed = urlparse(art_url)
        if parsed.port != 1400:
            return "Invalid", 403
        resp = requests.get(art_url, timeout=10, stream=True)
        if resp.status_code != 200:
            return "Failed", resp.status_code
        return Response(
            resp.iter_content(8192),
            content_type=resp.headers.get("content-type", "image/jpeg"),
            headers={"Cache-Control": "public, max-age=7200"},
        )
    except Exception as e:
        logger.warning(f"Sonos art proxy: {e}")
        return "Error", 502


@app.route("/api/wifi")
def api_wifi():
    return jsonify(get_wifi_status())


@app.route("/api/wifi/scan", methods=["POST"])
def api_wifi_scan():
    return jsonify(scan_wifi_networks())


@app.route("/api/wifi/connect", methods=["POST"])
def api_wifi_connect():
    payload = request.get_json(silent=True) or {}
    password = payload.get("password")
    if password is not None:
        password = str(password)
    return jsonify(connect_wifi(str(payload.get("ssid", "")), password))


@app.route("/api/wifi/disconnect", methods=["POST"])
def api_wifi_disconnect():
    return jsonify(disconnect_wifi())


@app.route("/api/wifi/prefer", methods=["POST"])
def api_wifi_prefer():
    payload = request.get_json(silent=True) or {}
    prefer = payload.get("prefer") or payload.get("uplink") or ""
    return jsonify(set_preferred_uplink(str(prefer)))


def _apply_light_change(data, *, source: str = "socket"):
    if not data or "name" not in data:
        logger.warning(f"light_change ignored ({source}) — bad payload: {data!r}")
        return None
    name = data["name"]
    if name not in runtime.compiled.light_names:
        logger.warning(f"light_change ignored ({source}) — unknown light: {name}")
        return None
    try:
        target = max(0, min(100, int(data.get("brightness", 0))))
    except (TypeError, ValueError):
        logger.warning(f"light_change ignored ({source}) — invalid brightness: {data.get('brightness')!r}")
        return None
    mode = data.get("mode", "white") if name in runtime.compiled.rgb_lights else None
    runtime.set_light_intent(name, target, mode)
    return runtime.get_ui_state()


@app.route("/api/light", methods=["POST"])
def api_light_change():
    state = _apply_light_change(request.get_json(silent=True) or {}, source="http")
    if state is None:
        return jsonify({"ok": False}), 400
    return jsonify({"ok": True, "state": state})


@app.route("/api/relay", methods=["POST"])
def api_relay_change():
    data = request.get_json(silent=True) or {}
    name = data.get("name")
    if name not in runtime.compiled.relay_names:
        logger.warning(f"relay_change ignored (http) — unknown relay: {name}")
        return jsonify({"ok": False}), 400
    runtime.set_relay_intent(name, bool(data.get("on", False)))
    return jsonify({"ok": True})


@app.route("/api/explain")
def api_explain():
    return jsonify(runtime.get_explain_json())


@app.route("/api/scenes")
def api_get_scenes():
    scenes = dict(
        sorted(runtime.compiled.scenes.items(), key=lambda item: item[1].get("order", 999))
    )
    return jsonify({
        "scenes": [
            {
                "key": k,
                "name": d["name"],
                "icon": d["icon"],
                "description": d["description"],
                "all_off": d["all_off"],
            }
            for k, d in scenes.items()
        ]
    })


@app.route("/api/scene", methods=["POST"])
def api_set_scene():
    data = request.get_json(silent=True) or {}
    scene = data.get("scene")
    if not scene or scene not in runtime.compiled.scenes:
        return jsonify({"ok": False}), 400
    runtime.set_scene(scene)
    return jsonify({
        "ok": True,
        "state": runtime.get_ui_state(),
        "ramp_ms": runtime.compiled.scene_ramp_ms,
    })


@app.route("/api/lights")
def api_get_lights():
    return jsonify({
        "lights": runtime.get_frontend_config(),
        "state": runtime.get_ui_state(),
    })


@app.route("/api/reeds/force", methods=["POST"])
def api_force_reed():
    if not _require_development_mode("force_reed"):
        return jsonify({"ok": False, "error": "development_mode required"}), 403
    data = request.get_json(silent=True) or {}
    name = data.get("name")
    if name is None:
        return jsonify({"ok": False, "error": "name required"}), 400
    state = runtime.force_reed(name, data.get("closed"))
    return jsonify({
        "ok": True,
        "state": state,
        "ramp_ms": state.get("_ramp_ms") or runtime.compiled.reed_ramp_ms,
        "reeds": runtime.get_reed_diag_json(),
        "effective": runtime.effective_reed_states(),
    })


@app.route("/api/reeds")
def api_get_reeds():
    diag = runtime.get_reed_diag_json()
    return jsonify({
        "reeds": runtime.get_reeds_frontend_config(),
        "states": runtime.effective_reed_states(),
        "raw": diag.get("states", {}),
        "forced": diag.get("forced", {}),
    })


def _screen_frontend_item(name: str, conf: dict, conn: dict | None = None) -> dict:
    """Build one screen record for the system tile."""
    from actuators.screens import brightness_is_adjustable

    observed_pct = 0
    if runtime.screen_actuator:
        observed_pct = runtime.screen_actuator._observed.get(name, 0)

    adjustable = brightness_is_adjustable(conf.get("brightness_path") or "")

    item = {
        "name": name,
        "label": conf.get("friendly", name),
        "icon": conf.get("icon", "fa-display"),
        "online": False,
        "latency": None,
        "on": observed_pct > 0,
        "brightness": None,
        "brightness_pct": observed_pct if observed_pct > 0 else None,
        "brightness_adjustable": adjustable,
        "follow_phases": bool(conf.get("follow_phases")),
        "phase_brightness": conf.get("phase_brightness") or {},
        "ssh_passwordless": False,
        "ssh_error": None,
    }
    if conn:
        if conn.get("on") is not None:
            item["on"] = conn["on"]
        item["online"] = conn.get("online", False)
        item["brightness"] = conn.get("brightness")
        if conn.get("brightness_pct") is not None:
            item["brightness_pct"] = conn["brightness_pct"]
        item["ssh_passwordless"] = conn.get("ssh_passwordless", False)
        item["ssh_error"] = conn.get("ssh_error")
    return item


def _screens_list(*, probe: bool = False) -> list:
    if not runtime.screen_actuator:
        return []
    screens = []
    for name, conf in runtime.compiled.screens.items():
        conn = None
        if probe:
            conn = runtime.screen_actuator.test_connectivity(name)
        screens.append(_screen_frontend_item(name, conf, conn))
    return screens


@app.route("/api/screens")
def api_get_screens():
    return jsonify({"screens": _screens_list()})


@app.route("/api/screens/status")
def api_get_screens_status():
    return jsonify({"screens": _screens_list(probe=True)})


def _cleanup_best_effort(timeout_s: float = 10) -> None:
    """Run cleanup without blocking shutdown if hardware teardown hangs."""
    try:
        worker = threading.Thread(target=cleanup, daemon=True, name="shutdown-cleanup")
        worker.start()
        worker.join(timeout=timeout_s)
        if worker.is_alive():
            logger.warning("Shutdown cleanup did not finish within %.0fs", timeout_s)
    except Exception as e:
        logger.error(f"Shutdown cleanup error: {e}")


def _issue_host_shutdown() -> bool:
    """Schedule host power-off. Never call this in tests without mocking."""
    try:
        subprocess.Popen(
            ["sudo", "-n", "shutdown", "-h", "now"],
            stdout=subprocess.DEVNULL,
            stderr=subprocess.DEVNULL,
            start_new_session=True,
        )
        logger.warning("Host shutdown command issued")
        return True
    except Exception as e:
        logger.error(f"Host shutdown failed: {e}")
        return False


@app.route("/api/system/shutdown", methods=["POST"])
def api_system_shutdown():
    """Shut down remote touchscreens, then this Pi."""
    logger.warning("System shutdown requested via API")

    def _shutdown_sequence():
        import time

        # Screens first: host power-off tears down the network and kills SSH.
        # shutdown_all() blocks until each remote attempt finishes (or times out).
        if runtime.screen_actuator:
            try:
                runtime.screen_actuator.shutdown_all()
            except Exception as e:
                logger.warning("Screen shutdown phase failed: %s", e)

        # Issue host shutdown before cleanup — GPIO factory.close() can hang
        # indefinitely and previously prevented shutdown from ever running.
        if not _issue_host_shutdown():
            return

        time.sleep(2)
        _cleanup_best_effort()

    threading.Thread(target=_shutdown_sequence, daemon=True, name="shutdown-host").start()
    return jsonify({"ok": True, "message": "Shutting down…"})


@app.route("/api/phases")
def api_get_phases():
    if not phase_manager:
        return jsonify({"phase": None, "forced": False, "times": {}, "settings": {}})
    times = {}
    settings = {}
    try:
        times = phase_manager.get_phase_times()
    except Exception:
        pass
    try:
        settings = phase_manager.get_timing_settings()
    except Exception:
        pass
    return jsonify({
        "phase": phase_manager.get_phase(),
        "forced": phase_manager.is_forced(),
        "times": times,
        "settings": settings,
    })


@app.route("/api/phases/timing", methods=["POST"])
def api_set_phase_timing():
    """Update [phases] day/evening offsets and night start hour."""
    if not phase_manager:
        return jsonify({"ok": False, "error": "Phase manager unavailable"}), 503

    data = request.get_json(silent=True) or {}
    kwargs = {}
    if "day_offset_minutes" in data:
        kwargs["day_offset_minutes"] = data.get("day_offset_minutes")
    if "evening_offset_minutes" in data:
        kwargs["evening_offset_minutes"] = data.get("evening_offset_minutes")
    if "night_start_minutes" in data:
        kwargs["night_start_minutes"] = data.get("night_start_minutes")
    elif "night_start_hour" in data:
        # Legacy hour-only clients.
        kwargs["night_start_hour"] = data.get("night_start_hour")

    if not kwargs:
        return jsonify({"ok": False, "error": "No timing fields provided"}), 400

    try:
        result = phase_manager.update_timing_settings(**kwargs)
    except ValueError as exc:
        return jsonify({"ok": False, "error": str(exc)}), 400
    except Exception as exc:
        logger.error("Phase timing update failed: %s", exc)
        return jsonify({"ok": False, "error": "Failed to update phase timing"}), 500

    return jsonify({"ok": True, "message": "Phase timing saved", **result})


def _ensure_homekit_manager():
    global homekit_module
    if homekit_module is None:
        homekit_module = HomeKitManager(runtime, config, socketio=socketio)
    return homekit_module


def _ensure_matter_manager():
    global matter_module
    if matter_module is None:
        matter_module = MatterManager(runtime, config, socketio=socketio)
    return matter_module
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

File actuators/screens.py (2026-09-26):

from __future__ import annotations

import logging
import re
import shlex
import subprocess
import threading
import time
from dataclasses import dataclass
from pathlib import Path
from typing import Callable, Dict, Optional, Union

from engine.screen_path import brightness_is_adjustable

logger = logging.getLogger("sccs")

_SCREEN_KNOWN_HOSTS = Path.home() / ".sccs" / "screen_known_hosts"

OnCommandFailed = Optional[Callable[[str], None]]


@dataclass(frozen=True)
class SysfsControl:
    path: str


@dataclass(frozen=True)
class DbusScreenSaverControl:
    service: str
    object_path: str


@dataclass(frozen=True)
class DbusKdeBrightnessControl:
    service: str
    object_path: str
    interface: str = "org.kde.ScreenBrightness.Display"


ScreenControl = Union[SysfsControl, DbusScreenSaverControl, DbusKdeBrightnessControl]

DEFAULT_KDE_BLANK_PATH = "/sys/class/graphics/fb0/blank"


def _ssh_options(timeout: int = 5) -> str:
    _SCREEN_KNOWN_HOSTS.parent.mkdir(parents=True, exist_ok=True)
    identity = Path.home() / ".ssh" / "sccs_screen"
    id_opt = f"-i {shlex.quote(str(identity))} -o IdentitiesOnly=yes " if identity.is_file() else ""
    return (
        f"-o BatchMode=yes -o ConnectTimeout={timeout} "
        f"-o StrictHostKeyChecking=accept-new "
        f"-o UserKnownHostsFile={_SCREEN_KNOWN_HOSTS} "
        f"{id_opt}"
        f"-o PreferredAuthentications=publickey"
    )


def _ssh_cmd(username: str, host: str, remote: str, timeout: int) -> str:
    return (
        f"ssh {_ssh_options(timeout)} "
        f"{shlex.quote(username)}@{shlex.quote(host)} {shlex.quote(remote)}"
    )


# Remote bash. __SCCS_MODE__ is replaced with dark or light before it is sent.
_COLOR_MODE_SCRIPT = r"""
MODE=__SCCS_MODE__
DARK=0
[ "$MODE" = "dark" ] && DARK=1
THEME=""
KIND=""

session_env() {
    uid=$(id -u)
    export XDG_RUNTIME_DIR="${XDG_RUNTIME_DIR:-/run/user/$uid}"
    if [ -z "${DBUS_SESSION_BUS_ADDRESS:-}" ] && [ -S "$XDG_RUNTIME_DIR/bus" ]; then
        export DBUS_SESSION_BUS_ADDRESS="unix:path=$XDG_RUNTIME_DIR/bus"
    fi
    if command -v systemctl >/dev/null 2>&1; then
        env_file=$(mktemp)
        systemctl --user show-environment >"$env_file" 2>/dev/null || true
        while IFS= read -r line; do
            case "$line" in
                DISPLAY=*|WAYLAND_DISPLAY=*|XDG_CURRENT_DESKTOP=*|DESKTOP_SESSION=*|XDG_SESSION_TYPE=*|XDG_SESSION_DESKTOP=*)
                    export "$line" 2>/dev/null || true
                    ;;
            esac
        done <"$env_file"
        rm -f "$env_file"
    fi
    if [ -z "${WAYLAND_DISPLAY:-}" ] && [ -S "$XDG_RUNTIME_DIR/wayland-0" ]; then
        export WAYLAND_DISPLAY=wayland-0
    fi
    if [ -z "${DISPLAY:-}" ] && [ -S /tmp/.X11-unix/X0 ]; then
        export DISPLAY=:0
    fi
}

set_ini_key() {
    file=$1
    section=$2
    key=$3
    value=$4
    mkdir -p "$(dirname "$file")"
    if [ ! -f "$file" ]; then
        printf '[%s]\n%s=%s\n' "$section" "$key" "$value" >"$file"
        return
    fi
    if grep -q "^${key}=" "$file"; then
        sed -i "s|^${key}=.*|${key}=${value}|" "$file"
    elif grep -q "^\[${section}\]" "$file"; then
        sed -i "/^\[${section}\]/a ${key}=${value}" "$file"
    else
        printf '\n[%s]\n%s=%s\n' "$section" "$key" "$value" >>"$file"
    fi
}

write_gtk_ini() {
    theme=$1
    prefer=0
    [ "$DARK" = 1 ] && prefer=1
    for file in "$HOME/.config/gtk-3.0/settings.ini" "$HOME/.config/gtk-4.0/settings.ini"; do
        [ -n "$theme" ] && set_ini_key "$file" Settings gtk-theme-name "$theme"
        set_ini_key "$file" Settings gtk-application-prefer-dark-theme "$prefer"
    done
}

scheme_file() {
    name=$1
    [ -f "/usr/share/color-schemes/${name}.colors" ] && return 0
    [ -f "$HOME/.local/share/color-schemes/${name}.colors" ] && return 0
    return 1
}

apply_kde() {
    wanted=""
    if [ "$DARK" = 1 ]; then
        candidates="BreezeDark BreezeDarkClassic"
    else
        candidates="BreezeLight BreezeClassic Breeze"
    fi
    listed=""
    if command -v plasma-apply-colorscheme >/dev/null 2>&1; then
        listed=$(plasma-apply-colorscheme --list-schemes 2>/dev/null | sed -E 's/[[:space:]]*\(current\)$//; s/^\*[[:space:]]*//')
    fi
    for name in $candidates; do
        if scheme_file "$name" || printf '%s\n' "$listed" | grep -qx "$name"; then
            wanted=$name
            break
        fi
    done
    if [ -z "$wanted" ] && [ -n "$listed" ]; then
        if [ "$DARK" = 1 ]; then
            wanted=$(printf '%s\n' "$listed" | grep -i dark | head -n 1)
        else
            wanted=$(printf '%s\n' "$listed" | grep -iv dark | head -n 1)
        fi
    fi
    [ -n "$wanted" ] || return 1
    if command -v plasma-apply-colorscheme >/dev/null 2>&1; then
        plasma-apply-colorscheme "$wanted" >/dev/null 2>&1 || true
    fi
    kw=""
    if command -v kwriteconfig6 >/dev/null 2>&1; then
        kw=kwriteconfig6
    elif command -v kwriteconfig5 >/dev/null 2>&1; then
        kw=kwriteconfig5
    fi
    if [ -n "$kw" ]; then
        "$kw" --file kdeglobals --group General --key ColorScheme "$wanted" >/dev/null 2>&1 || true
    fi
    if [ "$DARK" = 1 ] && [ -d /usr/share/themes/Breeze-Dark ]; then
        THEME=Breeze-Dark
    elif [ "$DARK" != 1 ] && [ -d /usr/share/themes/Breeze ]; then
        THEME=Breeze
    fi
    KIND=kde
    echo "$wanted"
}
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

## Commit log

2026-09-04 Update SCCS-RPI KiCad design and production files
    Add GPS RF ESD and matching (ESD103-B1-02EL, 27nH, 10R, 100nF),
    swap the 10A fuses to A16-1000, retune copper zone fills, and
    regenerate BOM, positions, netlist, gerbers, and schematics PDF.
    [1_wire_bus.kicad_sch, SCCS Bracket.3mf, SCCS-RPI.kicad_pcb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]
2026-09-04 Flash both ESP32s after one download-mode step
    Users put both MCUs into the bootloader together, so the installer
    now uploads ESP32-1 then ESP32-2, then asks for a single RESET/verify.
2026-09-05 Keep lighting UI in sync when reeds open
    Reed previews now become current UI/API state before hardware I/O, and the
    client ignores stale HTTP fetches plus stuck slider locks so a panel-open
    cannot leave the kitchen light showing off.
    [reconcile.py, runtime.py]
2026-09-05 Fix WS281X second data GPIO in sccs.conf.dist
    i2 silk is GND | GPIO 18 | GPIO 13. Output 2 was listed as GPIO 27,
    which is not connected on the Core.
2026-09-05 Update SCCS-RPI KiCad design and production files
    Split 5V and 3V3 regulation onto dedicated Power sheets with a second
    AP64501 buck, extra inductor and passives, update the enclosure
    bracket, and regenerate BOM, positions, netlist, gerbers, and
    schematics PDF.
    [1_wire_bus.kicad_sch, SCCS Bracket.3mf, SCCS Bracket.f3z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]
2026-09-24 Ship the installer fixes and the current camper UI.
    ESP first-run flash, Samba retry, Victron address scan, touchscreen filtering, SSH and 1-Wire setup. Lighting map, relay follow, home layout, and the System page field alignment.
    [config_compile.py, network.py, reconcile.py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]
2026-09-24 Update SCCS-RPI KiCad board, bracket, and production outputs.
    Move the 10A fuse values off the silkscreen onto the fab layer, move the
    1-10 minus label to the front silk, refill the copper zones, save the
    enclosure bracket as v6, and regenerate the IPC netlist and gerber zip.
    [SCCS Bracket.3mf, SCCS-RPI.kicad_pcb]
2026-09-24 Continue the installer in the SSH session after a restart.
    The UART reboot used to wait for someone to run a command by hand. The next login starts that session on the terminal, and the hook is removed when the install finishes.
2026-09-25 Restart sccs after installer config, and update the home tiles.
    Sensor, touchscreen, secret-key, Victron, and HomeKit steps restart the service when it is already running so the new sccs.conf is loaded. Sunrise and sunset labels line up with their times, with ico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
2026-09-25 Shrink the date tile icons and separate lighting relays.
    Sunrise and sunset icons are half height and centered on their label and time. The home lighting tile draws a line under the dimmers, then lists relays that are on.
2026-09-25 Swap the rear drawer and rooftop tent light outputs.
    Rear drawer now drives pin 1-11 and the rooftop tent drives pin 2-5.
2026-09-25 Keep the lighting thumb sliding when a light is switched on or off.
    The UI echo was cancelling the slide and snapping the thumb to the end. The switch handle also uses one translate form so it can move between off and on.
2026-09-25 Match each touchscreen desktop theme to the UI dark or light mode.
    KDE, Raspberry Pi OS, XFCE, and GNOME panels follow the colour scheme, including when day, evening, or night changes it.
2026-09-25 Log touchscreens in at boot and keep the display on.
    Menu 8 enables desktop autologin, opens the SCCS page in Chromium, and turns off idle blanking, dimming, and sleep on every configured Raspberry Pi OS or Armbian panel, including KDE Plasma.
2026-09-25 Pin the van LAN to the touchscreen port and match the kitchen bench night level.
    The LAN profile was an unpinned netplan connection, so a reboot could put 10.10.10.1 on the iPhone tether and leave the panel with no lease. Kitchen bench night is now 1% red, the same as the kitchen panel.
2026-09-25 Restore the Neumorphism highlight and finish the panel fixes.
    The kitchen card fade is the original halfway gradient again, and Chromium is not forced off the GPU. Closing the panel reed powers the screen off, the bench night level is 10% red, and a lighting thumb drag no longer opens the context menu. New installs suggest the enrolled Victron keys.
    [screens.py]
2026-09-25 Install and update UniFi OS Server with LAN setup, and move Pi-hole admin off the AP inform port.
2026-09-25 Release 1.2 with a smoother touchscreen UI and the daytime theme.
    Panel Chromium composites on the GPU and rasterizes on the CPU, so the Neumorphism shine stays a smooth ramp and page changes are not a two-frame jump. Chromium opens the control page once. Daytime c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
2026-09-26 Let each touchscreen opt into phase brightness, and open one SCCS tab.
    The installer stores kscreen DPMS as the panel power path, so a closed reed turns the screen off instead of dimming it. Each card has a "Change Brightness with Phases" checkbox. Off keeps an open reed at full brightness. On uses that screen's day, evening, and night levels. Chromium's homepage and startup page are the control UI, and the launcher no longer opens a second tab.
    [app.py, config_compile.py, precedence.py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]
